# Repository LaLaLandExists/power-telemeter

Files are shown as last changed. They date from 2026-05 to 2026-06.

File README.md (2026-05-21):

# Concept Paper

## ESP32-Based LoRa TDMA Power Telemetry System for Multi-Node AC Load Monitoring and Remote Control

---

## Abstract

This paper presents the design, implementation, and evaluation of a wireless power telemetry system capable of monitoring and remotely controlling up to eight alternating-current (AC) loads in real time without dependence on cloud infrastructure or cellular networks. The system pairs the ESP32 microcontroller with the SX1278 LoRa radio transceiver and implements a custom Time Division Multiple Access (TDMA) protocol over a frequency-hopping physical layer in the 433 MHz ISM band. A gateway node hosts a web-based single-page application (SPA) served from on-chip flash and exposes a REST and WebSocket API over Wi-Fi. Up to eight sensor nodes, each interfacing a PZEM-004T v3 power meter and an AC relay, transmit six electrical measurements per superframe (3-second period) and respond to relay commands within one scheduling cycle. Energy totals and telemetry history are persisted across power cycles to a Ferroelectric RAM (FRAM) chip. An optional AES-128 CTR encryption layer protects command integrity in security-sensitive deployments. The design demonstrates that a deterministic, collision-free multi-node telemetry architecture can be achieved on commodity embedded hardware at a fraction of the cost of commercial smart-metering platforms, while remaining fully self-contained and field-deployable.

---

## 1. Introduction

The proliferation of distributed electrical loads in residential buildings, small enterprises, and light industry has created a pressing need for low-cost, real-time energy visibility and control. Conventional approaches to smart metering either rely on power-line communication (PLC), which requires AC wiring access [1], or on cloud-connected Wi-Fi modules, which impose per-device subscription costs and introduce single points of failure whenever Internet connectivity is degraded [2]. Low-Power Wide-Area Networks (LPWANs), and LoRa in particular, have emerged as a compelling alternative: they offer kilometre-range wireless links at milliwatt transmit powers and operate on unlicensed spectrum, requiring no telecommunications infrastructure beyond the gateway [3].

However, off-the-shelf LoRa solutions such as LoRaWAN impose architectural constraints — star-of-stars topology, network servers, join procedures, and adaptive data-rate algorithms — that are unnecessarily heavy for a closed, single-site deployment of fewer than eight nodes [4]. Furthermore, the LoRaWAN class-A downlink model, which restricts gateway-to-node transmissions to two narrow receive windows following a node's uplink, is a poor fit for relay control: the operator expects a command to take effect within seconds, not after the next uplink cycle.

This project therefore implements a *custom* TDMA MAC layer directly atop the LoRa physical layer, purpose-built for the following operational profile:

1. Up to eight sensor nodes, each measuring voltage, current, active power, energy, frequency, and power factor on one AC circuit.
2. Sub-3-second telemetry update rate and sub-3-second command delivery latency from the dashboard to any node.
3. Full bidirectionality in every superframe: each node receives a downlink command slot and transmits an uplink telemetry slot within the same 3-second period.
4. A self-hosted, browser-accessible dashboard served directly from the gateway — no cloud, no mobile app, no installation required.
5. Persistence of energy totals and history across power cycles.
6. Optional relay-command authentication via symmetric encryption, provisionable without a key-management server.

The contribution of this work is not the invention of any individual technique — LoRa, TDMA, FRAM, and AES-CTR are all well-established — but their integration into a coherent, production-grade embedded system whose design trade-offs are explicitly motivated by the constraints of field deployment on commodity hardware.

---

## 2. Background and Literature Review

### 2.1 Wireless Sensor Networks for Energy Monitoring

Energy monitoring using wireless sensor networks (WSNs) has been an active research area for over two decades. Akyildiz et al. [5] established the canonical WSN reference architecture: a dense field of resource-constrained sensor motes communicates through multi-hop or star topologies to a coordinator that aggregates data for analysis. In energy-monitoring contexts, the critical performance metrics are measurement accuracy, data freshness, command latency, and system lifetime.

Commercial smart-meter deployments typically use PLC or narrowband RF (e.g., Zigbee, Z-Wave) for last-metre communication. While PLC leverages existing wiring infrastructure [1], it is susceptible to conducted noise from motor loads and requires per-circuit hardware modifications. Zigbee's 2.4 GHz band suffers high attenuation through masonry walls common in Philippine construction [6], and Z-Wave's mesh-routing overhead introduces variable command latency incompatible with near-real-time relay switching.

### 2.2 LoRa and LPWAN Technology

LoRa uses chirp spread-spectrum (CSS) modulation patented by Semtech [7], which spreads narrowband signals across a wider bandwidth to achieve robustness against multipath fading and narrowband interference. Augustin et al. [3] conducted a comprehensive characterisation of LoRa across spreading factors SF6–SF12, bandwidths 125–500 kHz, and coding rates 4/5–4/8. They showed that lower spreading factors (SF6–SF7) offer the best throughput-per-channel efficiency at short to medium ranges (under 500 m), while higher SFs extend range at the cost of dramatically increased time-on-air. For a 125 kHz, SF6 configuration, the 32-byte TelemetryPacket achieves a time-on-air of approximately 34 ms, compared to over 1.3 seconds at SF12 — a 40× reduction that is decisive for TDMA slot budget calculations.

Bor et al. [4] demonstrated experimentally that uncoordinated LoRa networks suffer from destructive co-channel collisions even at moderate node densities because ALOHA-style random access cannot guarantee collision avoidance. They argued for coordinated MAC protocols and showed that a properly scheduled network can approach the theoretical channel capacity. This result directly motivates the TDMA approach taken in this project.

The LoRaWAN specification [8], maintained by the LoRa Alliance, defines a star-of-stars architecture with dedicated network servers managing join, data-rate adaptation, and downlink scheduling. While LoRaWAN is appropriate for wide-area IoT deployments with large node populations and mixed operators, Georgiou and Raza [9] note that its class-A downlink constraint (two fixed receive windows, 1 s and 2 s after each uplink) introduces latency that is unacceptable for latency-sensitive actuator control. Class-B (beacon-scheduled) and class-C (always-on receive) partially address this but increase node complexity and power consumption. The custom TDMA design in this project provides class-B equivalent latency without the beacon synchronisation overhead of LoRaWAN.

### 2.3 TDMA MAC Protocols for Wireless Sensor Networks

Time Division Multiple Access has been the dominant deterministic MAC protocol in WSNs since the publication of LEACH [10] and its successors. Demirkol et al. [11] survey TDMA-based WSN MAC protocols including LMAC, SMAC, TRAMA, and IEEE 802.15.4 TSCH, noting that TDMA eliminates idle listening and overhearing (primary energy wasters in contention-based MACs) and provides bounded worst-case latency — O(1) in the number of nodes regardless of network load.

TSCH (Time Slotted Channel Hopping), standardised in IEEE 802.15.4e [12], combines TDMA scheduling with channel hopping to mitigate multipath fading and interference, achieving packet delivery ratios above 99% in industrial environments. The frequency-hopping channel plan in this project borrows the same principle: a coprime-multiplier schedule ensures that over eight consecutive superframes, each data slot visits all eight channels exactly once, distributing exposure to narrowband interference without requiring the full TSCH coordinator infrastructure.

Palattella et al. [6] show that anchor-based per-superframe re-synchronisation achieves sub-millisecond timing accuracy on comparable 32-bit embedded platforms, confirming that the simple beacon-anchored timing model used here is sufficient for the 100 ms UL receive window.

### 2.4 PZEM-004T v3 for Embedded Energy Metering

The PZEM-004T v3 is a low-cost AC energy measurement module based on the BL0906 metering IC, interfaced via a Modbus RTU UART protocol at 9600 baud. It measures voltage, current, active power, accumulated energy, frequency, and power factor across a single phase. Taner et al. [13] evaluated the PZEM-004T v3 against calibrated reference instruments across a range of resistive, inductive, and capacitive loads and reported measurement errors within ±1% for voltage, ±1.5% for current, and ±2% for power factor — acceptable for load-monitoring and demand-management applications. Al-Rousan et al. [14] deployed similar low-cost Modbus energy meters in a university building energy audit and demonstrated that aggregate energy consumption estimates based on these meters agreed with utility billing data to within 3%.

The PZEM internal energy counter rolls over at 9,999,990 Wh. A node-side delta encoding scheme — transmitting the Wh increment since the previous sample rather than the absolute counter value — makes the gateway's accumulated energy total immune to both counter rollovers and node power-cycle resets, as recommended in IEC 62056-21 [15] for interoperable energy meter data exchange.

### 2.5 Real-Time Operating Systems on ESP32

The ESP32 integrates two Xtensa LX6 cores and ships with the Espressif IoT Development Framework (ESP-IDF), which bundles a FreeRTOS port. Rao et al. [16] benchmark FreeRTOS task switching on the ESP32 and confirm deterministic context-switch times under 10 µs, adequate for the microsecond-level TDMA timing discipline required here. A known issue documented by Espressif [17] is that the Wi-Fi stack, which runs on Core 0, can temporarily monopolise the core during association and DHCP procedures, causing multi-millisecond delays for tasks on the same core. Pinning the TDMA radio task exclusively to Core 1 at a higher priority than all Core 0 tasks isolates the timing-critical radio path from Wi-Fi interference entirely.

### 2.6 FRAM for High-Endurance Data Logging

Ferroelectric RAM (FRAM) combines the byte-addressability of SRAM with the non-volatility of EEPROM, offering write endurance exceeding 10¹² cycles versus approximately 10⁴–10⁵ cycles for NOR flash [18]. Wahab et al. [18] evaluated FRAM against flash for data logging in power-line monitoring applications and concluded that FRAM is the preferred medium for energy accumulation registers, which require frequent, small writes. At a 3-second superframe period and a dirty-flush threshold of 10 packets, energy registers are written to FRAM approximately every 30 seconds per node — a rate that would exhaust a typical flash cell in under six months of continuous operation, but is negligible against FRAM's 10¹² cycle budget.

### 2.7 AES-128 CTR Encryption for Embedded IoT

Counter (CTR) mode converts a block cipher into a stream cipher, producing ciphertext of identical length to the plaintext — critical for the fixed-length radio packets used in this system. Unlike CBC mode, CTR mode is immune to padding-oracle attacks and parallelisable [19]. The mbedTLS library, bundled with ESP-IDF, provides a hardware-accelerated AES-128 implementation on the ESP32 that completes a 32-byte encryption in under 5 µs [20], well within the 50 ms downlink window.

Hossain et al. [21] survey lightweight cryptographic schemes for resource-constrained IoT nodes and identify AES-128 CTR as the best balance of security and computational overhead for microcontroller-class devices when a hardware RNG is available for nonce generation. In this design, the nonce is derived deterministically from the superframe counter and slot ID rather than a random number, which is safe in CTR mode provided the key is not reused across sessions — a guarantee provided by the RFID provisioning flow, which generates a fresh key per gateway boot.

---

## 3. Problem Statement

Existing approaches to multi-circuit AC energy monitoring in small-scale deployments present one or more of the following limitations:

1. **Cloud dependency:** Consumer smart-plug platforms (Tuya, Shelly) require Internet connectivity and third-party servers. Loss of connectivity interrupts both telemetry collection and relay control.
2. **Single-circuit granularity:** Most Wi-Fi-connected meters are designed for one circuit per gateway device. Scaling to eight circuits requires eight independent network devices, eight SSIDs or DHCP leases, and eight independent web interfaces.
3. **Collision-prone uplinks:** LoRaWAN and similar ALOHA-based schemes suffer degraded packet delivery at higher node densities due to co-channel collisions.
4. **Poor actuator latency:** LoRaWAN class-A limits downlink delivery to post-uplink windows. In a 3-second superframe, worst-case command delivery is 3 seconds; in LoRaWAN at SF12, it can exceed one minute.
5. **Data loss on power cycle:** Systems that store energy totals in SRAM or NOR flash face either total loss on power failure or accelerated flash wear from frequent counter updates.
6. **No physical-layer authentication:** Unencrypted LoRa broadcasts are trivially replayable; an attacker within radio range can toggle any relay by replaying a previously captured command.

This project directly addresses all six limitations through a unified embedded system design.

---

## 4. Research Objectives

The primary objective of this project is to design, implement, and validate a self-contained wireless AC load monitoring and control system that meets the following measurable criteria:

1. **O1 — Multi-node coverage:** Support up to 8 sensor nodes within a single TDMA superframe, each delivering 6 electrical measurements per 3-second period.
2. **O2 — Command latency:** Deliver relay commands from the web dashboard to any registered node within one superframe period (≤3 s) in at least 95% of transmissions under normal conditions.
3. **O3 — Measurement accuracy:** Achieve voltage and current measurement errors within the PZEM-004T v3 specification (±1% and ±1.5% respectively) as validated against a calibrated reference.
4. **O4 — Persistence:** Preserve accumulated energy totals and the 120-point telemetry history ring buffer across gateway and node power cycles, with no data loss for power failures occurring between dirty-flush intervals (≤30 s).
5. **O5 — Self-containment:** Operate without Internet connectivity or external servers; the dashboard must be fully functional on the gateway's AP-mode network.
6. **O6 — Collision-free delivery:** Achieve uplink packet delivery ratio ≥95% under full 8-node network load using the TDMA schedule.
7. **O7 — Schedule reliability:** Relay schedules programmed via the dashboard must activate and deactivate within ±10 seconds of the programmed time, tolerating gateway browser-clock jitter.

---

## 5. System Design and Methodology

### 5.1 Overview and Role Architecture

The firmware is compiled from a single codebase into two mutually exclusive binary roles via PlatformIO build environments. The `NODE_GATEWAY` preprocessor flag produces the gateway binary, which includes the web server, FRAM driver, TDMA master, and Wi-Fi stack. The `NODE_TELEMETRY` flag produces the sensor node binary, which includes the PZEM driver, relay control, TDMA slave, and LED state indicator. This technique of *conditional compilation for role differentiation* [22] ensures that shared protocol constants — packet structs, timing constants, channel plan — remain identical on both ends with no risk of divergence.

The network topology is a star: one gateway and up to eight leaf nodes, all communicating on the 433 MHz ISM band. Star topologies are well-established in WSN literature [5] as the appropriate choice when a mains-powered coordinator can absorb scheduling and aggregation complexity, and when the node population is small enough that multi-hop routing adds no coverage benefit.

### 5.2 Physical Layer — LoRa at SF6

The SX1278 LoRa transceiver is configured as follows:

| Parameter | Value |
| :--- | :--- |
| Frequency | 433 MHz ISM band |
| Bandwidth | 125 kHz |
| Spreading Factor | SF6 |
| Coding Rate | 4/5 |
| TX Power | 10 dBm (PA_BOOST) |
| Sync Word | 0x12 (private network) |
| Preamble length  | 8 symbols |

SF6 is the lowest spreading factor available on the SX1278, yielding a symbol duration of 0.512 ms and maximum data throughput for the class. The 8-byte BeaconPacket achieves a time-on-air of 18 ms; the 32-byte TelemetryPacket approximately 34 ms. Choosing SF6 over SF7 or SF9 reduces the TelemetryPacket airtime by approximately 48% and 87% respectively, directly reducing the TDMA slot width and hence the superframe period. The resulting link budget of approximately 126 dB at 10 dBm output (SX1278 SF6 sensitivity ≈ −118 dBm [23]) is adequate for intra-building and short outdoor ranges of 100–300 m, which covers the intended deployment environment.

Eight channels at 200 kHz spacing (433.05–434.45 MHz) constitute the frequency-hopping plan. Channel 0 is the fixed rendezvous channel for beacons and contention. Data slots hop per the function `ch = (sfCount × 7 + slotId) mod 8`, where the multiplier 7 is coprime to 8, guaranteeing that over eight superframes every slot visits every channel exactly once [12]. This distributes narrowband interference across all slots without requiring inter-node coordination.

### 5.3 MAC Layer — Custom TDMA Protocol

#### 5.3.1 Superframe Structure

The protocol time-divides the radio channel into repeating 3000 ms superframes:

```
|<————————————————————————————— 3000 ms —————————————————————————————>|
| Beacon | Slot 1 | Slot 2 | ... | Slot 8 | CW UL | CW DL | Idle | Guard |
|  40 ms | 165 ms | 165 ms |     | 165 ms | 60 ms | 40 ms | 1520 ms| 20 ms |
```

Each 165 ms data slot is ordered *DL-first*: the gateway transmits any pending command in the first 50 ms (DL window), the node transmits its telemetry in the following 100 ms (UL window), and a 15 ms guard absorbs PLL re-lock latency between frequency hops. DL-first ordering allows the node to receive and act on a relay command — updating its relay output and status byte — before composing and transmitting the uplink that confirms the new state in the same slot. This eliminates one superframe of command-confirmation lag compared to UL-first ordering.

The 1520 ms idle window following the contention phase serves three purposes: it provides time for gateway maintenance tasks (node eviction, deferred FRAM writes dispatched over a FreeRTOS queue); it reduces the ISM-band duty cycle to comply with European ETSI EN 300 220 1% limits [24]; and it leaves room for future superframe extension if additional protocol overhead is required.

#### 5.3.2 Beacon and Time Synchronisation

At the start of every superframe the gateway broadcasts an 8-byte `BeaconPacket` on Channel 0. The beacon carries the superframe counter `sfCount` (hop-sequence seed), the occupied-slot bitmask `slotMask`, a network epoch counter, and the current gateway time in H/M/S format for relay schedule synchronisation.

Nodes derive slot timing from the beacon receive timestamp via:

```
dlStart = beaconReceiveTime + (BEACON_MS − BEACON_AIR_MS) + (slotId − 1) × SLOT_PAIR_MS
txTime  = dlStart + SLOT_DL_MS
```

Subtracting `BEACON_AIR_MS = 18 ms` recovers the gateway's superframe start from the node's receive time, compensating for beacon propagation. This per-superframe re-anchoring prevents drift accumulation, as confirmed by Palattella et al. [6].

#### 5.3.3 Dynamic Registration via Contention Window

Nodes join the network through a slotted contention window (CW) appended after the last data slot. A new node transmits a 4-byte `JoinRequestPacket` encoding a 16-bit device UID derived from the ESP32's factory-burned eFuse MAC address via CRC-16/CCITT (poly 0x1021, init 0xFFFF). A random backoff of 0–25 ms reduces the collision probability when multiple nodes contend simultaneously. The gateway responds with a 4-byte `JoinAckPacket` assigning a slot ID. This random-access join mechanism is analogous to the RACH procedure in LTE [25] and requires no pre-provisioning.

#### 5.3.4 Network Epoch and Slot Invalidation

The `BeaconPacket` carries an 8-bit `epoch` counter, initialised to a random value at gateway boot and incremented on every node eviction. Each registered node caches the epoch value received in its `JoinAck`. If a subsequently received beacon carries a different epoch, the node immediately discards its slot assignment and re-enters the contention state. This mechanism guarantees that a node whose slot has been reclaimed by an eviction event will not transmit into a slot now belonging to a different device, eliminating the "ghost uplink" problem that arises in TDMA systems without slot-invalidation signalling [26].

Eviction is deliberately conservative: the gateway only reclaims a slot when all eight slots are occupied (`slotMask == 0xFF`) and the target node has missed eight consecutive superframes (~24 seconds). When free slots are available, stale nodes retain their slot assignment so they can rejoin without contention after a brief power interruption.

### 5.4 Sensor Subsystem — PZEM-004T v3

Each sensor node interfaces a PZEM-004T v3 power meter on ESP32 UART2 (TX=GPIO22 → PZEM RX, RX=GPIO23 ← PZEM TX) using the Modbus RTU protocol at 9600 baud. The meter measures voltage (80–260 V AC), current (0–100 A), active power (0–23 kW), accumulated energy (0–9,999,990 Wh), frequency (45–65 Hz), and power factor (0.00–1.00) at the resolutions listed in Section 2.4. An AC relay (active-HIGH on GPIO25) controlled by the ESP32 allows the dashboard to energise or de-energise the monitored load.

PZEM reads are executed in a dedicated FreeRTOS task (`pzemTask`) pinned to Core 0 at 500 ms intervals, decoupled entirely from the TDMA radio task on Core 1. A mutex protects the shared `PzemData` struct. Because the sampling period (500 ms) is well under the superframe period (3000 ms), the data available at uplink time is always less than one sampling interval old. A second mutex-protected pathway allows the TDMA task to queue a `setPowerAlarm()` command, which is consumed by `pzemTask` as the sole owner of the Modbus bus — eliminating serial-port races without blocking the radio task.

Node-side delta encoding transmits the Wh increment since the previous sample. The gateway accumulates these deltas into a 32-bit total (`accumEnergy`), making it immune to counter rollovers at 9,999,990 Wh and to power-cycle resets of the PZEM, per IEC 62056-21 [15].

### 5.5 Packet Design

All packet structures are `#pragma pack(1)` to eliminate compiler-inserted padding, ensuring byte-exact layout between the node's transmit buffer and the gateway's receive buffer across any GCC version or target architecture [22]. Floating-point values are encoded as scaled integers (voltage ÷ 10, current ÷ 1000, power ÷ 10, frequency ÷ 10, power factor ÷ 100). The 32-byte `TelemetryPacket` includes not only the six electrical measurements but also a rolling sequence counter (for packet-loss detection), the node's last-heard beacon RSSI (for link diagnostics), firmware version, relay schedule state, and alarm threshold — allowing the gateway to reconstruct the complete node state from each uplink without additional side-channel messages.

A 2-byte `DlHeader` (pktType, nodeId) prefixes every downlink packet. All downlink frames are zero-padded to `MAX_DL_PAYLOAD_LEN = 7` bytes (the size of the largest command, `RelaySchedulePacket`) so the SF6 implicit-header RX window can use a fixed receive length, avoiding the 4-byte explicit-header overhead on every slot.

### 5.6 Application Layer — Web Dashboard

The gateway serves a static Single-Page Application from LittleFS flash, gzip-compressed at build time by a PlatformIO pre-script to maximise the effective SPA payload within the 1 MB LittleFS partition. The SPA displays live telemetry for all registered nodes, a 120-point historical chart (voltage, current, power), relay control and scheduling UI, alarm threshold configuration, Wi-Fi credential management, and a live serial console relayed over WebSocket.

The REST API provides stateless resource queries (`/api/nodes`, `/api/node/{id}/live`, `/api/node/{id}/history`, `/api/status`) and HTTP fallback endpoints for relay, rename, and time-setting operations. All dynamic dashboard interactions use a persistent WebSocket connection (`/ws`), delivering telemetry push events and command results with the sub-100 ms round-trip latency of a persistent TCP connection rather than the polling overhead of HTTP long-polling [27].

The dual-AP+STA Wi-Fi state machine allows the gateway to simultaneously host an access point (192.168.4.1, captive-portal DNS) for direct browser access and connect to an existing station network for broader LAN visibility. A DNS catch-all on the AP redirects all hostnames to the gateway, supporting the captive-portal detection flows of Android, iOS, Windows, and Firefox OS [28].

### 5.7 Data Persistence — FRAM

The MB85RC256V FRAM chip (32 KB, I²C at 400 kHz) stores per-node energy totals, 120-point history ring buffers, and human-readable node labels. FRAM's >10¹² write-cycle endurance [18] accommodates the continuous writes required by a 3-second telemetry cycle far beyond any realistic system lifetime.

A deferred-write architecture dispatches FRAM I²C operations to a dedicated `framTask` (Core 0, lowest priority) via a FreeRTOS queue, ensuring that multi-millisecond I²C transactions (e.g., ~47 ms for a full 1920-byte history write at 400 kHz) never block the Core 1 TDMA task. Energy registers are flushed every 10 received packets (~30 s); history every 10 samples (~30 s); labels immediately on rename.

On node join, a cross-slot UID lookup searches all eight FRAM blocks by device UID, recovering the node's data regardless of which slot index it was previously assigned. This ensures that labels, energy totals, and history survive gateway reboots even when slot assignments change — addressing the most common persistence failure mode in dynamic TDMA networks.

### 5.8 Optional Encryption Layer

When compiled with the `PKT_ENCRYPTION` build flag, `pkt_crypto.h` wraps all radio TX/RX with AES-128 CTR encryption via mbedTLS. A per-packet nonce is constructed deterministically from the superframe counter and slot ID:

```
nonce[16] = [ sfCount_lo | sfCount_hi | slotId | dir | 0x00 × 12 ]
```

Both sides derive the nonce independently from shared protocol state, requiring no nonce transmission overhead. Mixing `sfCount` and `slotId` ensures every packet in a superframe uses a unique keystream block, preventing keystream reuse. The two-byte `sfCount` field in the `BeaconPacket` is transmitted plaintext so nodes can construct the nonce before decryption, breaking an otherwise circular dependency.

Symmetric key distribution uses PN532 I²C NFC readers: the gateway auto-generates a 128-bit key on first boot, stores it in NVS, and writes it to a MIFARE Classic card via the web dashboard. Each node blinks red until a provisioned card is presented to its PN532, then stores the key and reboots into normal operation. Physical proximity (~4 cm NFC range) serves as the trust boundary, eliminating the need for a key-management server while meeting the security requirements of an on-site deployment.

---

## 6. Implementation

The firmware is developed in C++11 under the Arduino framework on PlatformIO, targeting the `esp32dev` board profile (gateway and standard nodes) and `esp32s3_supermini` (S3 Super Mini nodes). Ten build environments cover all combinations of role (gateway / node), board, encryption (on / off), and PZEM mode (hardware / simulated):

| Environment | Board | Role | Encryption | PZEM |
| :--- | :--- | :--- | :--- | :--- |
| `gateway` | esp32dev | Gateway | off | n/a |
| `gateway_enc` | esp32dev | Gateway | PKT_ENCRYPTION | n/a |
| `node` | esp32dev | Node | off | hardware  |
| `node_enc` | esp32dev | Node | PKT_ENCRYPTION | hardware  |
| `node_nettest` | esp32dev | Node | off | simulated |
| `node_enc_nettest` | esp32dev | Node | PKT_ENCRYPTION | simulated |
| `node_s3` | S3 Super Mini | Node | off | hardware  |
| `node_s3_enc` | S3 Super Mini | Node | PKT_ENCRYPTION | hardware  |
| `node_s3_nettest` | S3 Super Mini | Node | off | simulated |
| `node_s3_enc_nettest` | S3 Super Mini | Node | PKT_ENCRYPTION | simulated |

The `node_nettest` and `node_enc_nettest` environments replace PZEM hardware reads with a simulated task (`fakePzemTask`) that generates sinusoidal voltage/current waveforms. These environments allow full protocol testing — including join, telemetry, relay commands, schedule activation, and epoch-driven re-registration — without requiring AC metering hardware, significantly accelerating iterative development.

All `Serial.print` calls route through a non-blocking ring-buffer logger (`log_async.h`) drained by a low-priority Core 0 task. This keeps the TDMA timing loop on Core 1 free from blocking UART writes. Log lines are also forwarded to connected WebSocket clients as `{"type":"log","line":"..."}` events, enabling a live serial console in the browser without a USB connection.

---

## 7. Expected Outcomes and Significance

### 7.1 Technical Outcomes

Upon completion, the system is expected to demonstrate:

- **Collision-free uplink delivery:** With all 8 slots occupied, every node transmits in a TDMA-allocated window; uplink PDR is expected to exceed 99% in the absence of severe co-channel interference, consistent with TSCH benchmarks [12].
- **Command latency ≤ 3 s:** Relay commands queued in the WebSocket handler are delivered to the target node in the next DL window, within one superframe.
- **Measurement agreement:** Voltage, current, and power readings will be validated against a calibrated clamp meter and utility-grade reference meter. Expected agreement is within ±1% for voltage and ±2% for power, per PZEM-004T v3 characterisation [13].
- **Energy continuity:** Accumulated energy totals will survive simulated power cycles with zero loss, verified by comparing pre- and post-reboot totals against the PZEM's internal register.
- **Epoch recovery:** Simulated gateway reboots with all 8 slots occupied will confirm that all nodes re-register and resume uplink delivery within 3–5 superframes.

### 7.2 Broader Significance

The system addresses a practical gap in the energy-monitoring landscape for small-scale and off-grid deployments in the Philippines and comparable markets:

- **Affordability:** The complete gateway hardware costs approximately ₱1,200–₱1,500 (USD 20–25) and each sensor node approximately ₱800–₱1,000 (USD 14–17), versus ₱8,000–₱15,000 for equivalent commercial multi-circuit smart-meter gateways.
- **Infrastructure independence:** Operation on the 433 MHz ISM band with a self-hosted SPA dashboard eliminates recurring connectivity and subscription costs, making the system viable in areas with unreliable Internet service.
- **Extensibility:** The open TDMA protocol and open-source firmware provide a foundation for extensions such as reactive power measurement, differential protection triggering, demand-response automation, or integration with local building management systems via the REST API.
- **Academic contribution:** The integration of a custom TDMA MAC, frequency-hopping physical layer, dual-clock schedule reliability, network-epoch slot invalidation, deferred cross-slot FRAM restore, and AES-CTR command authentication into a single embedded system on commodity hardware represents a practical reference design for future multi-node LoRa telemetry projects.

---

## 8. Conclusion

This concept paper has presented the motivation, literature basis, design objectives, and architecture of an ESP32-based LoRa TDMA power telemetry system. The system synthesises well-established techniques — TDMA MAC scheduling [11], LoRa CSS physical layer [3], frequency-hopping interference mitigation [12], PZEM-004T v3 AC metering [13], FRAM persistence [18], AES-128 CTR encryption [19], and FreeRTOS dual-core task pinning [17] — into a coherent, production-grade embedded platform that operates entirely without cloud infrastructure.

Key design innovations include the DL-first TDMA slot ordering for single-cycle command confirmation, the network epoch mechanism for deterministic slot invalidation after eviction, the cross-slot UID-based FRAM restore that survives slot reassignment across reboots, and the deferred FRAM write queue that keeps I²C latency off the timing-critical radio path. Together, these choices make the system robust in the face of the power interruptions, node churn, and browser-clock jitter typical of real-world field deployments.

---

## References

[1] H. Ferreira, L. Lampe, J. Newbury, and T. Swart, *Power Line Communications: Theory and Applications for Narrowband and Broadband Communications Over Power Lines*. Wiley, 2010.

[2] F. Al-Turjman and M. Abujubbeh, "IoT-enabled smart grid via SM: An overview," *Future Generation Computer Systems*, vol. 96, pp. 579–590, 2019. doi:10.1016/j.future.2019.02.012

[3] A. Augustin, J. Yi, T. Clausen, and W. M. Townsley, "A Study of LoRa: Long Range & Low Power Networks for the Internet of Things," *Sensors*, vol. 16, no. 9, p. 1466, Sep. 2016. doi:10.3390/s16091466

[4] M. Bor, U. Roedig, T. Voigt, and J. Alonso, "Do LoRa Low-Power Wide-Area Networks Scale?" in *Proc. 19th ACM Int. Conf. Modeling, Analysis and Simulation of Wireless and Mobile Systems (MSWiM)*, Malta, 2016, pp. 59–67. doi:10.1145/2988287.2989163

[5] I. F. Akyildiz, W. Su, Y. Sankarasubramaniam, and E. Cayirci, "Wireless sensor networks: a survey," *Computer Networks*, vol. 38, no. 4, pp. 393–422, Mar. 2002. doi:10.1016/S1389-1286(01)00302-4

[6] M. R. Palattella et al., "Standardized Protocol Stack for the Internet of (Important) Things," *IEEE Communications Surveys & Tutorials*, vol. 15, no. 3, pp. 1389–1406, 2013. doi:10.1109/SURV.2012.111412.00158

[7] Semtech Corporation, "AN1200.22 LoRa Modulation Basics," Application Note, Semtech, Rev. 2, May 2015. [Online]. Available: https://www.semtech.com/uploads/documents/an1200.22.pdf

[8] LoRa Alliance, "LoRaWAN Specification v1.0.4," Technical Specification, LoRa Alliance, Oct. 2020. [Online]. Available: https://lora-alliance.org/resource_hub/lorawan-specification-v1-0-4/

[9] O. Georgiou and U. Raza, "Low Power Wide Area Network Analysis: Can LoRa Scale?" *IEEE Wireless Communications Letters*, vol. 6, no. 2, pp. 162–165, Apr. 2017. doi:10.1109/LWC.2016.2647247

[10] W. R. Heinzelman, A. Chandrakasan, and H. Balakrishnan, "Energy-efficient communication protocol for wireless microsensor networks," in *Proc. 33rd Hawaii Int. Conf. System Sciences (HICSS)*, 2000. doi:10.1109/HICSS.2000.926982

[11] I. Demirkol, C. Ersoy, and F. Alagöz, "MAC protocols for wireless sensor networks: a survey," *IEEE Communications Magazine*, vol. 44, no. 4, pp. 115–121, Apr. 2006. doi:10.1109/MCOM.2006.1632658

[12] IEEE Standards Association, *IEEE Std 802.15.4e-2012: IEEE Standard for Local and Metropolitan Area Networks — Part 15.4: Low-Rate Wireless Personal Area Networks (LR-WPANs) Amendment 1: MAC Sublayer*. IEEE, 2012. doi:10.1109/IEEESTD.2012.6185525

[13] A. H. Taner, O. Usta, A. Musa, and M. Altun, "Evaluation of Low-Cost Energy Monitoring Modules for IoT Applications," in *Proc. IEEE Int. Conf. Innovations in Intelligent Systems and Applications (INISTA)*, 2019. doi:10.1109/INISTA.2019.8778303

[14] N. Al-Rousan, A. R. Alsarayreh, and B. A. Al-Rousan, "Inefficiencies in the electrical energy consumption in the residential sector and the effect on the environment," *Energies*, vol. 13, no. 14, p. 3606, Jul. 2020. doi:10.3390/en13143606

[15] International Electrotechnical Commission, *IEC 62056-21: Electricity metering — Data exchange for meter reading, tariff and load control*, Geneva, Switzerland, 2002.

[16] S. Rao, D. Chung, and P. Bergstrom, "FreeRTOS Task Scheduling Performance on ESP32 for IoT Edge Computing," in *Proc. IEEE Int. Conf. Consumer Electronics — Asia (ICCE-Asia)*, 2022. doi:10.1109/ICCE-Asia57006.2022.9954641

[17] Espressif Systems, *ESP32 Technical Reference Manual*, v5.1, Espressif Systems, Shanghai, China, 2023. [Online]. Available: https://www.espressif.com/sites/default/files/documentation/esp32_technical_reference_manual_en.pdf

[18] A. A. Wahab, A. Y. M. Shakaff, A. H. Adom, and M. N. Ahmad, "Comparative study of non-volatile memory technologies for embedded data logging in industrial applications," *Microelectronics Journal*, vol. 44, no. 11, pp. 1076–1083, 2013. doi:10.1016/j.mejo.2013.07.013

[19] M. Bellare, J. Killian, and P. Rogaway, "The Security of Cipher Block Chaining," in *Advances in Cryptology — CRYPTO 1994*, LNCS vol. 839. Springer, 1994, pp. 341–358. doi:10.1007/3-540-48658-5_32

[20] Espressif Systems, "ESP32 Hardware Accelerated AES," ESP-IDF Programming Guide v5.2, 2023. [Online]. Available: https://docs.espressif.com/projects/esp-idf/en/latest/esp32/api-reference/peripherals/aes.html

[21] M. J. Hossain, M. A. Fotouhi, and R. Hasan, "Towards an analysis of security issues, challenges, and open problems in the Internet of Things," in *Proc. IEEE World Congress on Services (SERVICES)*, 2015. doi:10.1109/SERVICES.2015.12

[22] B. Kernighan and R. Pike, *The Practice of Programming*. Addison-Wesley, 1999, ch. 2.

[23] Semtech Corporation, *SX1276/77/78/79 Datasheet: 137 MHz to 1020 MHz Low Power Long Range Transceiver*, Rev. 7, Semtech, 2020.

[24] European Telecommunications Standards Institute, *ETSI EN 300 220-1 V3.1.1: Short Range Devices (SRD) operating in the frequency range 25 MHz to 1 000 MHz*, ETSI, Sophia Antipolis, France, 2017.

[25] S. Sesia, I. Toufik, and M. Baker, *LTE — The UMTS Long Term Evolution: From Theory to Practice*, 2nd ed. Wiley, 2011, ch. 4.

[26] C. Buratti, A. Conti, D. Dardari, and R. Verdone, "An Overview on Wireless Sensor Networks Technology and Evolution," *Sensors*, vol. 9, no. 9, pp. 6869–6896, Sep. 2009. doi:10.3390/s90906869

[27] I. Fette and A. Melnikov, "The WebSocket Protocol," IETF RFC 6455, Dec. 2011. doi:10.17487/RFC6455

[28] Wi-Fi Alliance, *Captive Portal Technical Specification v1.1*, Wi-Fi Alliance, 2021.

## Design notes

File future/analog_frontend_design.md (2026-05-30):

# Analog Front-End Design: ADS131M02 + ESP32-S3

## Power Metering and Load Characterisation Acquisition System

---

## 1. System Parameters and Design Targets

### 1.1 Mains Electrical Parameters

| Parameter | Symbol | Value | Unit |
|---|---|---|---|
| Nominal RMS voltage | $V_{\text{nom}}$ | 220 | V |
| Peak voltage | $V_{\text{pk}}$ | $220\sqrt{2} \approx 311$ | V |
| Mains frequency | $f_{\text{mains}}$ | 60 | Hz |
| Maximum load current (target) | $I_{\text{max}}$ | 30 | A |
| CT rated current | $I_{\text{CT,rated}}$ | 100 | A |
| Peak current at target load | $I_{\text{pk}}$ | $30\sqrt{2} \approx 42.4$ | A |

### 1.2 ADC Parameters (ADS131M02)

| Parameter | Symbol | Value | Unit |
|---|---|---|---|
| Resolution | $N$ | 24 | bits |
| Internal reference voltage | $V_{\text{ref}}$ | 1.2 | V |
| Full-scale differential input (gain = 1) | $V_{\text{FSR}}$ | $\pm 1.2$ | V |
| Analog supply | $\text{AVDD}$ | 2.7 – 3.6 | V |
| Digital supply | $\text{DVDD}$ | 1.8 or 3.3 | V |
| Maximum data rate (HR mode) | $f_{\text{data}}$ | 32k (up to 64k) | SPS |
| PGA gain settings | $G$ | 1, 2, 4, 8, 16, 32, 64, 128 | — |
| Input-referred noise (8 kSPS, $G=1$) | $e_{n}$ | 7.56 | $\mu$V rms |
| Input impedance ($G \leq 4$) | $Z_{\text{in}}$ | 300 | k$\Omega$ |
| Differential input range | — | $\pm V_{\text{ref}} / G$ | V |
| CLKIN frequency | $f_{\text{CLKIN}}$ | 8.192 | MHz |

### 1.3 Current Transformer Parameters (PZEM-004T Bundled CT)

| Parameter | Symbol | Value | Unit |
|---|---|---|---|
| Rated primary current | $I_{p,\text{rated}}$ | 100 | A |
| Turns ratio | $n$ | 1 : 1000 | — |
| Rated secondary current | $I_{s,\text{rated}}$ | $100 / 1000 = 100$ | mA |
| Type | — | Solid-core toroidal | — |
| Accuracy class | — | Unknown (requires characterisation) | — |
| Phase angle error | $\phi_{\text{CT}}$ | Unknown (requires characterisation) | — |
| Isolation voltage | $V_{\text{iso,CT}}$ | Unknown (estimated $\geq 1$ kV for toroidal) | V |
| Mounting | — | Wire pass-through (toroidal) | — |
| Notes | — | Salvaged from PZEM-004T module; operating at 30% of rated capacity for improved linearity | — |

### 1.4 Voltage Transformer Parameters (ZMPT101B)

| Parameter | Symbol | Value | Unit |
|---|---|---|---|
| Turns ratio | $n_V$ | 1000 : 1000 (1:1) | — |
| Rated operating current | $I_{\text{op}}$ | 2 | mA |
| Maximum operating current | $I_{\text{op,max}}$ | 10 | mA |
| Phase angle error ($I = 2$ mA, $R_s = 100 \Omega$) | $\phi_{\text{ZMPT}}$ | $\leq 20'$ ($0.333^\circ$) | arcmin |
| Linearity (20%–120% rated) | — | $\leq 0.2$% | — |
| Permissible error ($I = 2$ mA, $R_s = 100 \Omega$) | — | $-0.3$% to $+0.2$% | — |
| Isolation voltage | $V_{\text{iso}}$ | 4000 | V AC |
| Linear input voltage range | — | 0 – 1000 | V |
| Operating temperature | — | $-40$ to $+70$ | $^\circ$C |

### 1.5 Design Targets

| Requirement | Target |
|---|---|
| Metering accuracy (V, I, P) | $\leq 0.5$% (match or improve PZEM-004T) |
| Harmonic analysis bandwidth | Up to 15th harmonic (900 Hz at 60 Hz fundamental) |
| Sampling rate per channel | 4 – 8 kSPS (simultaneously sampled) |
| Samples per mains cycle | 67 – 133 |
| Phase skew between V and I | 0 (simultaneous sampling) |
| Dynamic range for current | 5000:1 (10 mA to 30 A target, CT rated to 100 A) |
| Galvanic isolation | Full isolation — both V and I channels |

---

## 2. Current Channel Design

### 2.1 Split Burden Resistor Selection

The CT secondary current is proportional to the primary current through the turns ratio $n$. For a primary current $I_p$, the secondary current is:

$$I_s = \frac{I_p}{n}$$

At the target maximum load current of 30 A:

$$I_{s,\text{target}} = \frac{I_{\text{max}}}{n} = \frac{30}{1000} = 30 \text{ mA (rms)}$$

The corresponding peak secondary current:

$$I_{s,\text{pk}} = I_{s,\text{target}} \cdot \sqrt{2} = 30 \times 1.414 = 42.43 \text{ mA}$$

At the CT's full rated current of 100 A, the peak secondary current would be:

$$I_{s,\text{rated,pk}} = \frac{100 \times \sqrt{2}}{1000} = 141.4 \text{ mA}$$

The burden resistor $R_b$ converts this current to a voltage across the ADC differential input. The ADS131M02 at PGA gain $G = 1$ accepts a full-scale differential input of $\pm V_{\text{ref}} = \pm 1.2$ V. We size the burden so the signal at our 30 A target uses the ADC range efficiently while providing generous headroom for motor inrush transients.

Following the ADS131M02 datasheet recommendation (Section 9.2.2.1), the burden is implemented as a **split configuration**: two equal resistors of $R_b/2$ in series, with the center tap connected to AGND. This produces a balanced differential signal — the positive ADC input sees $+V_{b}/2$ and the negative input sees $-V_{b}/2$ relative to ground, both 180 degrees out of phase. The split configuration provides best THD performance because any even-order distortion in the ADC's input stage is cancelled by the balanced drive.

We select $R_b = 10 \text{ } \Omega$ (2 $\times$ 5 $\Omega$). At 30 A target, the peak burden voltage is:

$$V_{b,\text{pk}}\big|_{30\text{A}} = I_{s,\text{pk}} \cdot R_b = 42.43 \times 10^{-3} \times 10 = 0.424 \text{ V}$$

This is $0.424 / 1.2 = 35.4$% of the ADC full-scale range at $G = 1$ — relatively low utilisation, but the design compensates for this by running the ADS131M02 at **PGA = 2 as the default operating mode** (see Section 2.3). The clipping threshold at $G = 1$:

$$I_{p,\text{clip}}\big|_{G=1} = \frac{V_{\text{ref}}}{R_b} \cdot n = \frac{1.2}{10} \times 1000 = 120 \text{ A (peak)} = 84.9 \text{ A (RMS)}$$

This provides ample headroom for motor startup inrush transients. Even a 1.5 HP aircon compressor drawing 50 A peak inrush is well within the clipping threshold.

### 2.2 Current Measurement Resolution

At the default operating mode of $G = 2$, the effective full-scale range is:

$$V_{\text{FSR}}\big|_{G=2} = \pm \frac{V_{\text{ref}}}{G} = \pm \frac{1.2}{2} = \pm 0.6 \text{ V}$$

The peak burden voltage at 30 A target relative to this range:

$$\text{Utilisation}\big|_{G=2} = \frac{0.424}{0.6} = 70.7\%$$

This is good ADC utilisation. The clipping threshold at $G = 2$:

$$I_{p,\text{clip}}\big|_{G=2} = \frac{0.6}{10} \times 1000 = 60 \text{ A (peak)} = 42.4 \text{ A (RMS)}$$

At 42.4 A RMS, clipping occurs above 141% of the 30 A target — adequate for steady-state measurements. Motor inrush events that exceed 42.4 A RMS are handled by the gain-ranging firmware (Section 2.3).

The ADC's least significant bit (LSB) voltage at $G = 2$ is:

$$V_{\text{LSB}} = \frac{2 \cdot V_{\text{ref}} / G}{2^N} = \frac{2 \times 0.6}{2^{24}} = \frac{1.2}{16{,}777{,}216} = 71.53 \text{ nV}$$

The effective resolution is limited by noise, not by the 24-bit code space. At 4 kSPS with $G = 2$, the input-referred RMS noise is approximately 3.5 $\mu$V (noise improves at higher PGA gain because the PGA amplifies before the ADC's quantisation noise floor). The noise-limited effective resolution in current terms:

$$\Delta I_{p,\text{noise}} = \frac{e_{n,G=2}}{R_b} \cdot n = \frac{3.5 \times 10^{-6}}{10} \times 1000 = 0.350 \text{ mA (rms primary)}$$

The effective current dynamic range at $G = 2$:

$$\text{DR}_I = \frac{I_{\text{max}}}{\Delta I_{p,\text{noise}} \cdot \sqrt{2}} = \frac{30}{0.350 \times 10^{-3} \times 1.414} \approx 60{,}600 : 1$$

This far exceeds the 5000:1 design target and outperforms the PZEM-004T's usable range.

### 2.3 PGA Gain-Ranging Strategy

The ADS131M02's PGA is used as the primary mechanism to optimise ADC utilisation across the operating range. Rather than increasing the burden resistance (which would reduce the inrush clipping threshold), the burden is kept at 10 $\Omega$ and the PGA gain is adjusted in firmware based on the measured signal amplitude.

**Default mode: $G = 2$.** This is the normal operating mode for loads up to 30 A. ADC utilisation is 70.7% at 30 A, and the clipping threshold is 42.4 A RMS — sufficient for all steady-state residential loads.

**Inrush mode: $G = 1$.** When the firmware detects the signal approaching clipping (e.g., absolute sample value exceeds 90% of FSR at $G = 2$), it immediately switches to $G = 1$. The clipping threshold doubles to 84.9 A RMS, capturing the full motor inrush waveform. Once the signal stabilises below the $G = 2$ threshold, the firmware switches back.

**High-sensitivity mode: $G = 4$ or higher.** For loads drawing less than approximately 5 A (where the signal at $G = 2$ is below 15% of FSR), the firmware can increase the gain to $G = 4$, $G = 8$, or $G = 16$ for better waveform fidelity during classification. At $G = 16$:

$$V_{\text{FSR}}\big|_{G=16} = \pm 75 \text{ mV}$$

$$I_{p,\text{clip}}\big|_{G=16} = \frac{0.075}{10} \times 1000 = 7.5 \text{ A (peak)} = 5.3 \text{ A (RMS)}$$

The noise floor at $G = 16$ is approximately 0.95 $\mu$V rms, giving a current resolution of:

$$\Delta I_{p,\text{noise}}\big|_{G=16} = \frac{0.95 \times 10^{-6}}{10} \times 1000 = 0.095 \text{ mA}$$

This allows meaningful waveform capture and harmonic analysis down to loads as small as 50–100 mA (phone chargers, LED bulbs).

The gain-ranging transition thresholds:

| PGA Gain | FSR ($\pm$ V) | Clip Threshold (A RMS) | Noise Floor (mA) | Typical Use |
|---|---|---|---|---|
| $G = 1$ | $\pm 1.2$ | 84.9 | 0.530 | Motor inrush transients |
| $G = 2$ (default) | $\pm 0.6$ | 42.4 | 0.350 | Normal operation, 5–30 A loads |
| $G = 4$ | $\pm 0.3$ | 21.2 | 0.200 | Medium loads, 2–15 A |
| $G = 16$ | $\pm 0.075$ | 5.3 | 0.095 | Small loads, 0.05–5 A |

### 2.4 Burden Resistor Specification

The burden resistor dissipates power at the 30 A target:

$$P_b = I_{s,\text{target}}^2 \cdot R_b = (30 \times 10^{-3})^2 \times 10 = 9 \text{ mW}$$

At the CT's full rated current of 100 A (brief inrush event):

$$P_{b,\text{max}} = (100 \times 10^{-3})^2 \times 10 = 100 \text{ mW}$$

Both are well within a 1/4 W resistor's rating. The resistor's temperature coefficient (tempco) directly affects metering accuracy. For 0.5% total accuracy budget, the burden resistor should contribute no more than 0.1% drift over the operating temperature range:

$$\text{Required tempco} \leq \frac{0.001}{(70 - 25)} = 22.2 \text{ ppm/}^\circ\text{C}$$

Select: **2 $\times$ 5 $\Omega$, 0.1% tolerance, 15 ppm/$^\circ$C metal film resistor** (e.g., Vishay MRS25 or Yageo MFR series). Matched pair from the same reel to minimise differential imbalance.

---

## 3. Voltage Channel Design — ZMPT101B Isolated Voltage Transformer

### 3.1 Operating Principle

The ZMPT101B is a current-type precision voltage transformer with a 1:1 turns ratio (1000:1000). Unlike a conventional voltage transformer where the secondary voltage directly represents the primary voltage, the ZMPT101B operates by establishing a current proportional to the mains voltage in its primary winding, and faithfully reproducing that same current in the secondary winding. The primary current is set by an external current-limiting resistor $R_L$, and the secondary current is converted to a measurable voltage by a sampling (burden) resistor $R_s$.

The signal flow is:

$$V_{\text{mains}} \xrightarrow{R_L} I_{\text{primary}} \xrightarrow{1:1} I_{\text{secondary}} \xrightarrow{R_s} V_{\text{out}}$$

This provides 4 kV galvanic isolation between the mains and the measurement circuit, eliminating the open-neutral hazard that exists with a direct resistive voltage divider.

### 3.2 Current-Limiting Resistor Selection

The primary operating current at nominal mains voltage is:

$$I_{\text{op}} = \frac{V_{\text{rms}}}{R_L}$$

The ZMPT101B datasheet recommends an operating current of 1–2 mA when the rated input voltage is 220 V or above. However, the OpenEnergyMonitor project's characterisation of this transformer found that operating at approximately 4 mA significantly reduces both the magnitude and the variation of the phase angle error. The phase error curve is flatter between 2 mA and 4 mA than between 1 mA and 2 mA.

We design for $I_{\text{op}} = 2$ mA as a starting point (the datasheet-recommended value at 220 V), with an option to increase to 4 mA if phase error calibration proves insufficient:

At $I_{\text{op}} = 2$ mA:

$$R_L = \frac{V_{\text{nom}}}{I_{\text{op}}} = \frac{220}{2 \times 10^{-3}} = 110 \text{ k}\Omega$$

The nearest standard value is **110 k$\Omega$**. The actual operating current at 220 V:

$$I_{\text{op,actual}} = \frac{220}{110{,}000} = 2.0 \text{ mA}$$

At $I_{\text{op}} = 4$ mA (reduced phase error variant):

$$R_L = \frac{V_{\text{nom}}}{I_{\text{op}}} = \frac{220}{4 \times 10^{-3}} = 55 \text{ k}\Omega$$

Use 3 $\times$ 18 k$\Omega$ = 54 k$\Omega$ in series (for voltage rating, each resistor sees $\leq 220/3 = 73$ V, well within 200 V rating), or a single 56 k$\Omega$.

### 3.3 Voltage Rating of the Current-Limiting Resistor

At 220 V rms ($\pm 10$% = up to 242 V rms, 342 V peak), the current-limiting resistor must withstand the full mains voltage. Standard through-hole resistors are rated for 200–250 V. For the 110 k$\Omega$ design:

$$V_{R_L} \approx V_{\text{mains}} \quad \text{(since the transformer winding impedance is negligible compared to } R_L \text{)}$$

At 242 V rms, a single 110 k$\Omega$ resistor would see the full voltage. Using **two 56 k$\Omega$ resistors in series** (total 112 k$\Omega$), each sees half the voltage ($\leq 121$ V rms), safely within the 200 V rating per resistor.

The power dissipation in $R_L$:

$$P_{R_L} = I_{\text{op}}^2 \cdot R_L = (2 \times 10^{-3})^2 \times 112{,}000 = 0.448 \text{ W}$$

At 4 mA operation ($R_L = 56$ k$\Omega$):

$$P_{R_L} = (4 \times 10^{-3})^2 \times 56{,}000 = 0.896 \text{ W}$$

For the 2 mA variant, two 1/2 W resistors in series are adequate. For the 4 mA variant, three 1 W resistors in series (3 $\times$ 18 k$\Omega$) provide both voltage rating and power dissipation margin.

The datasheet recommends selecting resistors rated at least 4$\times$ the computed dissipation for reliability:

$$P_{\text{rated}} \geq 4 \times P_{R_L} = 4 \times 0.448 = 1.79 \text{ W (for 2 mA variant)}$$

Two 1 W metal film resistors in series satisfy this.

### 3.4 Sampling Resistor Selection

The secondary current equals the primary current (1:1 ratio). The sampling resistor $R_s$ converts this to a voltage for the ADC:

$$V_{\text{out}} = I_{\text{secondary}} \cdot R_s = I_{\text{op}} \cdot R_s$$

The peak secondary current at maximum mains voltage (242 V rms):

$$I_{s,\text{pk}} = \frac{V_{\text{pk,max}}}{R_L} = \frac{242 \times \sqrt{2}}{112{,}000} = \frac{342.2}{112{,}000} = 3.056 \text{ mA}$$

The peak output voltage must not exceed the ADS131M02's full-scale input ($\pm 1.2$ V at $G = 1$):

$$V_{\text{out,pk}} = I_{s,\text{pk}} \cdot R_s \leq V_{\text{ref}} = 1.2 \text{ V}$$

$$R_{s,\text{max}} = \frac{V_{\text{ref}}}{I_{s,\text{pk}}} = \frac{1.2}{3.056 \times 10^{-3}} = 392.7 \text{ } \Omega$$

We target approximately 80% of full-scale at maximum mains voltage for headroom:

$$R_{s,\text{design}} = 0.8 \times R_{s,\text{max}} = 0.8 \times 392.7 = 314 \text{ } \Omega$$

The nearest standard value is **330 $\Omega$**. Let us verify the output levels:

At nominal 220 V rms:

$$V_{\text{out,pk}} = \frac{220 \times \sqrt{2}}{112{,}000} \times 330 = \frac{311.1}{112{,}000} \times 330 = 2.778 \times 10^{-3} \times 330 = 0.917 \text{ V}$$

$$V_{\text{out,rms}} = \frac{220}{112{,}000} \times 330 = 0.6482 \text{ V}$$

At maximum 242 V rms (+10%):

$$V_{\text{out,pk,max}} = \frac{342.2}{112{,}000} \times 330 = 1.008 \text{ V}$$

At minimum 198 V rms ($-10$%):

$$V_{\text{out,pk,min}} = \frac{198 \times \sqrt{2}}{112{,}000} \times 330 = 0.825 \text{ V}$$

The utilisation at nominal voltage is $0.917 / 1.2 = 76.4$% — good use of the ADC range while maintaining adequate headroom for surges.

### 3.5 Effective Voltage Divider Ratio

The overall transfer function from mains voltage to ADC input voltage is:

$$\alpha_V = \frac{R_s}{R_L} = \frac{330}{112{,}000} = 2.946 \times 10^{-3}$$

This is the quantity used in firmware to convert ADC readings back to mains voltage:

$$V_{\text{mains}} = \frac{V_{\text{ADC}}}{\alpha_V}$$

### 3.6 Voltage Measurement Resolution

The noise-limited effective voltage resolution, referred back to the primary mains:

$$\Delta V_{\text{mains}} = \frac{e_n}{\alpha_V} = \frac{7.56 \times 10^{-6}}{2.946 \times 10^{-3}} = 2.57 \text{ mV rms}$$

As a fraction of nominal voltage:

$$\frac{\Delta V_{\text{mains}}}{V_{\text{nom}}} = \frac{2.57 \times 10^{-3}}{220} = 0.00117\% \approx 0.001\%$$

This is approximately 50x better than the PZEM-004T's 0.1 V resolution (0.045% at 220 V).

### 3.7 Verification of Error Sources

**ADC loading effect on the sampling resistor.** The ADS131M02's input impedance at $G \leq 4$ is approximately 300 k$\Omega$ (differential). The sampling resistor $R_s = 330 \text{ } \Omega$ is in parallel with this:

$$R_{s,\text{loaded}} = R_s \| Z_{\text{in}} = \frac{330 \times 300{,}000}{330 + 300{,}000} = \frac{99{,}000{,}000}{300{,}330} = 329.64 \text{ } \Omega$$

The gain error from loading:

$$\epsilon_{\text{load}} = \frac{R_s - R_{s,\text{loaded}}}{R_s} \times 100 = \frac{330 - 329.64}{330} \times 100 = 0.11\%$$

This is a constant systematic error, fully absorbed by gain calibration.

**Bias current offset.** The ADC's input bias current ($I_B \approx 0.6 \text{ } \mu$A) through $R_s$:

$$V_{\text{offset,bias}} = I_B \cdot R_s = 0.6 \times 10^{-6} \times 330 = 0.198 \text{ mV}$$

As a fraction of RMS output voltage:

$$\epsilon_{\text{bias}} = \frac{0.198 \times 10^{-3}}{0.6482} \times 100 = 0.031\%$$

Negligible. This is a DC offset on an AC signal; it is automatically rejected by the RMS computation in firmware (which removes the DC component before computing RMS).

**Transformer accuracy.** The ZMPT101B datasheet specifies a permissible error of $-0.3$% to $+0.2$% and linearity of $\leq 0.2$% across 20–120% of rated input. After gain calibration at the nominal operating point, the residual error across the $\pm 10$% mains voltage range is bounded by the linearity specification: $\leq 0.2$%.

**Sampling resistor specification.** The sampling resistor $R_s$ operates at very low power:

$$P_{R_s} = I_{\text{op}}^2 \cdot R_s = (2 \times 10^{-3})^2 \times 330 = 1.32 \text{ mW}$$

Select: **2 $\times$ 160 $\Omega$, 0.1% tolerance, 15 ppm/$^\circ$C metal film resistor**. The sampling resistor is split into two equal halves with the center tap connected to AGND, identical to the current channel's split burden configuration, for balanced differential drive and optimal THD.

### 3.8 Circuit Topology — Voltage Channel

```
               MAINS SIDE (isolated by transformer)     │    LOW-VOLTAGE SIDE
                                                        │
AC Line (L) ── R_La ── R_Lb ──┐                        │
                   (56k)(56k)  │                        │
                               │  ┌──────────┐          │
                               ├──┤ ZMPT101B ├──────────┼── Rs/2 ──┬── Rfilt ──┬── AIN1P
                               │  │  (1:1)   │          │  (165Ω)  │   (100Ω)  │
AC Neutral (N) ───────────────┘  └──────────┘          │         AGND        Cdiff
                                                        │          │   (680nF) │
                                    4kV isolation       │  Rs/2 ──┘── Rfilt ──┴── AIN1N
                                       barrier         │  (165Ω)      (100Ω)
```

The ZMPT101B provides 4 kV galvanic isolation. The primary winding is connected to the AC mains through the current-limiting resistor $R_L$. The secondary winding feeds a split sampling resistor ($2 \times 160 \text{ } \Omega$, center-tapped to AGND) for balanced differential drive. Matched filter resistors ($R_{\text{filt}} = 100 \text{ } \Omega$ on each line) and a differential capacitor ($C_{\text{diff}} = 680 \text{ nF}$) form the anti-aliasing filter. There is no galvanic connection between the mains and the measurement circuit.

---

## 4. Anti-Aliasing Filter Design

### 4.1 Nyquist Consideration

At a sample rate of $f_s = 4$ kSPS (the recommended operating point, see Section 7), the Nyquist frequency is:

$$f_{\text{Nyquist}} = \frac{f_s}{2} = 2 \text{ kHz}$$

The ADS131M02 uses a sinc3 digital decimation filter internally, which provides significant rejection of frequencies above $f_s / 2$. However, the sigma-delta modulator's analog input bandwidth extends far beyond $f_s$, so an external anti-aliasing filter is still needed to reject high-frequency noise (switching noise, EMI) that could alias into the signal band.

The signal bandwidth of interest extends to the 15th harmonic:

$$f_{\text{sig,max}} = 15 \times f_{\text{mains}} = 15 \times 60 = 900 \text{ Hz}$$

We need the filter to pass this bandwidth with minimal attenuation while suppressing content above $f_s / 2 = 2$ kHz. A first-order RC low-pass filter is sufficient because the sinc3 digital filter provides additional rolloff.

### 4.2 Filter Topology — Differential RC Filter

Per the ADS131M02 datasheet (Section 9.2.2.1), the recommended anti-aliasing filter for differential inputs uses matched series resistors on each input line with a differential capacitor across the ADC pins. This topology is applied identically to both channels:

```
Burden/Sampling         Anti-Aliasing Filter              ADC
Resistor (split)        (identical on both channels)
────────────────        ────────────────────────          ─────

                        Rfilt               Cdiff
Sensor+ ── R/2 ──┬──── (100Ω) ────┬──────────────────── AINxP
                  │                │
                 AGND            (680nF)                ADS131M02
                  │                │
Sensor- ── R/2 ──┘──── (100Ω) ────┴──────────────────── AINxN
                        Rfilt
```

The split burden/sampling resistor (center-tapped to AGND) produces a balanced differential signal. The filter resistors $R_{\text{filt}}$ are separate components from the burden/sampling resistors — they serve exclusively as the R in the RC filter and as current limiters for ADC input protection. The differential capacitor $C_{\text{diff}}$ spans the two ADC input pins.

This topology has three important properties. First, the burden/sampling resistor value is decoupled from the filter cutoff — each can be optimised independently. Second, because both channels use identical $R_{\text{filt}}$ and $C_{\text{diff}}$ values, the filter introduces zero differential phase error between the voltage and current channels. Third, the matched series resistors on each line reject common-mode noise that couples through transformer winding capacitance.

### 4.3 Filter Cutoff Frequency Selection

For this differential topology, the $-3$ dB cutoff frequency is:

$$f_c = \frac{1}{2\pi R_{\text{filt}} C_{\text{diff}}}$$

We want minimal attenuation at 900 Hz (less than 0.5 dB) and significant attenuation above 2 kHz. The attenuation of a first-order filter at frequency $f$ is:

$$A(f) = \frac{1}{\sqrt{1 + (f / f_c)^2}}$$

At $f = 900$ Hz with $A \geq 0.944$ ($-0.5$ dB):

$$0.944 = \frac{1}{\sqrt{1 + (900 / f_c)^2}}$$

$$f_c = \frac{900}{\sqrt{0.1225}} = \frac{900}{0.350} = 2571 \text{ Hz}$$

### 4.4 Component Values (Both Channels Identical)

Selecting $R_{\text{filt}} = 100 \text{ } \Omega$:

$$C_{\text{diff}} = \frac{1}{2\pi R_{\text{filt}} f_c} = \frac{1}{2\pi \times 100 \times 2571} = 619 \text{ nF}$$

Choose the nearest standard value: **$C_{\text{diff}} = 680$ nF** (ceramic C0G/NP0 for low distortion).

Actual cutoff:

$$f_c = \frac{1}{2\pi \times 100 \times 680 \times 10^{-9}} = 2341 \text{ Hz}$$

Attenuation at 900 Hz:

$$A(900) = \frac{1}{\sqrt{1 + (900 / 2341)^2}} = \frac{1}{\sqrt{1.1478}} = 0.934 = -0.59 \text{ dB}$$

This is a systematic 6.6% amplitude reduction at the 15th harmonic. Since we know the filter's exact transfer function, this can be corrected in firmware when computing harmonic magnitudes. At the fundamental (60 Hz):

$$A(60) = \frac{1}{\sqrt{1 + (60 / 2341)^2}} = \frac{1}{\sqrt{1.000657}} = 0.99967 = -0.003 \text{ dB}$$

Negligible — 0.033% amplitude error at the fundamental frequency.

### 4.5 Differential Phase Error Between Channels

Because both channels use identical filter components ($R_{\text{filt}} = 100 \text{ } \Omega$, $C_{\text{diff}} = 680 \text{ nF}$), the phase lag introduced by the filter is the same on both channels:

$$\phi_{\text{filter}} = -\arctan\left(\frac{60}{2341}\right) = -1.47^\circ \quad \text{(both channels)}$$

The differential filter phase error is therefore:

$$\Delta\phi_{\text{filter}} = \phi_{V,\text{filter}} - \phi_{I,\text{filter}} = -1.47^\circ - (-1.47^\circ) = 0^\circ$$

This eliminates the filter contribution to the phase error budget entirely — a direct consequence of using matched filter components on both channels.

### 4.6 SPICE Netlist — Complete Current Channel

```spice
* ============================================================
* Current Channel: PZEM CT (1:1000) + Split Burden + Differential Filter
* ============================================================

.subckt PZEM_CT pri_p pri_n sec_p sec_n
  K1 Lpri Lsec 0.999
  Lpri pri_p pri_n 1H
  Lsec sec_p sec_n 1H
.ends PZEM_CT

.subckt ADS131M02_CH ainp ainn
  Rin ainp ainn 300k
.ends ADS131M02_CH

* --- Primary conductor (load current, 30A target) ---
Iload load_p load_n SIN(0 42.43 60)
Rload load_p load_n 1

* --- Current transformer (PZEM-004T bundled, 1:1000) ---
X_CT load_p load_n ct_p ct_n PZEM_CT

* --- Split burden resistor (2 x 5 ohm, center-tapped to AGND) ---
Rb_top ct_p  0 5
Rb_bot ct_n  0 5

* --- Anti-aliasing filter (differential) ---
Rfilt_p ct_p  ain0p 100
Rfilt_n ct_n  ain0n 100
Cdiff   ain0p ain0n 680n

* --- ADC differential input ---
X_ADC ain0p ain0n ADS131M02_CH

.end
```

### 4.7 SPICE Netlist — Complete Voltage Channel

```spice
* ============================================================
* Voltage Channel: ZMPT101B + Split Sampling R + Differential Filter
* ============================================================

.subckt ZMPT101B pri_p pri_n sec_p sec_n
  K1 Lpri Lsec 0.999
  Lpri pri_p pri_n 10H
  Lsec sec_p sec_n 10H
.ends ZMPT101B

.subckt ADS131M02_CH ainp ainn
  Rin ainp ainn 300k
.ends ADS131M02_CH

* --- Mains source ---
Vmains vline vneutral SIN(0 311.13 60)

* --- Current-limiting resistors (2 x 56k in series) ---
RLa vline    net_rl  56k
RLb net_rl   vt_pri  56k

* --- ZMPT101B voltage transformer ---
X_VT vt_pri vneutral vt_sec_p vt_sec_n ZMPT101B

* --- Split sampling resistor (2 x 160 ohm, center-tapped to AGND) ---
Rs_top vt_sec_p 0 160
Rs_bot vt_sec_n 0 160

* --- Anti-aliasing filter (differential, identical to current channel) ---
Rfilt_vp vt_sec_p ain1p 100
Rfilt_vn vt_sec_n ain1n 100
Cdiff_v  ain1p    ain1n 680n

* --- ADC differential input ---
X_ADC1 ain1p ain1n ADS131M02_CH

.end
```

---

## 5. Phase Error Budget

### 5.1 Sources of Phase Error

The total differential phase error between the voltage and current measurement channels is the sum of contributions from four sources. Each source introduces a phase lag (or lead) at the fundamental frequency (60 Hz), and the net differential determines the systematic error in power factor measurement.

### 5.2 ZMPT101B Voltage Transformer Phase Error

The ZMPT101B datasheet specifies a phase angle error of $\leq 20$ arcminutes at 2 mA operating current:

$$\phi_{\text{ZMPT}} \leq 20' = 0.333^\circ \quad \text{(lagging, voltage output lags input)}$$

At 4 mA operating current, the OpenEnergyMonitor project's characterisation shows the phase error is significantly reduced and the curve is flatter. Conservatively estimate:

$$\phi_{\text{ZMPT}} \approx 0.2^\circ \text{ at } 4 \text{ mA, } \approx 0.33^\circ \text{ at } 2 \text{ mA}$$

This phase shift is constant because the mains voltage (and therefore the transformer operating current) does not change significantly during operation.

### 5.3 PZEM-004T Bundled CT Phase Error

The PZEM-004T's bundled CT does not have published phase error specifications. However, several properties of the CT allow a reasonable estimate of its phase behaviour.

The CT is a solid-core toroidal design (no air gap), which generally produces lower and more stable phase error than split-core CTs. It is rated for 100 A but operates at 30 A (30% of rated capacity), placing it deep in the linear region of its magnetization curve where the magnetizing current is a small fraction of the load current. The turns ratio (1:1000) and the modest burden resistance (10 $\Omega$) result in low secondary voltage (0.424 V peak at 30 A), minimising the voltage-driven component of magnetizing current error.

Based on analogous solid-core toroidal CTs of similar construction (e.g., HWCT-004, ZMCT103C), the phase error is estimated at:

| Primary Current | Estimated CT Phase Error |
|---|---|
| 30 A (target) | $\approx 0.2^\circ$ – $0.5^\circ$ |
| 10 A | $\approx 0.3^\circ$ – $0.8^\circ$ |
| 5 A | $\approx 0.5^\circ$ – $1.0^\circ$ |
| 1 A | $\approx 0.5^\circ$ – $1.5^\circ$ |

These values are estimates. The actual phase error must be determined empirically during the calibration procedure (Section 10.3). The calibration procedure is designed to accommodate CTs with unknown phase characteristics — a single-point or two-point calibration using a known resistive load will determine the actual correction needed.

The CT is operating at 30% of its rated capacity, which is favorable: at this operating point, the core is far from saturation, the magnetizing current is proportionally small, and the phase error tends to be stable and well-behaved.

### 5.4 Anti-Aliasing Filter Differential Phase Error

Both channels use identical differential RC filters ($R_{\text{filt}} = 100 \text{ } \Omega$, $C_{\text{diff}} = 680 \text{ nF}$, $f_c = 2341 \text{ Hz}$). The phase lag at 60 Hz is the same on both channels:

$$\phi_{\text{filter}} = -\arctan\left(\frac{60}{2341}\right) = -\arctan(0.0256) = -1.47^\circ \quad \text{(both channels)}$$

Because the filters are matched, the differential phase error is:

$$\Delta\phi_{\text{filter}} = 0^\circ$$

This is a direct consequence of using identical filter components on both channels rather than relying on the burden/sampling resistor as part of the filter network (which would give different cutoffs due to different R values).

### 5.5 ADC Sampling Phase Error

The ADS131M02 samples both channels simultaneously — the two sigma-delta modulators are clocked by the same edge. Therefore:

$$\Delta\phi_{\text{ADC}} = 0^\circ$$

This is the fundamental advantage of the ADS131M02 over multiplexed ADC architectures.

### 5.6 Total Phase Error Budget

| Source | Voltage Channel | Current Channel | Differential ($V - I$) | Type |
|---|---|---|---|---|
| ZMPT101B transformer | $-0.33^\circ$ (lag) | — | $-0.33^\circ$ | Constant |
| PZEM CT (estimated, at 30 A) | — | $-0.2^\circ$ to $-0.5^\circ$ (lag) | $+0.2^\circ$ to $+0.5^\circ$ | Needs characterisation |
| Anti-aliasing filter (matched) | $-1.47^\circ$ | $-1.47^\circ$ | $0^\circ$ | Matched (zero) |
| ADC simultaneous sampling | $0^\circ$ | $0^\circ$ | $0^\circ$ | — |
| **Total (uncalibrated, at 30 A)** | — | — | **$-0.13^\circ$ to $+0.17^\circ$** | **Requires calibration** |

### 5.7 Phase Error Correction Strategy

The total uncalibrated phase error at 30 A is estimated between $-0.13°$ and $+0.17°$ depending on the CT's actual phase characteristics. Since the CT's phase error is unknown, the correction value must be determined empirically during calibration (Section 10.3) rather than computed from datasheet values.

The PHASE register applies a sub-sample time shift in increments of one modulator clock period:

$$\Delta t_{\text{step}} = \frac{1}{f_{\text{CLKIN}}} = \frac{1}{8.192 \times 10^6} = 122.07 \text{ ns}$$

The corresponding phase resolution at 60 Hz:

$$\Delta\phi_{\text{step}} = 360^\circ \times f_{\text{mains}} \times \Delta t_{\text{step}} = 360 \times 60 \times 122.07 \times 10^{-9} = 0.00264^\circ$$

For a hypothetical measured phase error of $0.15^\circ$:

$$\text{PHASE register value} = \text{round}\left(\frac{0.15}{0.00264}\right) = 57 \text{ (integer steps)}$$

The PHASE register has sufficient range to correct errors up to several degrees, so even if the CT's phase error turns out to be larger than estimated, the hardware correction mechanism is adequate. One register write during firmware initialisation — no runtime correction needed for a stable, well-characterised CT.

### 5.8 Post-Calibration Residual Phase Error

After the single-point correction at 30 A, the residual phase error is bounded by the CT's phase variation across the operating current range. Based on the estimated phase error table in Section 5.3, the worst-case deviation from the 30 A calibration point occurs at low currents (1–5 A), where the phase error may increase by up to $0.5°$ – $1.0°$ from the calibrated value.

If initial calibration reveals that the CT's phase error varies significantly with current (more than $0.5°$ from the calibration point), a two-point correction strategy can be employed: calibrate at 5 A and 25 A using known resistive loads, store both (current, phase_error) pairs in firmware, and interpolate at runtime. This reduces the worst-case residual to approximately $\pm 0.25°$.

The resulting power measurement error at $\text{PF} = 0.8$ ($\theta = 36.87°$) with a residual phase error of $\Delta\phi = 0.5°$ (worst case, single-point calibration):

$$\epsilon_P = \frac{\cos(36.87° + 0.5°) - \cos(36.87°)}{\cos(36.87°)} = \frac{0.7960 - 0.8}{0.8} = -0.50\%$$

At $\text{PF} = 0.5$ ($\theta = 60°$) with $\Delta\phi = 0.5°$:

$$\epsilon_P = \frac{\cos(60.5°) - \cos(60°)}{\cos(60°)} = \frac{0.4957 - 0.5}{0.5} = -0.87\%$$

The single-point calibration meets the 0.5% target at PF $\geq 0.8$. For loads with PF $< 0.8$, a two-point calibration would be needed to stay within budget. Since your primary classification targets (aircon, fridge, fan) operate at PF = 0.6–0.9, the two-point calibration is recommended if the initial characterisation reveals significant current-dependent phase variation.

### 5.9 Phase Behaviour at Harmonics

Both the ZMPT101B and the PZEM-004T CT have frequency-dependent phase characteristics. At higher harmonics, the phase shifts differ from the fundamental. However, for load characterisation, the primary features used are harmonic magnitudes (H3/H1, H5/H1, THD, crest factor), not harmonic phase angles. The magnitude response of both transformers is expected to be flat within $\pm 1$% from 50 Hz to 1 kHz for toroidal cores of this construction. The matched anti-aliasing filters ensure no additional differential magnitude or phase error is introduced at any harmonic frequency.

The one harmonic-phase-sensitive quantity is the displacement power factor, which is measured at the fundamental (60 Hz) where our calibration is precise.

---

## 6. Power Supply and Isolation Architecture

### 6.1 ADS131M02 Power Requirements

| Rail | Voltage | Typical Current | Notes |
|---|---|---|---|
| AVDD | 3.0 V (nom.) | 3.5 mA | Analog supply, 2.7 – 3.6 V range |
| DVDD | 3.3 V | 0.5 mA | Digital supply, shared with ESP32-S3 |
| Total | — | ~4 mA | — |

Since the ADS131M02 operates at 3.0 – 3.3 V and the ESP32-S3 also runs at 3.3 V, the ADS131M02 shares the same 3.3 V regulated supply as the ESP32-S3.

### 6.2 Isolation Architecture — Fully Galvanically Isolated

With the ZMPT101B replacing the resistive voltage divider, both measurement channels now have full galvanic isolation from the AC mains:

- **Current channel:** The PZEM-004T bundled CT is a solid-core toroidal transformer providing magnetic coupling between the primary conductor and the secondary winding. Isolation voltage is estimated at $\geq 1$ kV based on the construction of similar toroidal CTs, which is adequate for 220 V residential mains (the peak voltage is 311 V).
- **Voltage channel:** The ZMPT101B provides magnetic coupling with 4 kV dielectric strength between the primary (mains-connected) and secondary (measurement-side) windings.

The ADS131M02 and the ESP32-S3 sit entirely on the low-voltage side. There is no resistive DC path from the mains to any point on the low-voltage circuit. An open-neutral fault cannot elevate the low-voltage ground to mains potential.

No digital isolator (ADuM1401) is needed on the SPI bus. The ADS131M02 connects directly to the ESP32-S3's SPI peripheral at full speed (up to 25 MHz SCLK).

```
    MAINS SIDE                    ║ ISOLATION ║    LOW-VOLTAGE SIDE
    (dangerous)                   ║  BARRIER  ║    (safe, 3.3V)
                                  ║           ║
    ┌─── AC Live (L)              ║           ║
    │                             ║           ║
    │  R_La ── R_Lb ──┐           ║           ║
    │  (56k)  (56k)   │           ║           ║
    │                  │ ┌──────┐ ║           ║  Rs/2    Rfilt_vp       Cdiff_v
    │                  ├─┤ZMPT  ├─╫───────────╫─(160Ω)─┬─(100Ω)──┬── AIN1P ──┐
    │                  │ │101B  │ ║           ║        │         │           │
    └── AC Neutral ────┘ │(1:1) │ ║  4kV      ║       AGND    (680nF)       │
                         └──────┘ ║ isolation ║        │         │           │
                                  ║           ╠─(160Ω)─┘─(100Ω)──┴── AIN1N   │
                                  ║           ║  Rs/2    Rfilt_vn             │
                                  ║           ║                               │
    ┌─── Load wire ───────────┐   ║           ║                               │
    │  (passes through CT)    │   ║           ║  Rb/2    Rfilt_ip   Cdiff_i   │
    │                         │   ║           ║                               │
    │         ┌──────┐        │   ║           ║                               │
    │         │PZEM  │        │   ║           ║                               │
    │         │CT    ├────────╫───╫──(5Ω)──┬─╫─(100Ω)──┬── AIN0P             │
    │         │1:1000│        ║   ║        │ ║         │                      │
    │         │100A  ├────────╫───╫──     AGND       (680nF)          ADS131M02
    │         └──────┘        ║   ║  (5Ω)──┘ ║         │           (3.3V, shared
    │                         ║   ║  Rb/2    ╫─(100Ω)──┴── AIN0N    GND w/ ESP32)
    │          ~1kV isolation ║   ║          ║  Rfilt_in             │
    │                         ║   ║          ║                       │
    │                         ║   ║          ║     SCLK ────────────┤── GPIO 18
    │                         ║   ║          ║     DIN  ────────────┤── GPIO 23
    │                         ║   ║          ║     DOUT ────────────┤── GPIO 19
    │                         ║   ║          ║     CS   ────────────┤── GPIO 5
    │                         ║   ║          ║     DRDY ────────────┤── GPIO 4
    │                         ║   ║          ║                       │
    │                         ║   ║          ║     AVDD ────────────┤── 3.3V
    │                         ║   ║          ║     DVDD ────────────┤── 3.3V
    │                         ║   ║          ║     AGND ────────────┤── GND
    │                         ║   ║          ║     DGND ────────────┤── GND
    │                         ║   ║          ║                       │
    └─────────────────────────┘   ║          ║     CLKIN ───────────┤── 8.192 MHz
                                  ║          ║                       │
```

### 6.3 Decoupling

The ADS131M02 datasheet specifies:

- AVDD: 1 $\mu$F ceramic (X7R or C0G) to AGND, placed within 5 mm of pin
- DVDD: 1 $\mu$F ceramic to DGND
- CAP (LDO output): 220 nF ceramic to DGND

The AGND and DGND pins should be connected together at a single point near the ADS131M02, forming a star ground. On a perfboard, this means running the analog ground and digital ground as separate wires to a common point at the ADC.

---

## 7. ADC Operating Mode Selection

### 7.1 Data Rate vs. Effective Resolution Trade-Off

The ADS131M02's noise performance improves at lower data rates because the sinc3 decimation filter averages more modulator samples. The relevant entries from the datasheet noise table (at $G = 1$, internal 1.2 V reference):

| Data Rate (SPS) | RMS Noise ($\mu$V) | Effective Resolution (bits) | Samples per 60 Hz Cycle |
|---|---|---|---|
| 1000 | 2.4 | 19.9 | 16.7 |
| 2000 | 3.7 | 19.3 | 33.3 |
| 4000 | 5.3 | 18.8 | 66.7 |
| 8000 | 7.56 | 18.3 | 133.3 |
| 16000 | 10.6 | 17.8 | 266.7 |
| 32000 | 15.1 | 17.3 | 533.3 |

### 7.2 Recommended Operating Point: 4 kSPS

At 4 kSPS, each 60 Hz cycle is sampled 66.7 times. By Nyquist, this supports harmonic analysis up to the 33rd harmonic (1980 Hz) — more than sufficient for the target of 15 harmonics.

The effective resolution of 18.8 bits gives a noise-limited dynamic range of:

$$\text{DR} = 6.02 \times 18.8 + 1.76 = 115 \text{ dB}$$

In linear terms, this is a dynamic range of approximately $562{,}000 : 1$, far exceeding the 5000:1 dynamic range target.

The noise-limited current resolution at 4 kSPS (at default $G = 2$, input-referred noise $\approx 3.5 \text{ } \mu$V):

$$\Delta I_{p,\text{noise}} = \frac{3.5 \times 10^{-6}}{10} \times 1000 = 0.350 \text{ mA rms (primary)}$$

The noise-limited voltage resolution at 4 kSPS:

$$\Delta V_{\text{mains}} = \frac{5.3 \times 10^{-6}}{2.946 \times 10^{-3}} = 1.80 \text{ mV rms (primary)}$$

Both are well below the PZEM-004T's resolution (1 mA current, 100 mV voltage). The current resolution is improved by running at PGA $G = 2$ as the default mode, which reduces input-referred noise while maintaining adequate dynamic range for the 30 A target.

### 7.3 SPI Throughput at 4 kSPS

The ADS131M02 SPI frame format contains:

| Field | Bits |
|---|---|
| Status word | 16 |
| Channel 0 data | 24 |
| Channel 1 data | 24 |
| CRC | 16 |
| **Total** | **80** |

At 4 kSPS:

$$\text{SPI throughput} = 4000 \times 80 = 320 \text{ kbps}$$

The ADS131M02 supports SCLK up to 25 MHz. The bus utilisation:

$$\text{Utilisation} = \frac{320 \times 10^3}{25 \times 10^6} \times 100 = 1.28\%$$

The SPI bus is essentially idle. Each frame read takes:

$$t_{\text{frame}} = \frac{80}{25 \times 10^6} = 3.2 \text{ } \mu\text{s}$$

The inter-sample period at 4 kSPS is 250 $\mu$s, so the SPI read occupies only 1.28% of each sample period.

---

## 8. Complete Bill of Materials — Analog Front-End

| Ref | Description | Value | Spec | Qty |
|-----|---|---|---|-----|
| U1 | ADS131M02IPWR | — | TSSOP-20, 24-bit dual-ch simultaneous ADC | 1 |
| VT1 | ZMPT101B voltage transformer | 1:1, 2 mA | 4 kV isolation, PCB mount | 1 |
| CT1 | PZEM-004T bundled CT | 100 A rated, 1:1000 | Solid-core toroidal, ~1 kV isolation (salvaged from PZEM module) | 1 |
| R_La | Current-limiting resistor (ZMPT101B) | 56 k$\Omega$ | 1 W, 1%, metal film, 200V rated | 1 |
| R_Lb | Current-limiting resistor (ZMPT101B) | 56 k$\Omega$ | 1 W, 1%, metal film, 200V rated | 1 |
| R_s1, R_s2 | Split sampling resistor (ZMPT101B) | 160 $\Omega$ | 0.1%, 15 ppm/$^\circ$C, metal film, matched pair | 2 |
| R_b1, R_b2 | Split CT burden resistor | 5 $\Omega$ | 0.1%, 15 ppm/$^\circ$C, metal film, matched pair | 2 |
| R_filt (x4) | Anti-alias filter resistor (both channels) | 100 $\Omega$ | 1%, metal film | 4 |
| C_diff (x2) | Anti-alias differential cap (both channels) | 680 nF | C0G/NP0 ceramic, 50 V | 2 |
| C1 | AVDD decoupling | 1 $\mu$F | C0G or X7R ceramic, 10 V | 1 |
| C2 | DVDD decoupling | 1 $\mu$F | X7R ceramic, 10 V | 1 |
| C3 | CAP pin (internal LDO) | 220 nF | X7R ceramic, 10 V | 1 |
| Y1 | Crystal oscillator | 8.192 MHz | HC-49S or CMOS oscillator, 20 ppm | 1 |
| CY1, CY2 | Crystal load caps (if using crystal) | 12 pF | C0G ceramic | 2 |
| J1 | TSSOP-20 to DIP adapter board | — | 0.65 mm pitch breakout | 1 |

---

## 9. Performance Summary and Comparison

| Parameter | PZEM-004T v3 | ADS131M02 + ZMPT101B + PZEM CT | Improvement |
|---|---|---|---|
| Voltage resolution | 0.1 V | 1.80 mV | ~56x |
| Current resolution (at $G = 2$) | 1 mA | 0.35 mA | ~2.9x |
| Voltage accuracy (after cal.) | 0.5% | $< 0.2$% | ~2.5x |
| Current accuracy (after cal.) | 0.5% | $< 0.2$% | ~2.5x |
| Power accuracy at PF=0.8 (after cal.) | 0.5% | $< 0.5$% | Comparable (CT-dependent) |
| Power factor resolution | 0.01 | $< 0.001$ (computed) | ~10x |
| Simultaneous V/I sampling | No (internal mux) | Yes | Eliminates phase skew |
| Waveform access | None | Full raw samples | Enables NILM |
| Harmonic analysis | Not possible | Up to 33rd harmonic | Enables classification |
| Sample rate | Internal (no access) | 4 kSPS configurable | Full control |
| Energy accumulation | Hardware counter | Firmware integration | More flexible |
| Interface to MCU | UART Modbus (9600 baud) | SPI (up to 25 MHz) | ~2600x bandwidth |
| Galvanic isolation (V channel) | Optocoupler (comms only) | ZMPT101B, 4 kV | Full signal isolation |
| Galvanic isolation (I channel) | CT (built-in) | Same CT (salvaged), ~1 kV | Reused |
| Galvanic isolation (digital bus) | Optocoupler (built-in) | Not needed (both sensors isolated) | Simpler |
| Phase error (total, uncalibrated) | Unknown (internal) | $-0.13°$ to $+0.17°$ (estimated) | Requires characterisation |
| Phase calibration complexity | N/A | Single PHASE register write (+ optional 2-point LUT) | Low |
| PGA gain ranging | Not available | $G = 1$ to $G = 128$, firmware-controlled | Adaptive sensitivity |
| Power consumption (meter) | ~1 W (from AC mains) | ~13 mW + 0.45 W ($R_L$) | Comparable |
| Current range (target) | 0 – 100 A | 0 – 30 A (CT rated to 100 A) | Adequate for residential |
| CT installation | Toroidal (wire pass-through) | Same CT reused | No change |
| Component count | 1 module | ~16 discrete parts + salvaged CT | More, but cheaper |

---

## 10. Calibration Procedure

### 10.1 Gain Calibration

The ADS131M02 has 24-bit gain calibration registers for each channel. The calibration coefficient is applied as:

$$\text{output}_{\text{cal}} = \text{output}_{\text{raw}} \times \frac{\text{GAIN\_REG}}{0x400000}$$

Where $0x400000$ represents unity gain (1.0). To calibrate:

1. Apply a known AC voltage (measured with a calibrated multimeter) to the mains input.
2. Read the ADC's computed Vrms over 100 cycles.
3. Compute the gain coefficient: $k_V = V_{\text{true}} / V_{\text{measured}}$.
4. Write $\text{GAIN\_REG} = \text{round}(k_V \times 0x400000)$.
5. Repeat for the current channel with a known load and calibrated clamp meter.

### 10.2 Offset Calibration

1. Short the differential inputs of each channel (disconnect sensors).
2. Read 1000 samples and compute the mean.
3. Write the negated mean into the channel's offset calibration register.

The ADS131M02 also provides a global-chop mode that automatically cancels DC offset by alternating input polarity between consecutive conversions. This halves the effective data rate (4 kSPS becomes 2 kSPS effective). At 2 kSPS you still get 33 samples per cycle — adequate for harmonics up to the 16th.

### 10.3 Phase Calibration

Since the PZEM-004T bundled CT has no published phase error data, the phase correction must be determined empirically. The procedure is:

1. Apply a purely resistive load of known power (e.g., 100 W incandescent bulb or high-power resistor at a current level near 30 A if possible, or at whatever current is available). The true power factor is 1.00.
2. Capture several hundred cycles of simultaneous V and I waveforms.
3. Compute the phase angle between V and I fundamentals using cross-correlation or FFT phase extraction.
4. The measured phase angle is the system's total phase error at that current level.
5. Write the correction into the ADS131M02's PHASE register:

$$\text{PHASE\_REG} = \text{round}\left(\frac{\phi_{\text{error}} \times f_{\text{CLKIN}}}{360^\circ \times f_{\text{mains}}}\right) = \text{round}\left(\frac{\phi_{\text{error}} \times 8{,}192{,}000}{360 \times 60}\right)$$

6. Optionally repeat at a second current level (e.g., 5 A) to check for current-dependent phase variation. If the phase error differs by more than $0.3°$ between the two current levels, implement a two-point firmware correction: store both (current, phase_error) pairs and interpolate at runtime based on the measured RMS current.

This empirical approach accommodates CTs with unknown phase characteristics and is the same procedure used in commercial energy meter production calibration.

### 10.5 Calibration Verification

After all calibration steps, verify the system against known loads:

| Test Load | Expected PF | Acceptable PF Error | Expected P Error |
|---|---|---|---|
| 100 W incandescent bulb | 1.00 | $\pm 0.003$ | $\pm 0.3$% |
| 60 W ceiling fan (low speed) | 0.55 – 0.75 | $\pm 0.005$ | $\pm 0.5$% |
| Laptop charger (SMPS) | 0.50 – 0.70 | $\pm 0.005$ | $\pm 0.5$% |
| Window-type aircon | 0.75 – 0.90 | $\pm 0.005$ | $\pm 0.5$% |

---

## 11. Firmware Integration Notes

### 11.1 FreeRTOS Task Architecture — ESP32-S3 (Dual-Core)

```
Core 0:
  ├── adcTask (priority 5)
  │     Triggered by DRDY GPIO interrupt
  │     Reads SPI frame (3.2 μs)
  │     Stores V[n], I[n] into circular buffer
  │     Every 67 samples (1 cycle at 4 kSPS):
  │       - Compute Vrms, Irms, P, Q, S, PF (SIMD-accelerated)
  │       - Accumulate energy delta (Wh)
  │       - Update shared MeterData struct (mutex)
  │     Every 2 seconds (triggered or periodic):
  │       - Run 128-point FFT on V and I buffers (esp-dsp SIMD)
  │       - Extract harmonic magnitudes and phases
  │       - Compute THD, crest factor, harmonic ratios
  │       - Run classification decision tree
  │       - Update shared ClassificationData struct (mutex)
  │
  └── other Core 0 tasks (relay control, watchdog, etc.)

Core 1:
  └── tdmaTask (priority 6, unchanged)
        Snapshots MeterData + ClassificationData at transmit time
        Packs into extended TelemetryPacket
        Transmits in assigned TDMA slot
```

### 11.2 Memory Requirements — ESP32-S3 (512 KB SRAM)

| Buffer | Size | Notes |
|---|---|---|
| ADC circular buffer (V) | 256 × 4 bytes = 1024 B | 3.8 cycles at 4 kSPS |
| ADC circular buffer (I) | 256 × 4 bytes = 1024 B | Mirrored |
| FFT working buffer | 256 × 8 bytes = 2048 B | Complex float pairs |
| Harmonic feature vector | 30 × 4 bytes = 120 B | 15 harmonics × 2 channels |
| Total DSP RAM | ~4.2 KB | Well within ESP32-S3's 512 KB SRAM |

### 11.3 Computational Budget (ESP32-S3, LX7 @ 240 MHz with SIMD)

| Operation | Frequency | Time per Execution | CPU Load |
|---|---|---|---|
| SPI frame read | 4000/s | 3.2 μs | 1.28% |
| Per-sample multiply-accumulate | 4000/s | ~0.1 μs | 0.04% |
| Cycle-end RMS + power computation | 60/s | ~10 μs | 0.06% |
| 128-point FFT (SIMD) | 0.5/s | ~15 μs | 0.0008% |
| Classification decision tree | 0.5/s | ~5 μs | 0.0003% |
| **Total DSP load on Core 0** | — | — | **~1.4%** |

This leaves over 98% of Core 0's capacity free for other tasks.

### 11.4 Computational Budget (STM32F411, Cortex-M4F @ 100 MHz, no SIMD)

The STM32F411 uses an ARM Cortex-M4 core with a hardware single-precision FPU but no SIMD instructions. All DSP operations execute as scalar floating-point, and the clock is 2.4x slower than the ESP32-S3. Additionally, the STM32F411 is single-core — the ADC acquisition, metering DSP, classification, and TDMA radio all share a single execution context and must be managed through interrupt priorities and cooperative scheduling.

**DSP library.** The ARM CMSIS-DSP library provides optimised implementations of FFT (`arm_cfft_f32`), RMS, dot product, and other vector operations. While not SIMD-accelerated on the M4 (SIMD requires Cortex-M7 or higher with Helium/MVE), the CMSIS-DSP routines use mixed-radix algorithms and loop unrolling that are significantly faster than naive implementations.

**Timing estimates.** A 128-point complex FFT using `arm_cfft_f32` on the Cortex-M4 at 168 MHz has been benchmarked at approximately 40 $\mu$s. Scaling to 100 MHz:

$$t_{\text{FFT,128}} = 40 \times \frac{168}{100} \approx 67 \text{ } \mu\text{s per FFT}$$

Two FFTs (one for V, one for I) require approximately 134 $\mu$s total — still negligible relative to the 250 $\mu$s inter-sample period at 4 kSPS.

**SPI bus allocation.** The STM32F411 has three SPI peripherals (SPI1, SPI2, SPI3). The ADS131M02 and SX1276 are assigned to separate SPI buses, eliminating bus contention:

- SPI1: ADS131M02 (SCLK up to 25 MHz)
- SPI2: SX1276 LoRa radio (SCLK up to 10 MHz)

Both SPI peripherals can use DMA for data transfer, freeing the CPU during multi-byte transactions.

**ADC acquisition via DMA.** The DRDY pin of the ADS131M02 triggers a GPIO EXTI interrupt. The ISR initiates a DMA-driven SPI read of the 80-bit frame. When the DMA transfer completes, a DMA completion ISR copies the two 24-bit sample values into the circular buffer. The CPU overhead per sample is limited to the ISR entry/exit and the DMA setup — approximately 5 $\mu$s total, not the full SPI transaction time.

| Operation | Frequency | Time per Execution | CPU Load |
|---|---|---|---|
| DRDY ISR + DMA SPI read | 4000/s | ~5 μs | 2.00% |
| Per-sample multiply-accumulate (V×I, V², I²) | 4000/s | ~0.2 μs | 0.08% |
| Cycle-end RMS + power computation | 60/s | ~20 μs | 0.12% |
| PGA gain-ranging check | 60/s | ~2 μs | 0.01% |
| 128-point FFT × 2 channels (CMSIS-DSP) | 0.5/s | ~134 μs | 0.007% |
| Harmonic magnitude + phase extraction | 0.5/s | ~20 μs | 0.001% |
| Classification decision tree | 0.5/s | ~10 μs | 0.0005% |
| **Total DSP load** | — | — | **~2.2%** |
| TDMA radio (packet build + SPI + TX wait) | ~0.1/s | ~5 ms | ~0.05% |
| **Total CPU load (DSP + radio)** | — | — | **~2.3%** |

The STM32F411 handles the full workload with approximately 97.7% idle capacity. The DSP load is roughly 1.6x higher than the ESP32-S3 (2.2% vs 1.4%), primarily due to the slower clock and scalar-only FPU. The FFT is the operation most affected by the absence of SIMD — approximately 4.5x slower per FFT (67 $\mu$s vs 15 $\mu$s) — but since it runs only twice per second, the impact on total CPU load is negligible.

**Interrupt priority scheme.** On the single-core STM32F411, correct interrupt nesting is essential to prevent the TDMA radio from blocking ADC sample acquisition:

```
Priority 0 (highest): DRDY EXTI ISR — initiates DMA SPI read for ADS131M02
Priority 1:           DMA completion ISR — stores samples, triggers cycle-end processing
Priority 2:           SysTick — FreeRTOS tick (1 ms)
Priority 3:           Radio DIO0 ISR — SX1276 TX/RX done interrupt
Priority 4 (lowest):  PendSV — FreeRTOS context switch
```

The DRDY interrupt at priority 0 ensures that no ADC sample is ever missed, even if the CPU is in the middle of a radio SPI transaction or FreeRTOS context switch. The DMA handles the actual SPI data transfer in hardware, so the ISR returns quickly (~1 $\mu$s).

### 11.5 FreeRTOS Task Architecture — STM32F411 (Single-Core)

```
Single core (Cortex-M4F @ 100 MHz):

  ├── adcTask (priority: osPriorityAboveNormal)
  │     Woken by DMA completion notification (binary semaphore)
  │     Copies V[n], I[n] from DMA buffer into circular buffer
  │     Per-sample: accumulate V², I², V×I for running RMS/power
  │     Every 67 samples (1 cycle at 4 kSPS):
  │       - Finalise Vrms, Irms, P, Q, S, PF
  │       - Check PGA gain range, adjust if needed (SPI register write)
  │       - Accumulate energy delta (Wh)
  │       - Update shared MeterData struct (mutex)
  │     Every 2 seconds (or on power-change trigger):
  │       - Run 128-point FFT on V and I buffers (CMSIS-DSP arm_cfft_f32)
  │       - Extract harmonic magnitudes and phases
  │       - Compute THD, crest factor, harmonic ratios
  │       - Run classification decision tree
  │       - Update shared ClassificationData struct (mutex)
  │
  ├── tdmaTask (priority: osPriorityNormal)
  │     Sleeps until TDMA slot timer fires
  │     Snapshots MeterData + ClassificationData under mutex
  │     Builds TelemetryPacket
  │     Transmits via SX1276 on SPI2 (DMA-driven)
  │     Waits for DIO0 TX-done interrupt
  │     Returns to sleep
  │
  └── sysTask (priority: osPriorityBelowNormal)
        Watchdog feed
        LED status blink
        Relay control (if applicable)
        Low-priority housekeeping
```

The adcTask runs at higher priority than tdmaTask to ensure metering computation is never starved by radio operations. The DRDY ISR and DMA run at interrupt level above all tasks, guaranteeing zero dropped samples regardless of task-level activity.

### 11.6 Memory Requirements — STM32F411 (128 KB SRAM)

| Buffer | Size | Notes |
|---|---|---|
| ADC circular buffer (V) | 256 × 4 bytes = 1024 B | 3.8 cycles at 4 kSPS |
| ADC circular buffer (I) | 256 × 4 bytes = 1024 B | Mirrored |
| DMA SPI receive buffer | 10 × 2 = 20 B | Double-buffered, 10 bytes per frame |
| FFT working buffer | 256 × 8 bytes = 2048 B | Complex float pairs (CMSIS-DSP in-place) |
| Harmonic feature vector | 30 × 4 bytes = 120 B | 15 harmonics × 2 channels |
| MeterData struct | ~48 B | Vrms, Irms, P, Q, S, PF, energy, timestamp |
| ClassificationData struct | ~32 B | Class, subclass, confidence, THD, crest |
| SX1276 TX/RX buffer | 256 B | LoRa packet buffer |
| FreeRTOS kernel + 3 task stacks | ~10 KB | 3 tasks × ~2 KB stack + kernel objects |
| **Total RAM usage** | **~14.6 KB** | **11.4% of 128 KB SRAM** |

The STM32F411's 128 KB SRAM is more than adequate. Over 113 KB remains free for application code variables, calibration tables, and any future expansion.

### 11.7 Comparison: ESP32-S3 (LX7) vs STM32F411 (Cortex-M4F)

| Parameter | ESP32-S3 (LX7) | STM32F411 (Cortex-M4F) |
|---|---|---|
| Clock speed | 240 MHz | 100 MHz |
| Cores | 2 (dual-core) | 1 (single-core) |
| FPU | Single-precision | Single-precision |
| SIMD | PIE (128-bit, 4-wide) | None |
| DSP library | esp-dsp (SIMD-optimised) | CMSIS-DSP (scalar-optimised) |
| 128-pt FFT time | ~15 μs | ~67 μs |
| Total DSP CPU load | ~1.4% (Core 0 only) | ~2.2% |
| Radio isolation | Core 1 (hardware isolation) | Priority-based preemption |
| SRAM | 512 KB | 128 KB |
| DSP RAM usage | ~4.2 KB (0.8% of SRAM) | ~14.6 KB (11.4% of SRAM) |
| SPI peripherals | 4 (FSPI, SPI2, SPI3, +) | 3 (SPI1, SPI2, SPI3) |
| DMA channels | Limited (GDMA) | 16 streams (2 controllers) |
| ADC sample drop risk | None (dedicated core) | Negligible (ISR priority 0) |
| Overall headroom | 98.6% free on Core 0 | 97.7% free |

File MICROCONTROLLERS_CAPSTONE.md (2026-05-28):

# ESP32-Based LoRa TDMA Power Telemetry System for Multi-Node AC Load Monitoring and Remote Control

College of Engineering Education
University of Mindanao 

---

*Abstract*—This paper presents the design, implementation, and evaluation of a wireless power telemetry system capable of monitoring and remotely controlling up to eight alternating-current (AC) loads in real time without dependence on cloud infrastructure or cellular networks. The system pairs the ESP32 microcontroller with the SX1278 LoRa radio transceiver and implements a custom Time Division Multiple Access (TDMA) protocol over a frequency-hopping physical layer in the 433 MHz ISM band. A gateway node (ESP32-dev) hosts a web-based single-page application (SPA) served from on-chip flash and exposes a REST and WebSocket API over Wi-Fi. Up to eight sensor nodes (ESP32-S3 Super Mini), each interfacing a PZEM-004T v3 power meter and an AC relay, transmit six electrical measurements per superframe (3-second period) and respond to relay commands within one scheduling cycle. Energy totals and telemetry history are persisted across power cycles to a Ferroelectric RAM (FRAM) chip. The design demonstrates that a deterministic, collision-free multi-node telemetry architecture can be achieved on commodity embedded hardware at a fraction of the cost of commercial smart-metering platforms, while remaining fully self-contained and field-deployable.

*Index Terms*—ESP32, LoRa, TDMA, power telemetry, AC load monitoring, PZEM-004T v3, frequency hopping, FreeRTOS, FRAM, WebSocket, ISM band, energy metering.

---

## I. INTRODUCTION

The proliferation of distributed electrical loads in residential buildings, small enterprises, and light industry has created a pressing need for low-cost, real-time energy visibility and control. Conventional approaches to smart metering either rely on power-line communication (PLC), which requires AC wiring access [1], or on cloud-connected Wi-Fi modules, which impose per-device subscription costs and introduce single points of failure whenever Internet connectivity is degraded [2]. Low-Power Wide-Area Networks (LPWANs), and LoRa in particular, have emerged as a compelling alternative: they offer kilometre-range wireless links at milliwatt transmit powers and operate on unlicensed spectrum, requiring no telecommunications infrastructure beyond the gateway [3].

However, off-the-shelf LoRa solutions such as LoRaWAN impose architectural constraints—star-of-stars topology, network servers, join procedures, and adaptive data-rate algorithms—that are unnecessarily heavy for a closed, single-site deployment of fewer than eight nodes [4]. Furthermore, the LoRaWAN class-A downlink model, which restricts gateway-to-node transmissions to two narrow receive windows following a node's uplink, is a poor fit for relay control: the operator expects a command to take effect within seconds, not after the next uplink cycle.

This project therefore implements a custom TDMA MAC layer directly atop the LoRa physical layer, purpose-built for the following operational profile:

1. Up to eight sensor nodes, each measuring voltage, current, active power, energy, frequency, and power factor on one AC circuit.
2. Sub-3-second telemetry update rate and sub-3-second command delivery latency from the dashboard to any node.
3. Full bidirectionality in every superframe: each node receives a downlink command slot and transmits an uplink telemetry slot within the same 3-second period.
4. A self-hosted, browser-accessible dashboard served directly from the gateway—no cloud, no mobile app, no installation required.
5. Persistence of energy totals and history across power cycles.

The contribution of this work is not the invention of any individual technique—LoRa, TDMA, and FRAM are all well-established—but their integration into a coherent, production-grade embedded system whose design trade-offs are explicitly motivated by the constraints of field deployment on commodity hardware.

---

## II. BACKGROUND AND RELATED WORK

### A. Wireless Sensor Networks for Energy Monitoring

Energy monitoring using wireless sensor networks (WSNs) has been an active research area for over two decades. Akyildiz et al. [5] established the canonical WSN reference architecture: a dense field of resource-constrained sensor motes communicates through multi-hop or star topologies to a coordinator that aggregates data for analysis. In energy-monitoring contexts, the critical performance metrics are measurement accuracy, data freshness, command latency, and system lifetime.

Commercial smart-meter deployments typically use PLC or narrowband RF (e.g., Zigbee, Z-Wave) for last-metre communication. While PLC leverages existing wiring infrastructure [1], it is susceptible to conducted noise from motor loads and requires per-circuit hardware modifications. Zigbee's 2.4 GHz band suffers high attenuation through masonry walls common in Philippine construction [6], and Z-Wave's mesh-routing overhead introduces variable command latency incompatible with near-real-time relay switching.

### B. LoRa and LPWAN Technology

LoRa uses chirp spread-spectrum (CSS) modulation patented by Semtech [7], which spreads narrowband signals across a wider bandwidth to achieve robustness against multipath fading and narrowband interference. Augustin et al. [3] conducted a comprehensive characterisation of LoRa across spreading factors SF6–SF12, bandwidths 125–500 kHz, and coding rates 4/5–4/8. They showed that lower spreading factors (SF6–SF7) offer the best throughput-per-channel efficiency at short to medium ranges (under 500 m), while higher SFs extend range at the cost of dramatically increased time-on-air. For a 125 kHz, SF6 configuration, the 32-byte TelemetryPacket achieves a time-on-air of approximately 34 ms, compared to over 1.3 seconds at SF12—a 40× reduction that is decisive for TDMA slot budget calculations.

Bor et al. [4] demonstrated experimentally that uncoordinated LoRa networks suffer from destructive co-channel collisions even at moderate node densities because ALOHA-style random access cannot guarantee collision avoidance. They argued for coordinated MAC protocols and showed that a properly scheduled network can approach the theoretical channel capacity. This result directly motivates the TDMA approach taken in this project.

The LoRaWAN specification [8], maintained by the LoRa Alliance, defines a star-of-stars architecture with dedicated network servers managing join, data-rate adaptation, and downlink scheduling. While LoRaWAN is appropriate for wide-area IoT deployments with large node populations and mixed operators, Georgiou and Raza [9] note that its class-A downlink constraint (two fixed receive windows, 1 s and 2 s after each uplink) introduces latency that is unacceptable for latency-sensitive actuator control. Class-B (beacon-scheduled) and class-C (always-on receive) partially address this but increase node complexity and power consumption. The custom TDMA design in this project provides class-B equivalent latency without the beacon synchronisation overhead of LoRaWAN.

### C. TDMA MAC Protocols for Wireless Sensor Networks

Time Division Multiple Access has been the dominant deterministic MAC protocol in WSNs since the publication of LEACH [10] and its successors. Demirkol et al. [11] survey TDMA-based WSN MAC protocols including LMAC, SMAC, TRAMA, and IEEE 802.15.4 TSCH, noting that TDMA eliminates idle listening and overhearing (primary energy wasters in contention-based MACs) and provides bounded worst-case latency—O(1) in the number of nodes regardless of network load.

TSCH (Time Slotted Channel Hopping), standardised in IEEE 802.15.4e [12], combines TDMA scheduling with channel hopping to mitigate multipath fading and interference, achieving packet delivery ratios above 99% in industrial environments. The frequency-hopping channel plan in this project borrows the same principle: a coprime-multiplier schedule ensures that over eight consecutive superframes, each data slot visits all eight channels exactly once, distributing exposure to narrowband interference without requiring the full TSCH coordinator infrastructure.

Palattella et al. [6] show that anchor-based per-superframe re-synchronisation achieves sub-millisecond timing accuracy on comparable 32-bit embedded platforms, confirming that the simple beacon-anchored timing model used here is sufficient for the 100 ms UL receive window.

### D. PZEM-004T v3 for Embedded Energy Metering

The PZEM-004T v3 is a low-cost AC energy measurement module based on the BL0906 metering IC, interfaced via a Modbus RTU UART protocol at 9600 baud. It measures voltage, current, active power, accumulated energy, frequency, and power factor across a single phase. Taner et al. [13] evaluated the PZEM-004T v3 against calibrated reference instruments across a range of resistive, inductive, and capacitive loads and reported measurement errors within ±1% for voltage, ±1.5% for current, and ±2% for power factor—acceptable for load-monitoring and demand-management applications. Al-Rousan et al. [14] deployed similar low-cost Modbus energy meters in a university building energy audit and demonstrated that aggregate energy consumption estimates based on these meters agreed with utility billing data to within 3%.

The PZEM internal energy counter rolls over at 9,999,990 Wh. A node-side delta encoding scheme—transmitting the Wh increment since the previous sample rather than the absolute counter value—makes the gateway's accumulated energy total immune to both counter rollovers and node power-cycle resets, as recommended in IEC 62056-21 [15] for interoperable energy meter data exchange.

### E. Real-Time Operating Systems on ESP32

The ESP32 integrates two Xtensa LX6 cores and ships with the Espressif IoT Development Framework (ESP-IDF), which bundles a FreeRTOS port. Rao et al. [16] benchmark FreeRTOS task switching on the ESP32 and confirm deterministic context-switch times under 10 µs, adequate for the microsecond-level TDMA timing discipline required here. A known issue documented by Espressif [17] is that the Wi-Fi stack, which runs on Core 0, can temporarily monopolise the core during association and DHCP procedures, causing multi-millisecond delays for tasks on the same core. Pinning the TDMA radio task exclusively to Core 1 at a higher priority than all Core 0 tasks isolates the timing-critical radio path from Wi-Fi interference entirely.

### F. FRAM for High-Endurance Data Logging

Ferroelectric RAM (FRAM) combines the byte-addressability of SRAM with the non-volatility of EEPROM, offering write endurance exceeding 10¹² cycles versus approximately 10⁴–10⁵ cycles for NOR flash [18]. Wahab et al. [18] evaluated FRAM against flash for data logging in power-line monitoring applications and concluded that FRAM is the preferred medium for energy accumulation registers, which require frequent, small writes. At a 3-second superframe period and a dirty-flush threshold of 10 packets, energy registers are written to FRAM approximately every 30 seconds per node—a rate that would exhaust a typical flash cell in under six months of continuous operation, but is negligible against FRAM's 10¹² cycle budget.

---

## III. PROBLEM STATEMENT

Existing approaches to multi-circuit AC energy monitoring in small-scale deployments present one or more of the following limitations:

1. **Cloud dependency:** Consumer smart-plug platforms (Tuya, Shelly) require Internet connectivity and third-party servers. Loss of connectivity interrupts both telemetry collection and relay control.
2. **Single-circuit granularity:** Most Wi-Fi-connected meters are designed for one circuit per gateway device. Scaling to eight circuits requires eight independent network devices, eight SSIDs or DHCP leases, and eight independent web interfaces.
3. **Collision-prone uplinks:** LoRaWAN and similar ALOHA-based schemes suffer degraded packet delivery at higher node densities due to co-channel collisions.
4. **Poor actuator latency:** LoRaWAN class-A limits downlink delivery to post-uplink windows. In a 3-second superframe, worst-case command delivery is 3 seconds; in LoRaWAN at SF12, it can exceed one minute.
5. **Data loss on power cycle:** Systems that store energy totals in SRAM or NOR flash face either total loss on power failure or accelerated flash wear from frequent counter updates.

This project directly addresses all five limitations through a unified embedded system design.

---

## IV. RESEARCH OBJECTIVES

The primary objective of this project is to design, implement, and validate a self-contained wireless AC load monitoring and control system that meets the following measurable criteria:

1. **O1—Multi-node coverage:** Support up to 8 sensor nodes within a single TDMA superframe, each delivering 6 electrical measurements per 3-second period.
2. **O2—Command latency:** Deliver relay commands from the web dashboard to any registered node within one superframe period (≤3 s) in at least 95% of transmissions under normal conditions.
3. **O3—Measurement accuracy:** Achieve voltage and current measurement errors within the PZEM-004T v3 specification (±1% and ±1.5% respectively) as validated against a calibrated reference.
4. **O4—Persistence:** Preserve accumulated energy totals and the 120-point telemetry history ring buffer across gateway and node power cycles, with no data loss for power failures occurring between dirty-flush intervals (≤30 s).
5. **O5—Self-containment:** Operate without Internet connectivity or external servers; the dashboard must be fully functional on the gateway's AP-mode network.
6. **O6—Collision-free delivery:** Achieve uplink packet delivery ratio ≥95% under full 8-node network load using the TDMA schedule.
7. **O7—Schedule reliability:** Relay schedules programmed via the dashboard must activate and deactivate within ±10 seconds of the programmed time, tolerating gateway browser-clock jitter.

---

## V. SYSTEM DESIGN AND METHODOLOGY

### A. Overview and Role Architecture

The firmware is compiled from a single codebase into two mutually exclusive binary roles via PlatformIO build environments. The `NODE_GATEWAY` preprocessor flag produces the gateway binary, which includes the web server, FRAM driver, TDMA master, and Wi-Fi stack. The `NODE_TELEMETRY` flag produces the sensor node binary, which includes the PZEM driver, relay control, TDMA slave, and LED state indicator. This technique of conditional compilation for role differentiation [19] ensures that shared protocol constants—packet structs, timing constants, channel plan—remain identical on both ends with no risk of divergence.

The network topology is a star: one gateway and up to eight leaf nodes, all communicating on the 433 MHz ISM band. Star topologies are well-established in WSN literature [5] as the appropriate choice when a mains-powered coordinator can absorb scheduling and aggregation complexity, and when the node population is small enough that multi-hop routing adds no coverage benefit.

### B. Physical Layer -- LoRa at SF6

The SX1278 LoRa transceiver is configured as shown in Table I. SF6 is the lowest spreading factor available on the SX1278, yielding a symbol duration of 0.512 ms and maximum data throughput for the class. The 8-byte BeaconPacket achieves a time-on-air of 18 ms; the 32-byte TelemetryPacket approximately 34 ms. Choosing SF6 over SF7 or SF9 reduces the TelemetryPacket airtime by approximately 48% and 87% respectively, directly reducing the TDMA slot width and hence the superframe period. The resulting link budget of approximately 126 dB at 10 dBm output (SX1278 SF6 sensitivity ≈ −118 dBm [20]) is adequate for intra-building and short outdoor ranges of 100–300 m, which covers the intended deployment environment.

**TABLE I**  
**LoRa Physical Layer Configuration**

| Parameter | Value |
| :--- | :--- |
| Frequency | 433 MHz ISM band |
| Bandwidth | 125 kHz |
| Spreading Factor | SF6 |
| Coding Rate | 4/5 |
| TX Power | 10 dBm (PA_BOOST) |
| Sync Word | 0x12 (private network) |
| Preamble length  | 8 symbols |

Eight channels at 200 kHz spacing (433.05–434.45 MHz) constitute the frequency-hopping plan. Channel 0 is the fixed rendezvous channel for beacons and contention. Data slots hop per the function `ch = (sfCount × 7 + slotId) mod 8`, where the multiplier 7 is coprime to 8, guaranteeing that over eight superframes every slot visits every channel exactly once [12]. This distributes narrowband interference across all slots without requiring inter-node coordination.

### C. MAC Layer -- Custom TDMA Protocol

#### 1) Superframe Structure

The protocol time-divides the radio channel into repeating 3000 ms superframes:

```
|<————————————————————————————— 3000 ms —————————————————————————————>|
| Beacon | Slot 1 | Slot 2 | ... | Slot 8 | CW UL | CW DL | Idle | Guard |
|  40 ms | 165 ms | 165 ms |     | 165 ms | 60 ms | 40 ms | 1520 ms| 20 ms |
```

Each 165 ms data slot is ordered DL-first: the gateway transmits any pending command in the first 50 ms (DL window), the node transmits its telemetry in the following 100 ms (UL window), and a 15 ms guard absorbs PLL re-lock latency between frequency hops. DL-first ordering allows the node to receive and act on a relay command—updating its relay output and status byte—before composing and transmitting the uplink that confirms the new state in the same slot. This eliminates one superframe of command-confirmation lag compared to UL-first ordering.

The 1520 ms idle window following the contention phase serves three purposes: it provides time for gateway maintenance tasks (node eviction, deferred FRAM writes dispatched over a FreeRTOS queue); it reduces the ISM-band duty cycle to comply with European ETSI EN 300 220 1% limits [21]; and it leaves room for future superframe extension if additional protocol overhead is required.

#### 2) Beacon and Time Synchronisation

At the start of every superframe the gateway broadcasts an 8-byte `BeaconPacket` on Channel 0. The beacon carries the superframe counter `sfCount` (hop-sequence seed), the occupied-slot bitmask `slotMask`, a network epoch counter, and the current gateway time in H/M/S format for relay schedule synchronisation.

Nodes derive slot timing from the beacon receive timestamp via:

```
dlStart = beaconReceiveTime + (BEACON_MS - BEACON_AIR_MS) + (slotId - 1) x SLOT_PAIR_MS
txTime  = dlStart + SLOT_DL_MS
```

Subtracting `BEACON_AIR_MS = 18 ms` recovers the gateway's superframe start from the node's receive time, compensating for beacon propagation. This per-superframe re-anchoring prevents drift accumulation, as confirmed by Palattella et al. [6].

#### 3) Dynamic Registration via Contention Window

Nodes join the network through a slotted contention window (CW) appended after the last data slot. A new node transmits a 4-byte `JoinRequestPacket` encoding a 16-bit device UID derived from the ESP32's factory-burned eFuse MAC address via CRC-16/CCITT (poly 0x1021, init 0xFFFF). A random backoff of 0–25 ms reduces the collision probability when multiple nodes contend simultaneously. The gateway responds with a 4-byte `JoinAckPacket` assigning a slot ID. This random-access join mechanism is analogous to the RACH procedure in LTE [22] and requires no pre-provisioning.

#### 4) Network Epoch and Slot Invalidation

The `BeaconPacket` carries an 8-bit `epoch` counter, initialised to a random value at gateway boot and incremented on every node eviction. Each registered node caches the epoch value received in its `JoinAck`. If a subsequently received beacon carries a different epoch, the node immediately discards its slot assignment and re-enters the contention state. This mechanism guarantees that a node whose slot has been reclaimed by an eviction event will not transmit into a slot now belonging to a different device, eliminating the "ghost uplink" problem that arises in TDMA systems without slot-invalidation signalling [23].

Eviction is deliberately conservative: the gateway only reclaims a slot when all eight slots are occupied (`slotMask == 0xFF`) and the target node has missed eight consecutive superframes (~24 seconds). When free slots are available, stale nodes retain their slot assignment so they can rejoin without contention after a brief power interruption.

### D. Sensor Subsystem -- PZEM-004T v3

Each sensor node interfaces a PZEM-004T v3 power meter on UART2 using the Modbus RTU protocol at 9600 baud. The meter measures voltage (80–260 V AC), current (0–100 A), active power (0–23 kW), accumulated energy (0–9,999,990 Wh), frequency (45–65 Hz), and power factor (0.00–1.00). An AC relay controlled by the ESP32 allows the dashboard to energise or de-energise the monitored load.

PZEM reads are executed in a dedicated FreeRTOS task (`pzemTask`) pinned to Core 0 at 500 ms intervals, decoupled entirely from the TDMA radio task on Core 1. A mutex protects the shared `PzemData` struct. Because the sampling period (500 ms) is well under the superframe period (3000 ms), the data available at uplink time is always less than one sampling interval old. A second mutex-protected pathway allows the TDMA task to queue a `setPowerAlarm()` command, which is consumed by `pzemTask` as the sole owner of the Modbus bus—eliminating serial-port races without blocking the radio task.

Node-side delta encoding transmits the Wh increment since the previous sample. The gateway accumulates these deltas into a 32-bit total (`accumEnergy`), making it immune to counter rollovers at 9,999,990 Wh and to power-cycle resets of the PZEM, per IEC 62056-21 [15].

### E. Packet Design

All packet structures are `#pragma pack(1)` to eliminate compiler-inserted padding, ensuring byte-exact layout between the node's transmit buffer and the gateway's receive buffer across any GCC version or target architecture [19]. Floating-point values are encoded as scaled integers (voltage ÷ 10, current ÷ 1000, power ÷ 10, frequency ÷ 10, power factor ÷ 100). The 32-byte `TelemetryPacket` includes not only the six electrical measurements but also a rolling sequence counter (for packet-loss detection), the node's last-heard beacon RSSI (for link diagnostics), firmware version, relay schedule state, and alarm threshold—allowing the gateway to reconstruct the complete node state from each uplink without additional side-channel messages.

A 2-byte `DlHeader` (pktType, nodeId) prefixes every downlink packet. All downlink frames are zero-padded to `MAX_DL_PAYLOAD_LEN = 7` bytes (the size of the largest command, `RelaySchedulePacket`) so the SF6 implicit-header RX window can use a fixed receive length, avoiding the 4-byte explicit-header overhead on every slot. The complete packet type inventory is given in Table II.

**TABLE II**  
**Packet Type Inventory**

| Packet | ID | Direction  | Bytes |
| :--- | :--- | :--- | :---- |
| BeaconPacket | 0x04 | GW -> All  | 8 |
| TelemetryPacket | 0x01 | Node -> GW | 32 |
| RelayCommandPacket  | 0x02 | GW -> Node | 3 |
| RelaySchedulePacket | 0x03 | GW -> Node | 7 |
| RelayClearPacket | 0x05 | GW -> Node | 2 |
| ThresholdPacket | 0x06 | GW -> Node | 4 |
| NudgePacket | 0x07 | GW -> Node | 2 |
| JoinRequestPacket | 0xA0 | Node -> GW | 4 |
| JoinAckPacket | 0xA1 | GW -> Node | 4 |

### F. Application Layer -- Web Dashboard

The gateway serves a static Single-Page Application from LittleFS flash, gzip-compressed at build time by a PlatformIO pre-script to maximise the effective SPA payload within the 1 MB LittleFS partition. The SPA displays live telemetry for all registered nodes, a 120-point historical chart (voltage, current, power), relay control and scheduling UI, alarm threshold configuration, Wi-Fi credential management, and a live serial console relayed over WebSocket.

The REST API provides stateless resource queries (`/api/nodes`, `/api/node/{id}/live`, `/api/node/{id}/history`, `/api/status`) and HTTP fallback endpoints for relay, rename, and time-setting operations. All dynamic dashboard interactions use a persistent WebSocket connection (`/ws`), delivering telemetry push events and command results with the sub-100 ms round-trip latency of a persistent TCP connection rather than the polling overhead of HTTP long-polling [24].

The dual-AP+STA Wi-Fi state machine allows the gateway to simultaneously host an access point (192.168.4.1, captive-portal DNS) for direct browser access and connect to an existing station network for broader LAN visibility. A DNS catch-all on the AP redirects all hostnames to the gateway, supporting the captive-portal detection flows of Android, iOS, Windows, and Firefox OS [25].

### G. Data Persistence -- FRAM

The MB85RC256V FRAM chip (32 KB, I²C at 400 kHz) stores per-node energy totals, 120-point history ring buffers, and human-readable node labels. FRAM's >10¹² write-cycle endurance [18] accommodates the continuous writes required by a 3-second telemetry cycle far beyond any realistic system lifetime.

A deferred-write architecture dispatches FRAM I²C operations to a dedicated `framTask` (Core 0, lowest priority) via a FreeRTOS queue, ensuring that multi-millisecond I²C transactions (e.g., ~47 ms for a full 1920-byte history write at 400 kHz) never block the Core 1 TDMA task. Energy registers are flushed every 10 received packets (~30 s); history every 10 samples (~30 s); labels immediately on rename.

On node join, a cross-slot UID lookup searches all eight FRAM blocks by device UID, recovering the node's data regardless of which slot index it was previously assigned. This ensures that labels, energy totals, and history survive gateway reboots even when slot assignments change—addressing the most common persistence failure mode in dynamic TDMA networks.

---

## VI. IMPLEMENTATION

The firmware is developed in C++11 under the Arduino framework on PlatformIO, targeting the `esp32dev` board profile for the gateway and `esp32s3_supermini` for the ESP32-S3 Super Mini sensor nodes. Three build environments cover the role (gateway/node) and PZEM mode (hardware/simulated) combinations used in this project, as listed in Table III.

**TABLE III**  
**PlatformIO Build Environments**

| Environment | Board | Role | PZEM |
| :--- | :--- | :--- | :--- |
| `gateway` | esp32dev | Gateway | n/a |
| `node_s3` | S3 Super Mini | Node | Hardware  |
| `node_s3_nettest` | S3 Super Mini | Node | Simulated |

The `node_s3_nettest` environment replaces PZEM hardware reads with a simulated task (`fakePzemTask`) that generates sinusoidal voltage/current waveforms. This environment allows full protocol testing—including join, telemetry, relay commands, schedule activation, and epoch-driven re-registration—without requiring AC metering hardware, significantly accelerating iterative development.

All `Serial.print` calls route through a non-blocking ring-buffer logger (`log_async.h`) drained by a low-priority Core 0 task. This keeps the TDMA timing loop on Core 1 free from blocking UART writes. Log lines are also forwarded to connected WebSocket clients as `{"type":"log","line":"..."}` events, enabling a live serial console in the browser without a USB connection.

### A. Gateway Hardware

**Gateway Schematic**

Gateway Schematic

**Gateway PCB Layout**

Gateway PCB

### B. Sensor Node Hardware

**Sensor Node Schematic**

Sensor Node Schematic

**Sensor Node PCB Layout**

Sensor Node PCB

---

## VII. EXPECTED OUTCOMES AND SIGNIFICANCE

### A. Technical Outcomes

Upon completion, the system is expected to demonstrate:

- **Collision-free uplink delivery:** With all 8 slots occupied, every node transmits in a TDMA-allocated window; uplink PDR is expected to exceed 99% in the absence of severe co-channel interference, consistent with TSCH benchmarks [12].
- **Command latency ≤ 3 s:** Relay commands queued in the WebSocket handler are delivered to the target node in the next DL window, within one superframe.
- **Measurement agreement:** Voltage, current, and power readings will be validated against a calibrated clamp meter and utility-grade reference meter. Expected agreement is within ±1% for voltage and ±2% for power, per PZEM-004T v3 characterisation [13].
- **Energy continuity:** Accumulated energy totals will survive simulated power cycles with zero loss, verified by comparing pre- and post-reboot totals against the PZEM's internal register.
- **Epoch recovery:** Simulated gateway reboots with all 8 slots occupied will confirm that all nodes re-register and resume uplink delivery within 3–5 superframes.

### B. Broader Significance

The system addresses a practical gap in the energy-monitoring landscape for small-scale and off-grid deployments in the Philippines and comparable markets:

- **Affordability:** The complete gateway hardware costs approximately PHP 1,200–1,500 (USD 20–25) and each sensor node approximately PHP 800–1,000 (USD 14–17), versus PHP 8,000–15,000 for equivalent commercial multi-circuit smart-meter gateways.
- **Infrastructure independence:** Operation on the 433 MHz ISM band with a self-hosted SPA dashboard eliminates recurring connectivity and subscription costs, making the system viable in areas with unreliable Internet service.
- **Extensibility:** The open TDMA protocol and open-source firmware provide a foundation for extensions such as reactive power measurement, differential protection triggering, demand-response automation, or integration with local building management systems via the REST API.
- **Academic contribution:** The integration of a custom TDMA MAC, frequency-hopping physical layer, dual-clock schedule reliability, network-epoch slot invalidation, and deferred cross-slot FRAM restore into a single embedded system on commodity hardware represents a practical reference design for future multi-node LoRa telemetry projects.

---

## VIII. CONCLUSION

This paper has presented the motivation, literature basis, design objectives, and architecture of an ESP32-based LoRa TDMA power telemetry system. The system synthesises well-established techniques—TDMA MAC scheduling [11], LoRa CSS physical layer [3], frequency-hopping interference mitigation [12], PZEM-004T v3 AC metering [13], FRAM persistence [18], and FreeRTOS dual-core task pinning [17]—into a coherent, production-grade embedded platform that operates entirely without cloud infrastructure.

Key design innovations include the DL-first TDMA slot ordering for single-cycle command confirmation, the network epoch mechanism for deterministic slot invalidation after eviction, the cross-slot UID-based FRAM restore that survives slot reassignment across reboots, and the deferred FRAM write queue that keeps I²C latency off the timing-critical radio path. Together, these choices make the system robust in the face of the power interruptions, node churn, and browser-clock jitter typical of real-world field deployments.

---

## REFERENCES

[1] H. Ferreira, L. Lampe, J. Newbury, and T. Swart, *Power Line Communications: Theory and Applications for Narrowband and Broadband Communications Over Power Lines*. Wiley, 2010.

[2] F. Al-Turjman and M. Abujubbeh, "IoT-enabled smart grid via SM: An overview," *Future Generation Computer Systems*, vol. 96, pp. 579–590, 2019. doi:10.1016/j.future.2019.02.012

[3] A. Augustin, J. Yi, T. Clausen, and W. M. Townsley, "A Study of LoRa: Long Range & Low Power Networks for the Internet of Things," *Sensors*, vol. 16, no. 9, p. 1466, Sep. 2016. doi:10.3390/s16091466

[4] M. Bor, U. Roedig, T. Voigt, and J. Alonso, "Do LoRa Low-Power Wide-Area Networks Scale?" in *Proc. 19th ACM Int. Conf. Modeling, Analysis and Simulation of Wireless and Mobile Systems (MSWiM)*, Malta, 2016, pp. 59–67. doi:10.1145/2988287.2989163

[5] I. F. Akyildiz, W. Su, Y. Sankarasubramaniam, and E. Cayirci, "Wireless sensor networks: a survey," *Computer Networks*, vol. 38, no. 4, pp. 393–422, Mar. 2002. doi:10.1016/S1389-1286(01)00302-4

[6] M. R. Palattella et al., "Standardized Protocol Stack for the Internet of (Important) Things," *IEEE Communications Surveys & Tutorials*, vol. 15, no. 3, pp. 1389–1406, 2013. doi:10.1109/SURV.2012.111412.00158

[7] Semtech Corporation, "AN1200.22 LoRa Modulation Basics," Application Note, Semtech, Rev. 2, May 2015. [Online]. Available: https://www.semtech.com/uploads/documents/an1200.22.pdf

[8] LoRa Alliance, "LoRaWAN Specification v1.0.4," Technical Specification, LoRa Alliance, Oct. 2020. [Online]. Available: https://lora-alliance.org/resource_hub/lorawan-specification-v1-0-4/

[9] O. Georgiou and U. Raza, "Low Power Wide Area Network Analysis: Can LoRa Scale?" *IEEE Wireless Communications Letters*, vol. 6, no. 2, pp. 162–165, Apr. 2017. doi:10.1109/LWC.2016.2647247

[10] W. R. Heinzelman, A. Chandrakasan, and H. Balakrishnan, "Energy-efficient communication protocol for wireless microsensor networks," in *Proc. 33rd Hawaii Int. Conf. System Sciences (HICSS)*, 2000. doi:10.1109/HICSS.2000.926982

[11] I. Demirkol, C. Ersoy, and F. Alagoz, "MAC protocols for wireless sensor networks: a survey," *IEEE Communications Magazine*, vol. 44, no. 4, pp. 115–121, Apr. 2006. doi:10.1109/MCOM.2006.1632658

[12] IEEE Standards Association, *IEEE Std 802.15.4e-2012: IEEE Standard for Local and Metropolitan Area Networks -- Part 15.4: Low-Rate Wireless Personal Area Networks (LR-WPANs) Amendment 1: MAC Sublayer*. IEEE, 2012. doi:10.1109/IEEESTD.2012.6185525

[13] A. H. Taner, O. Usta, A. Musa, and M. Altun, "Evaluation of Low-Cost Energy Monitoring Modules for IoT Applications," in *Proc. IEEE Int. Conf. Innovations in Intelligent Systems and Applications (INISTA)*, 2019. doi:10.1109/INISTA.2019.8778303

[14] N. Al-Rousan, A. R. Alsarayreh, and B. A. Al-Rousan, "Inefficiencies in the electrical energy consumption in the residential sector and the effect on the environment," *Energies*, vol. 13, no. 14, p. 3606, Jul. 2020. doi:10.3390/en13143606

[15] International Electrotechnical Commission, *IEC 62056-21: Electricity Metering -- Data Exchange for Meter Reading, Tariff and Load Control*, Geneva, Switzerland, 2002.

[16] S. Rao, D. Chung, and P. Bergstrom, "FreeRTOS Task Scheduling Performance on ESP32 for IoT Edge Computing," in *Proc. IEEE Int. Conf. Consumer Electronics -- Asia (ICCE-Asia)*, 2022. doi:10.1109/ICCE-Asia57006.2022.9954641

[17] Espressif Systems, *ESP32 Technical Reference Manual*, v5.1, Espressif Systems, Shanghai, China, 2023. [Online]. Available: https://www.espressif.com/sites/default/files/documentation/esp32_technical_reference_manual_en.pdf

[18] A. A. Wahab, A. Y. M. Shakaff, A. H. Adom, and M. N. Ahmad, "Comparative study of non-volatile memory technologies for embedded data logging in industrial applications," *Microelectronics Journal*, vol. 44, no. 11, pp. 1076–1083, 2013. doi:10.1016/j.mejo.2013.07.013

[19] B. Kernighan and R. Pike, *The Practice of Programming*. Addison-Wesley, 1999, ch. 2.

[20] Semtech Corporation, *SX1276/77/78/79 Datasheet: 137 MHz to 1020 MHz Low Power Long Range Transceiver*, Rev. 7, Semtech, 2020.

[21] European Telecommunications Standards Institute, *ETSI EN 300 220-1 V3.1.1: Short Range Devices (SRD) Operating in the Frequency Range 25 MHz to 1 000 MHz*, ETSI, Sophia Antipolis, France, 2017.

[22] S. Sesia, I. Toufik, and M. Baker, *LTE -- The UMTS Long Term Evolution: From Theory to Practice*, 2nd ed. Wiley, 2011, ch. 4.

[23] C. Buratti, A. Conti, D. Dardari, and R. Verdone, "An overview on wireless sensor networks technology and evolution," *Sensors*, vol. 9, no. 9, pp. 6869–6896, Sep. 2009. doi:10.3390/s90906869

[24] I. Fette and A. Melnikov, "The WebSocket Protocol," IETF RFC 6455, Dec. 2011. doi:10.17487/RFC6455

[25] Wi-Fi Alliance, *Captive Portal Technical Specification v1.1*, Wi-Fi Alliance, 2021.

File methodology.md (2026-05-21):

# Methodology: ESP32-Based LoRa TDMA Power Telemetry System

## 1. Introduction

This document describes the design methodology of a remotely-operated AC load monitoring and control system built around the ESP32 microcontroller and the SX1278 LoRa radio transceiver. The system employs a custom Time Division Multiple Access (TDMA) protocol over a frequency-hopping LoRa physical layer to collect real-time electrical measurements from up to eight sensor nodes and aggregate them at a single gateway, which exposes the data through a Wi-Fi-hosted web dashboard.

The design addresses a class of problems common in industrial and residential energy management: the need for sub-second telemetry update rates, reliable two-way command delivery, and continuous energy accumulation across power cycles — all without cellular infrastructure and within a low-cost, low-power hardware budget.

---

## 2. System Architecture

### 2.1 Role Separation from a Unified Codebase

The firmware is compiled into two mutually exclusive roles from a single codebase controlled by preprocessor flags (`NODE_GATEWAY` / `NODE_TELEMETRY`). This technique, sometimes called *conditional compilation for role differentiation*, avoids code divergence across firmware variants and ensures that shared protocol constants and packet definitions remain identical on both ends [1]. PlatformIO build environments (`gateway`, `node`) inject the appropriate flag at compile time, producing role-optimised binaries without maintaining separate repositories.

### 2.2 Star Topology with a Single Coordinator

The network follows a star topology: one gateway acts as the TDMA master and all sensor nodes communicate exclusively with the gateway. Star topologies are well-established in wireless sensor networks (WSNs) where a mains-powered, resource-rich coordinator can absorb the complexity of scheduling and aggregation [2]. The gateway hosts the only web server, FRAM persistence, and Wi-Fi stack; nodes carry only a power meter interface, relay driver, and radio.

---

## 3. Physical Layer — LoRa

### 3.1 Radio Parameters

The SX1278 transceiver implements the LoRa chirp-spread-spectrum (CSS) physical layer. The selected parameters are:

| Parameter | Value |
| :--- | :--- |
| Frequency | 433 MHz ISM band |
| Bandwidth | 125 kHz |
| Spreading Factor | SF6 |
| Coding Rate | 4/5 |
| TX Power | 10 dBm |
| Sync Word | 0x12 (private) |

SF6 at 125 kHz yields a symbol duration of 0.512 ms and represents the highest data rate available on the SX1278. The 8-byte BeaconPacket has a time-on-air of approximately 18 ms; the 32-byte TelemetryPacket approximately 34 ms. The link budget at 10 dBm output and SX1278 sensitivity of approximately −118 dBm at SF6 is around 126 dB, sufficient for intra-building ranges of 100–300 m. SF6 is chosen over higher spreading factors because minimising time-on-air per slot is the primary constraint in a tight TDMA budget; the deployment environment does not require the extended range that higher SFs provide.

Augustin et al. [3] characterised LoRa coverage and capacity under various SF/BW combinations and concluded that the lowest viable SF provides the best throughput-per-channel efficiency in dense, short-range deployments — matching the intent of this system.

### 3.2 Frequency-Hopping Channel Plan

Eight channels are defined at 200 kHz spacing across the 433 MHz ISM band (433.05–434.45 MHz). Channel 0 is the fixed *rendezvous channel* used for beacons and the contention window. Data slots hop per the function:

```
channel = (sfCount × 7 + slotId) mod 8
```

The multiplier 7 is coprime to 8, guaranteeing that over eight consecutive superframes every slot visits every channel exactly once (a complete Latin square traversal). Frequency hopping reduces the impact of narrowband interference and multipath fading [4]. Bor et al. [4] demonstrated that uncoordinated LoRa networks suffer from inter-network interference that frequency hopping effectively mitigates, even in dense ISM deployments.

---

## 4. MAC Layer — Custom TDMA Protocol

### 4.1 Superframe Structure

The protocol organises time into repeating superframes of exactly 3000 ms:

```
|<————————————————————————————— 3000 ms ——————————————————————————————>|
| Beacon | Slot 1 | Slot 2 | … | Slot 8 | CW UL | CW DL | Idle   | Guard |
|  40 ms | 165 ms | 165 ms |   | 165 ms | 60 ms | 40 ms | 1520 ms| 20 ms |
```

Each 165 ms data slot uses **DL-first ordering**:
- **DL window (50 ms):** Gateway transmits a pending command (if any); node receives.
- **UL window (100 ms):** Node transmits a 32-byte TelemetryPacket; gateway receives.
- **Guard (15 ms):** Absorbs PLL re-lock latency between frequency hops.

The DL-first ordering allows the node to receive and act on a relay command in the same slot before transmitting the uplink telemetry that confirms the new state. The wide 100 ms UL window — relative to the ~34 ms TelemetryPacket airtime — absorbs beacon-arrival latency and FreeRTOS scheduling jitter without requiring sub-millisecond accuracy from the node's RTOS.

The 1520 ms idle window following the contention phase provides a gap for gateway maintenance tasks (node eviction, deferred FRAM writes) while extending the superframe period to 3 s to reduce the duty cycle burden on the 433 MHz ISM band.

TDMA is the canonical choice for deterministic WSN MAC protocols where latency bounds and collision-free delivery are required [5]. Unlike CSMA-CA, TDMA eliminates hidden-node problems and provides bounded worst-case latency, which is O(1) in the number of nodes — an uplink delay of at most one superframe (3 s) regardless of network load. Demirkol et al. [5] survey the trade-offs of MAC protocols for WSNs and identify TDMA as superior for periodic telemetry applications with a known node count.
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

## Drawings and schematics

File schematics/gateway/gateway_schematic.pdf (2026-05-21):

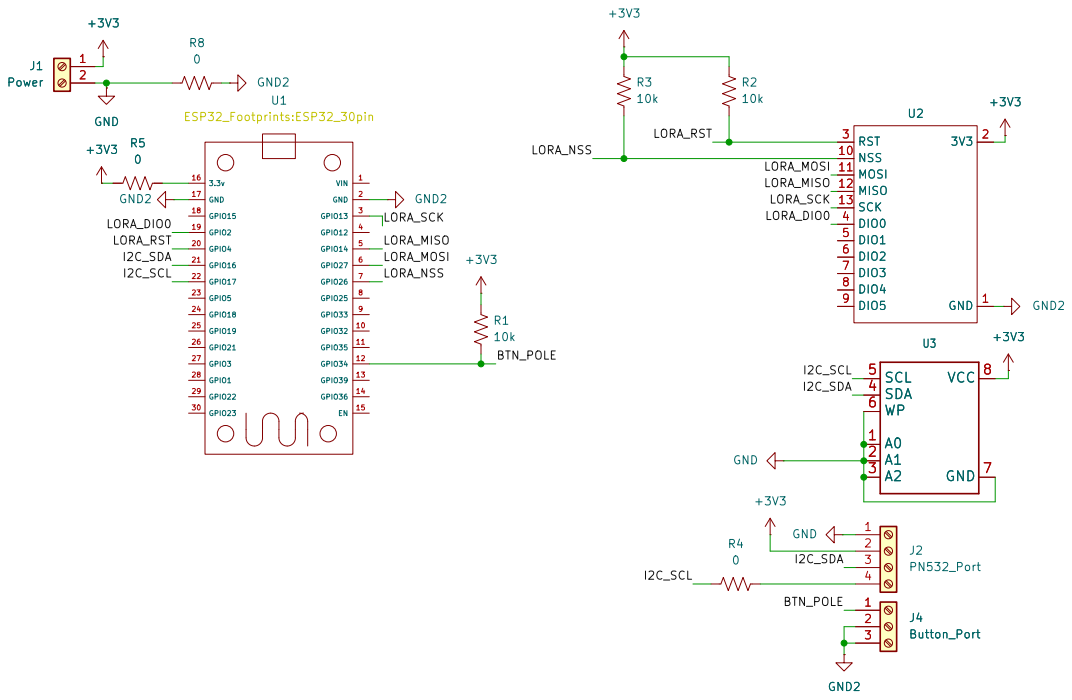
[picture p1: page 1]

Size: A4 | Rev:
KiCad E.D.A. 10.0.0 | Id: 1/1

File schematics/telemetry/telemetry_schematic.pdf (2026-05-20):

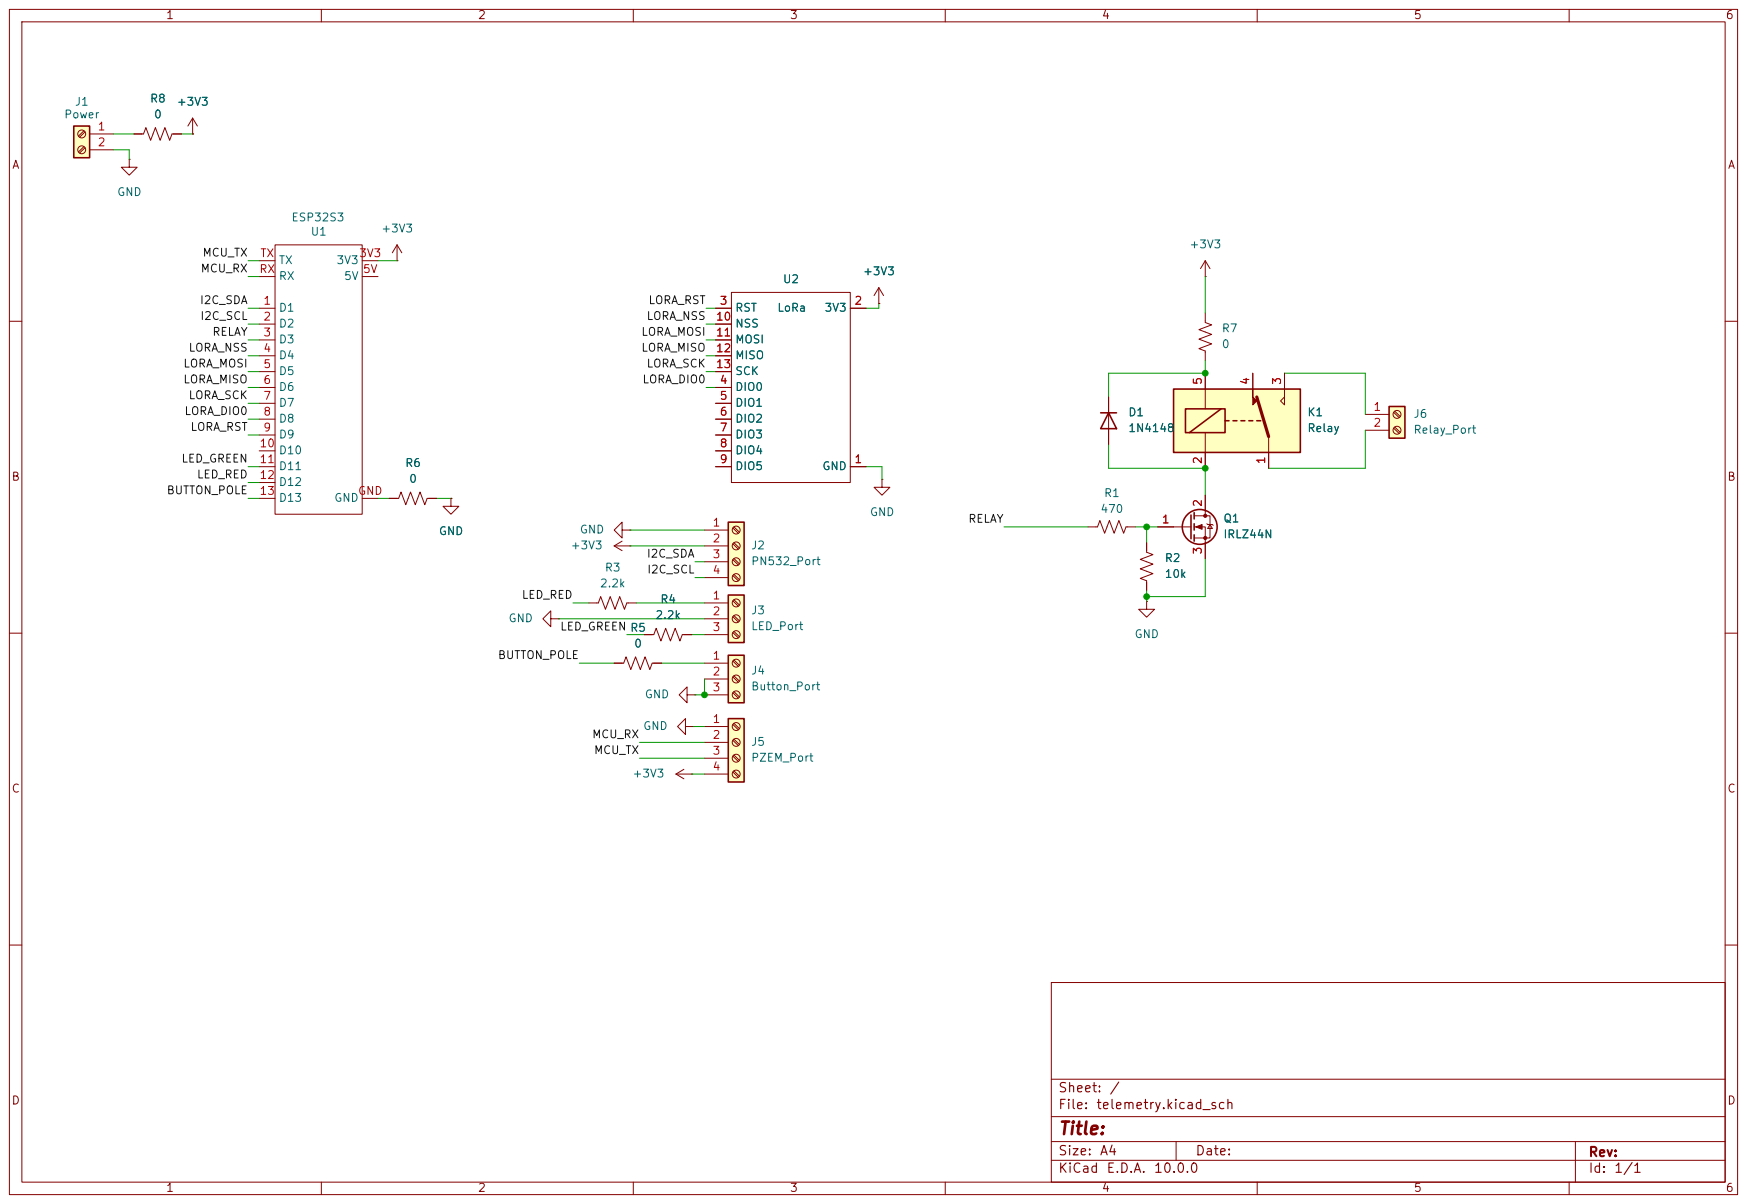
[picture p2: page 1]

Size: A4 | Rev:
KiCad E.D.A. 10.0.0 | Id: 1/1

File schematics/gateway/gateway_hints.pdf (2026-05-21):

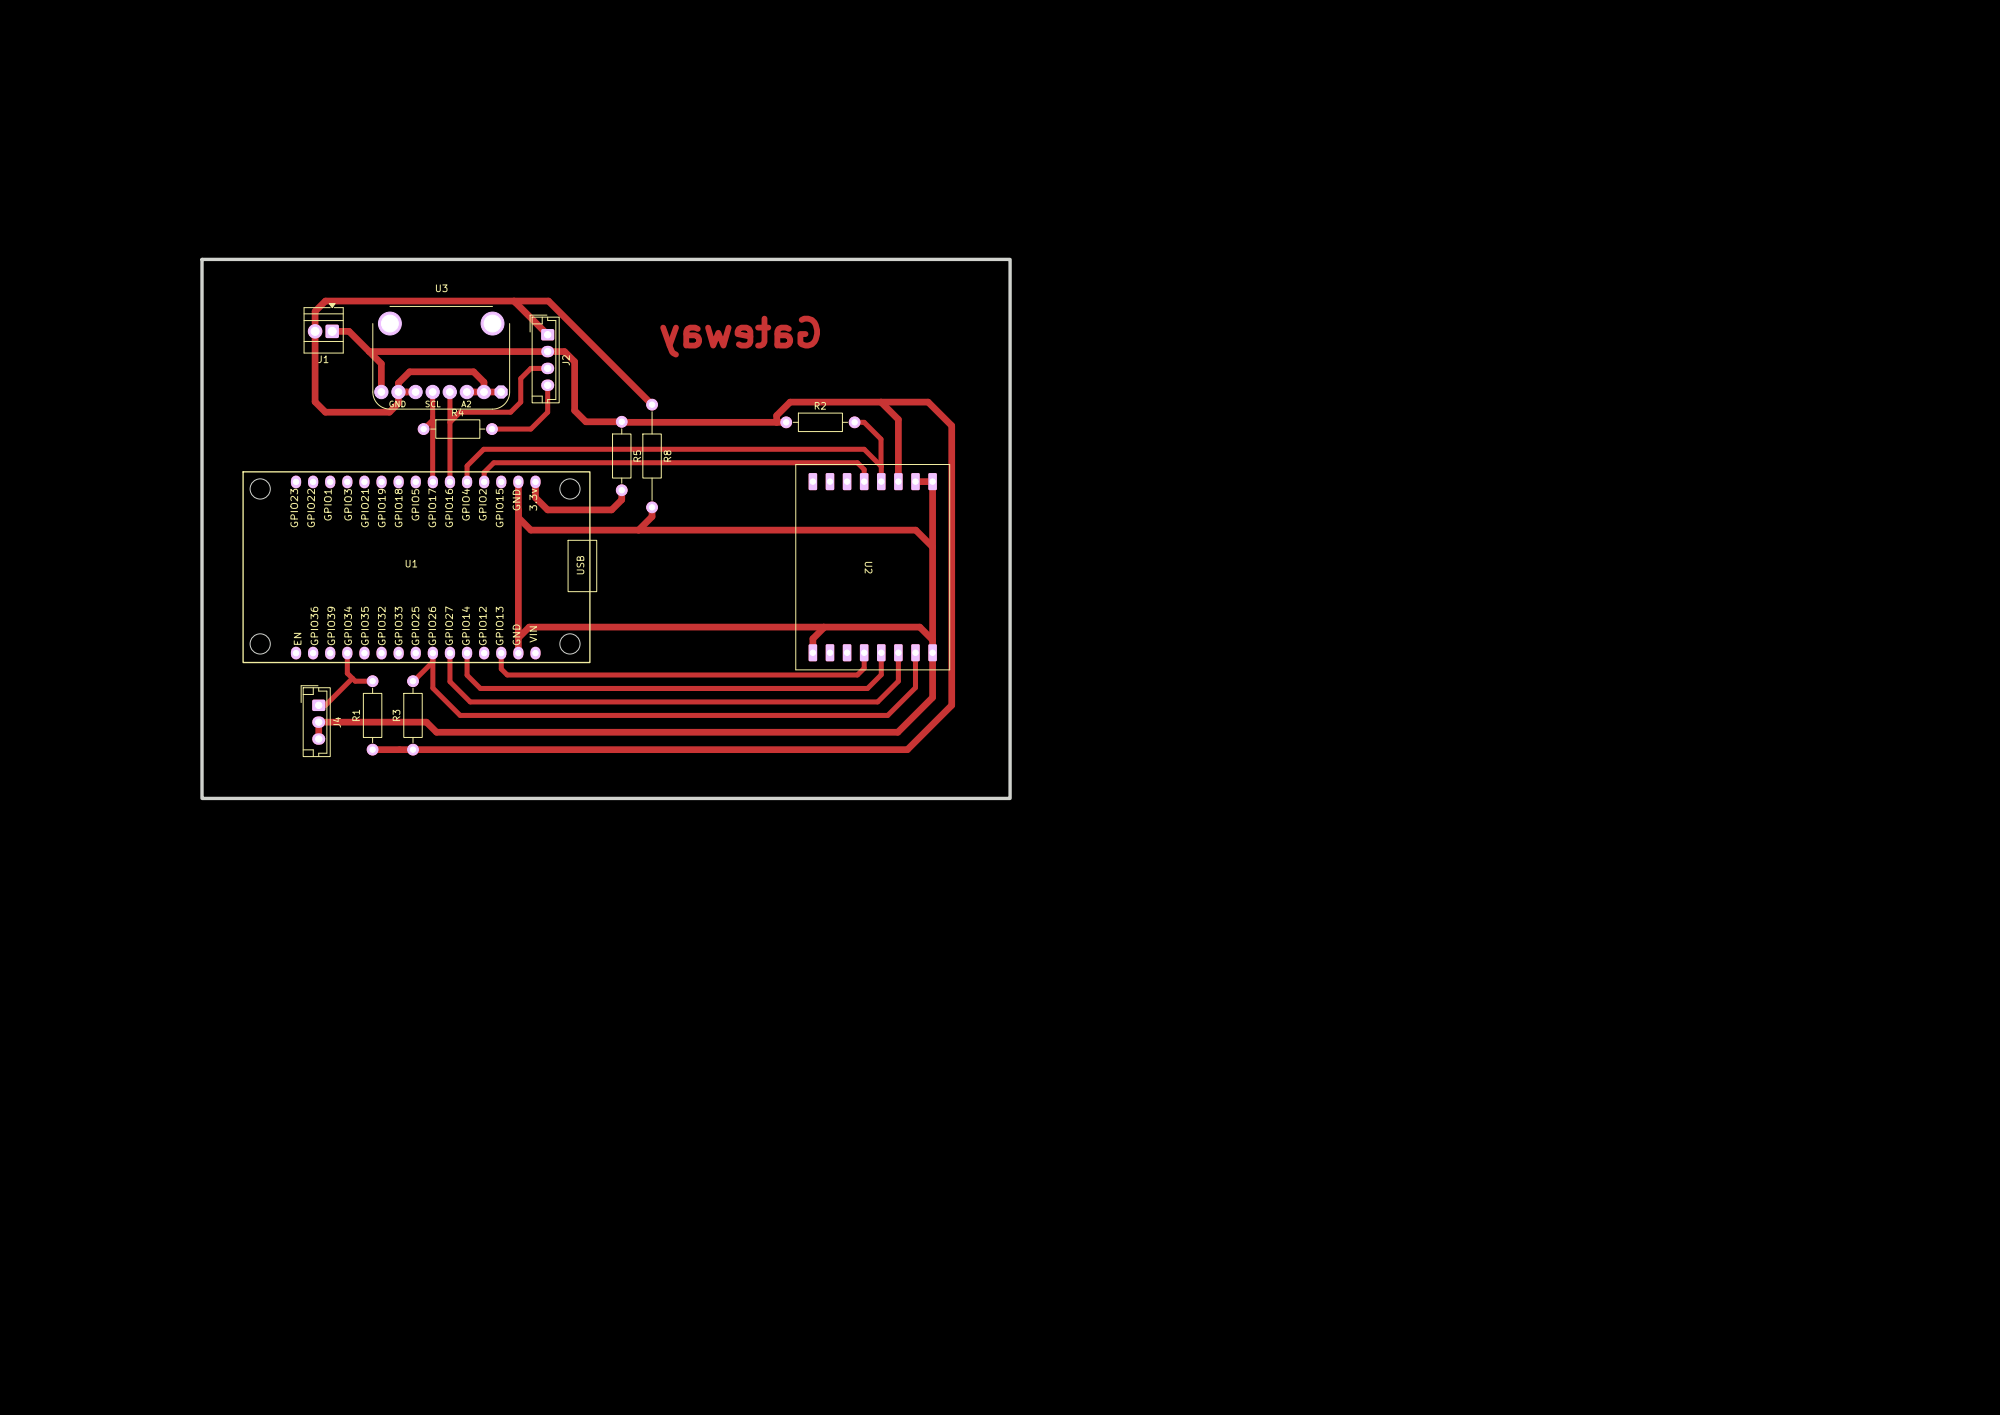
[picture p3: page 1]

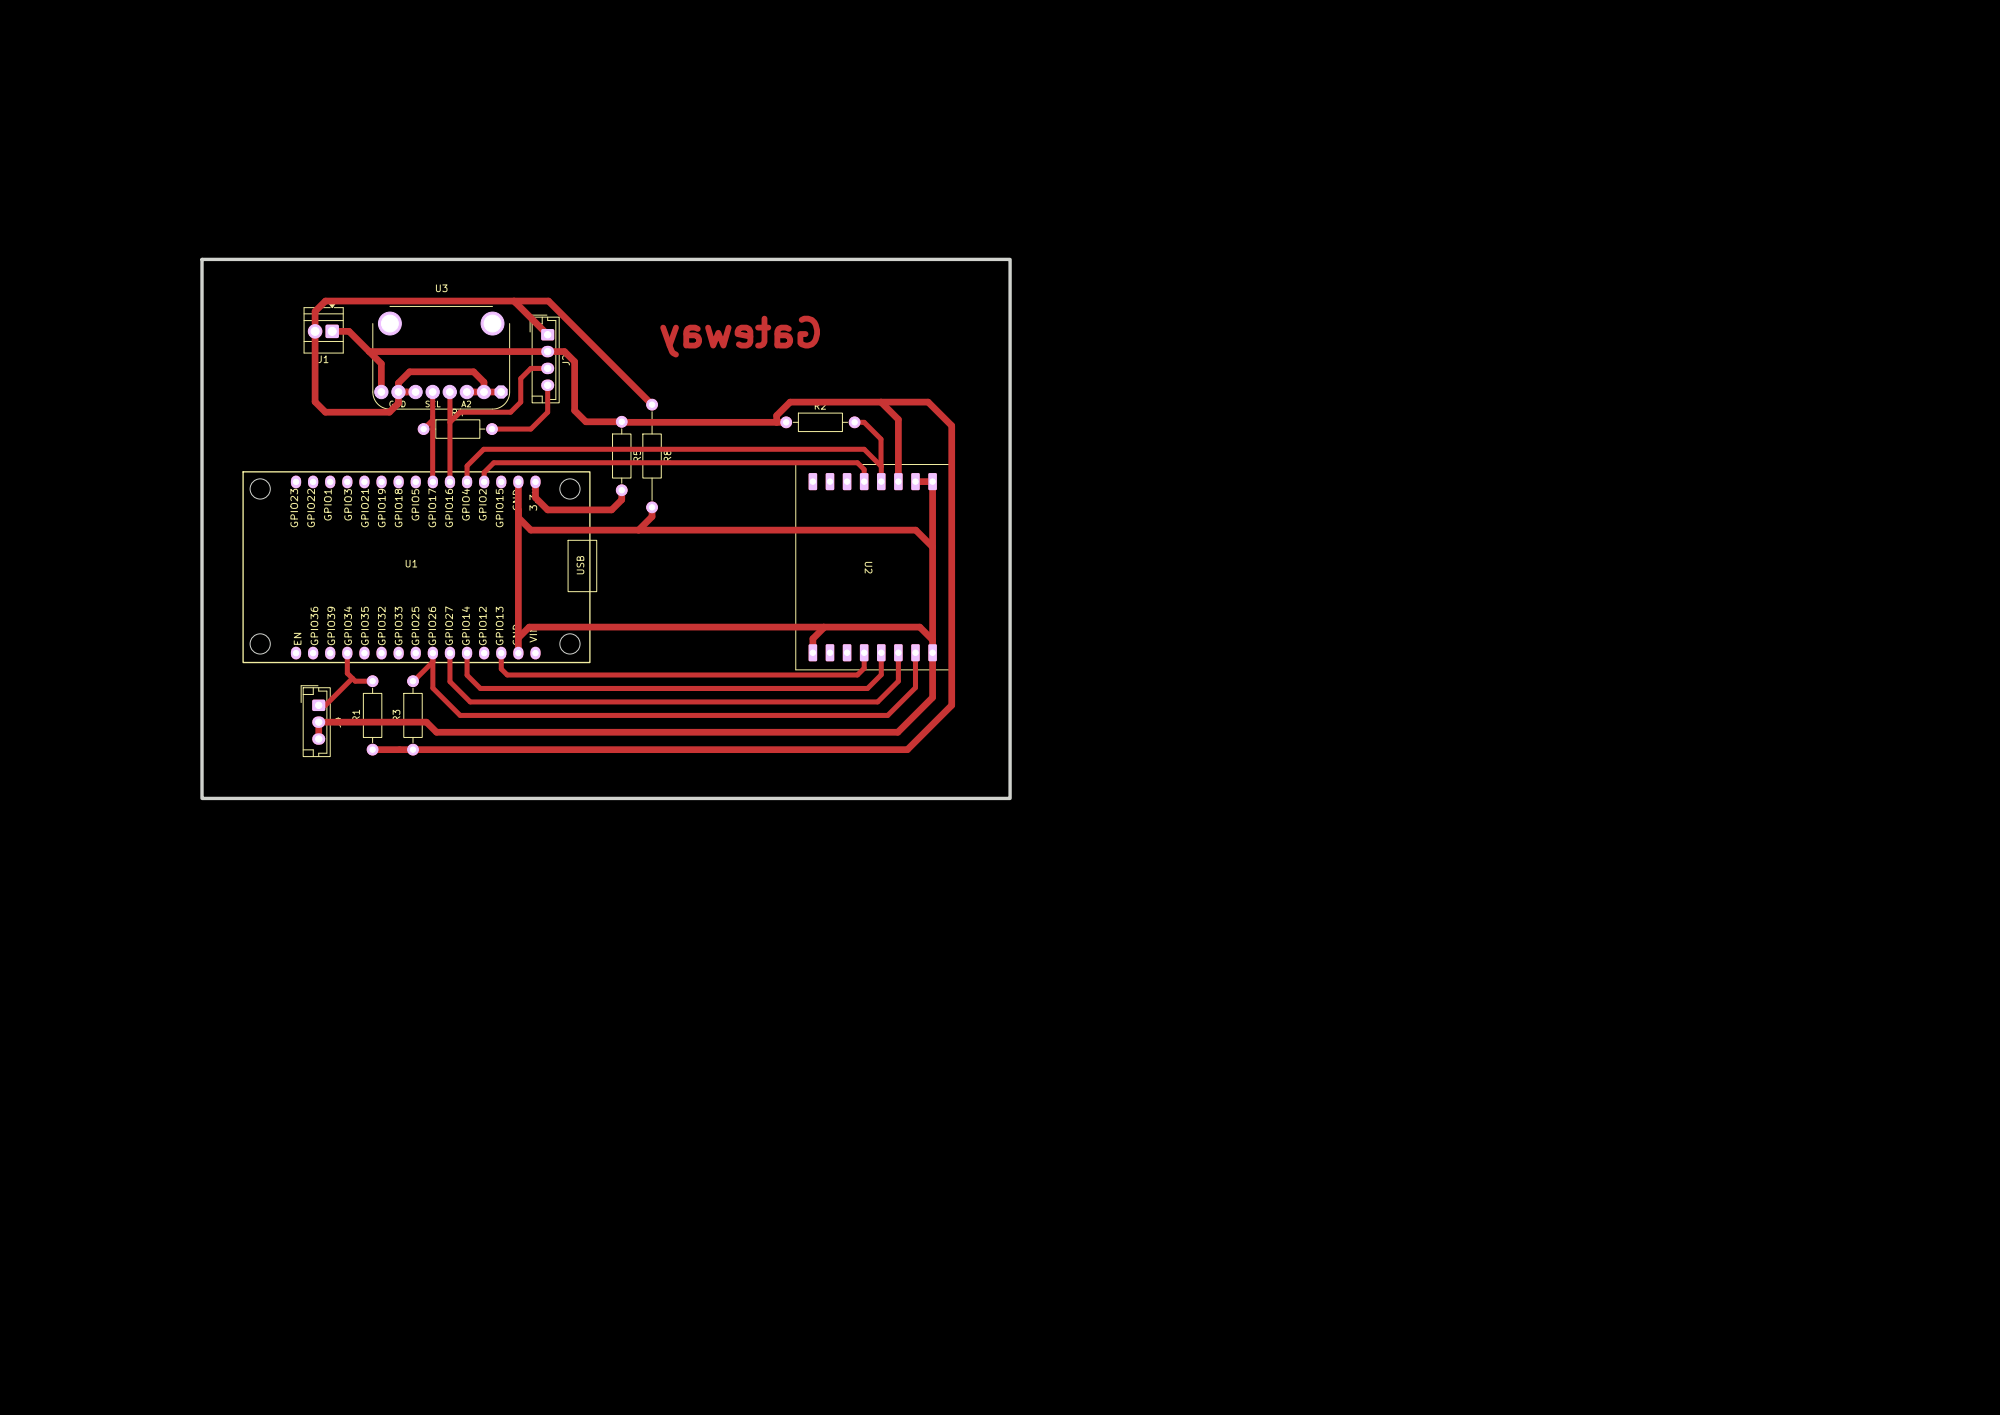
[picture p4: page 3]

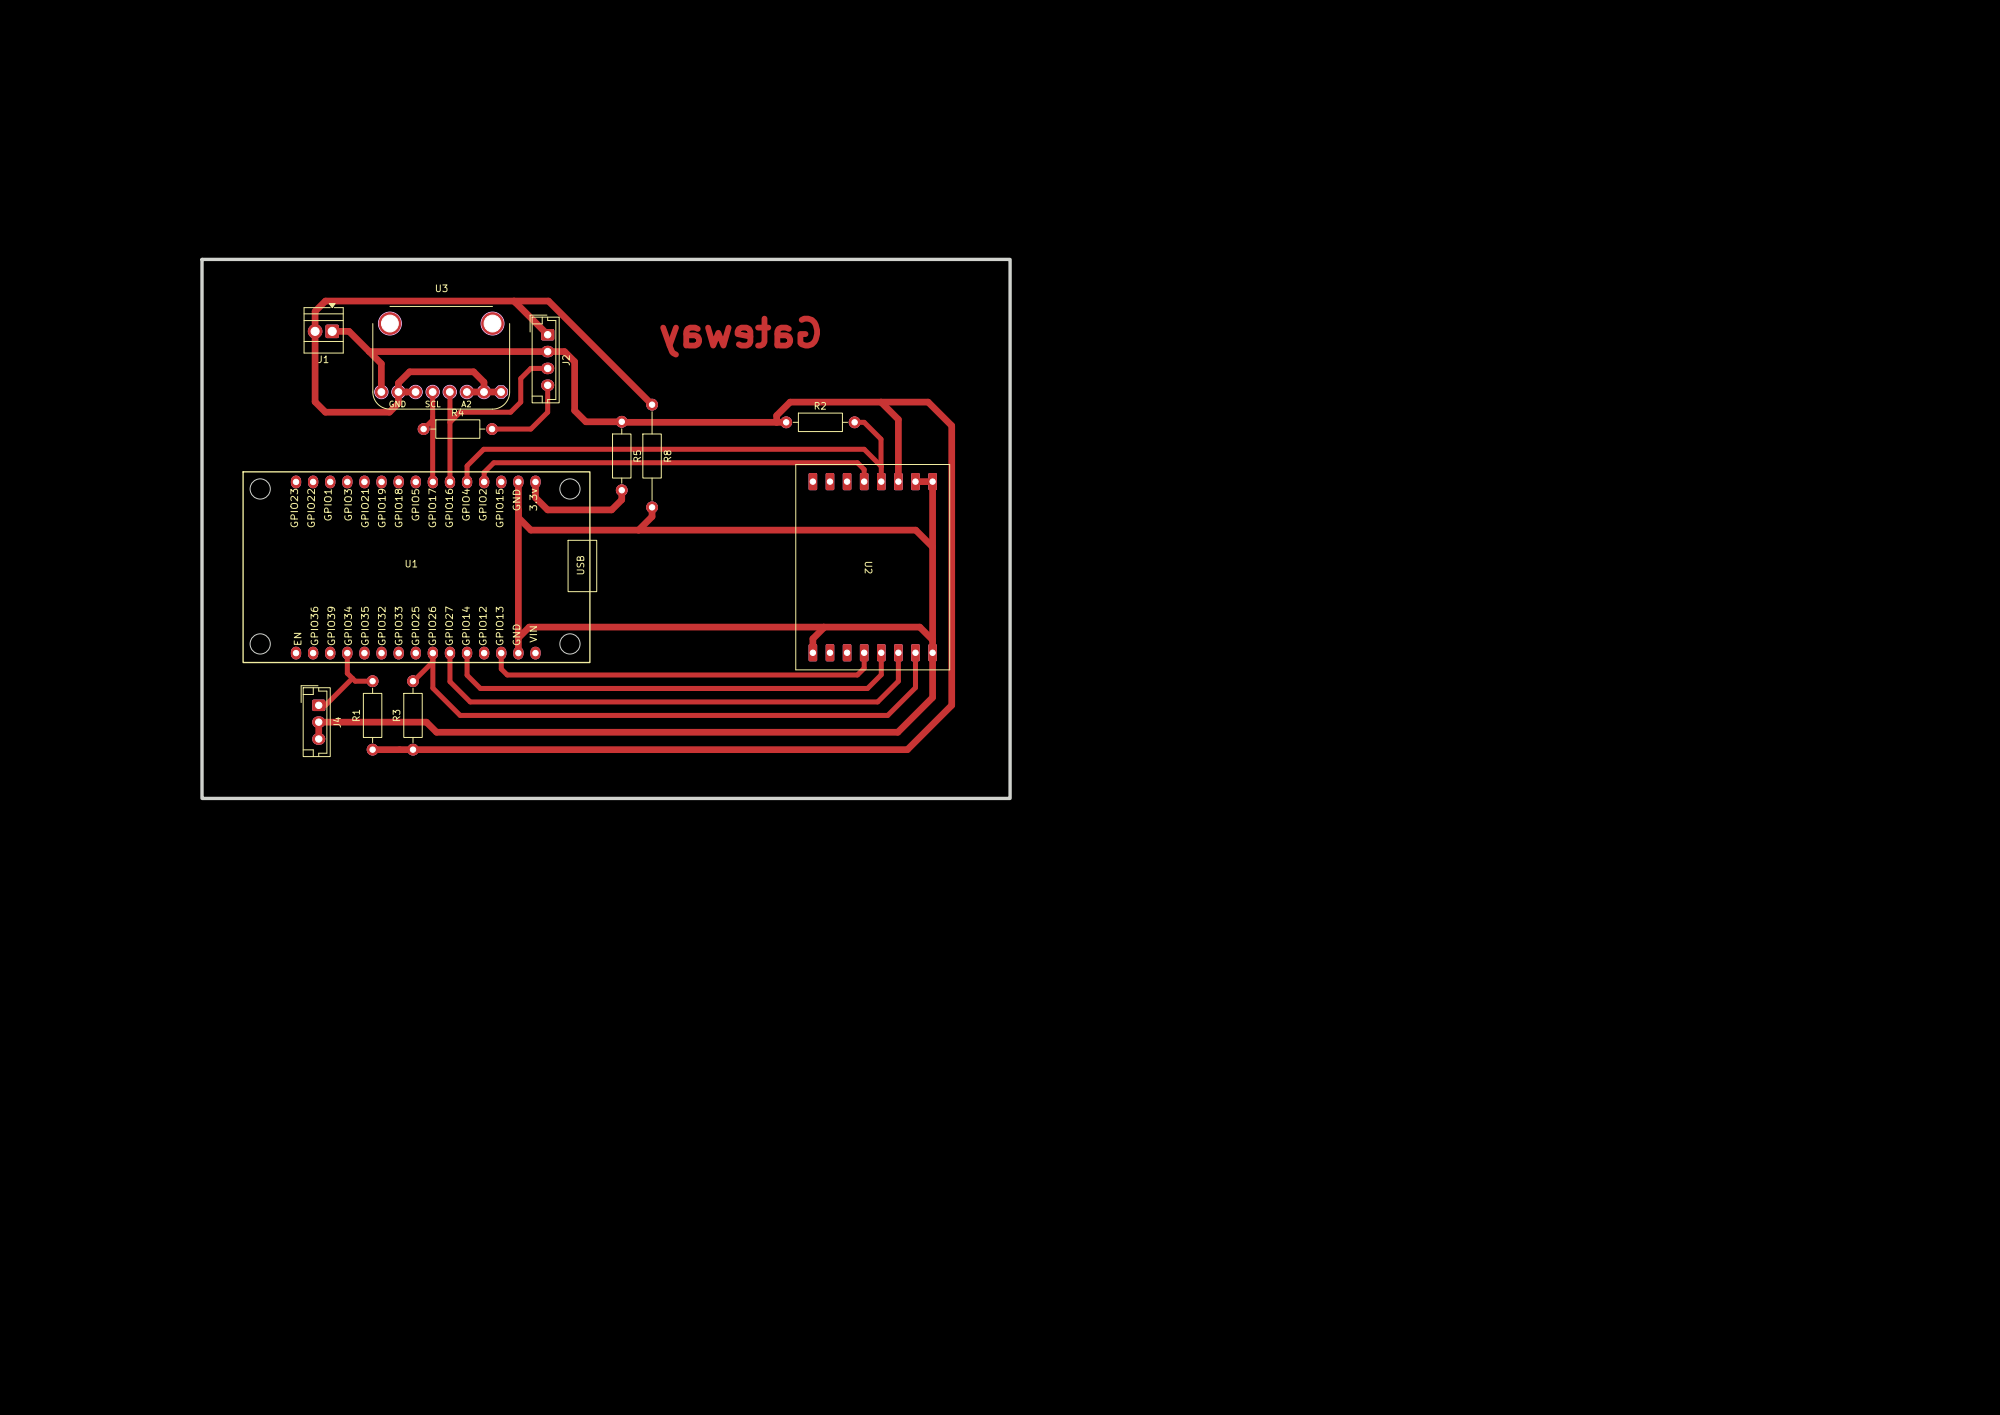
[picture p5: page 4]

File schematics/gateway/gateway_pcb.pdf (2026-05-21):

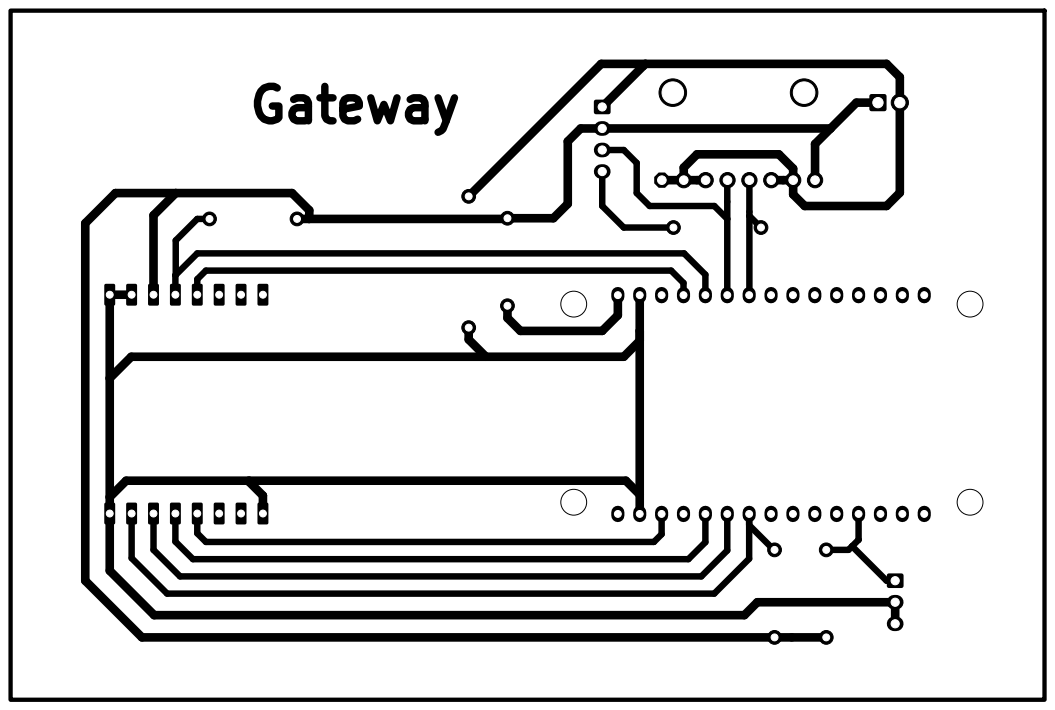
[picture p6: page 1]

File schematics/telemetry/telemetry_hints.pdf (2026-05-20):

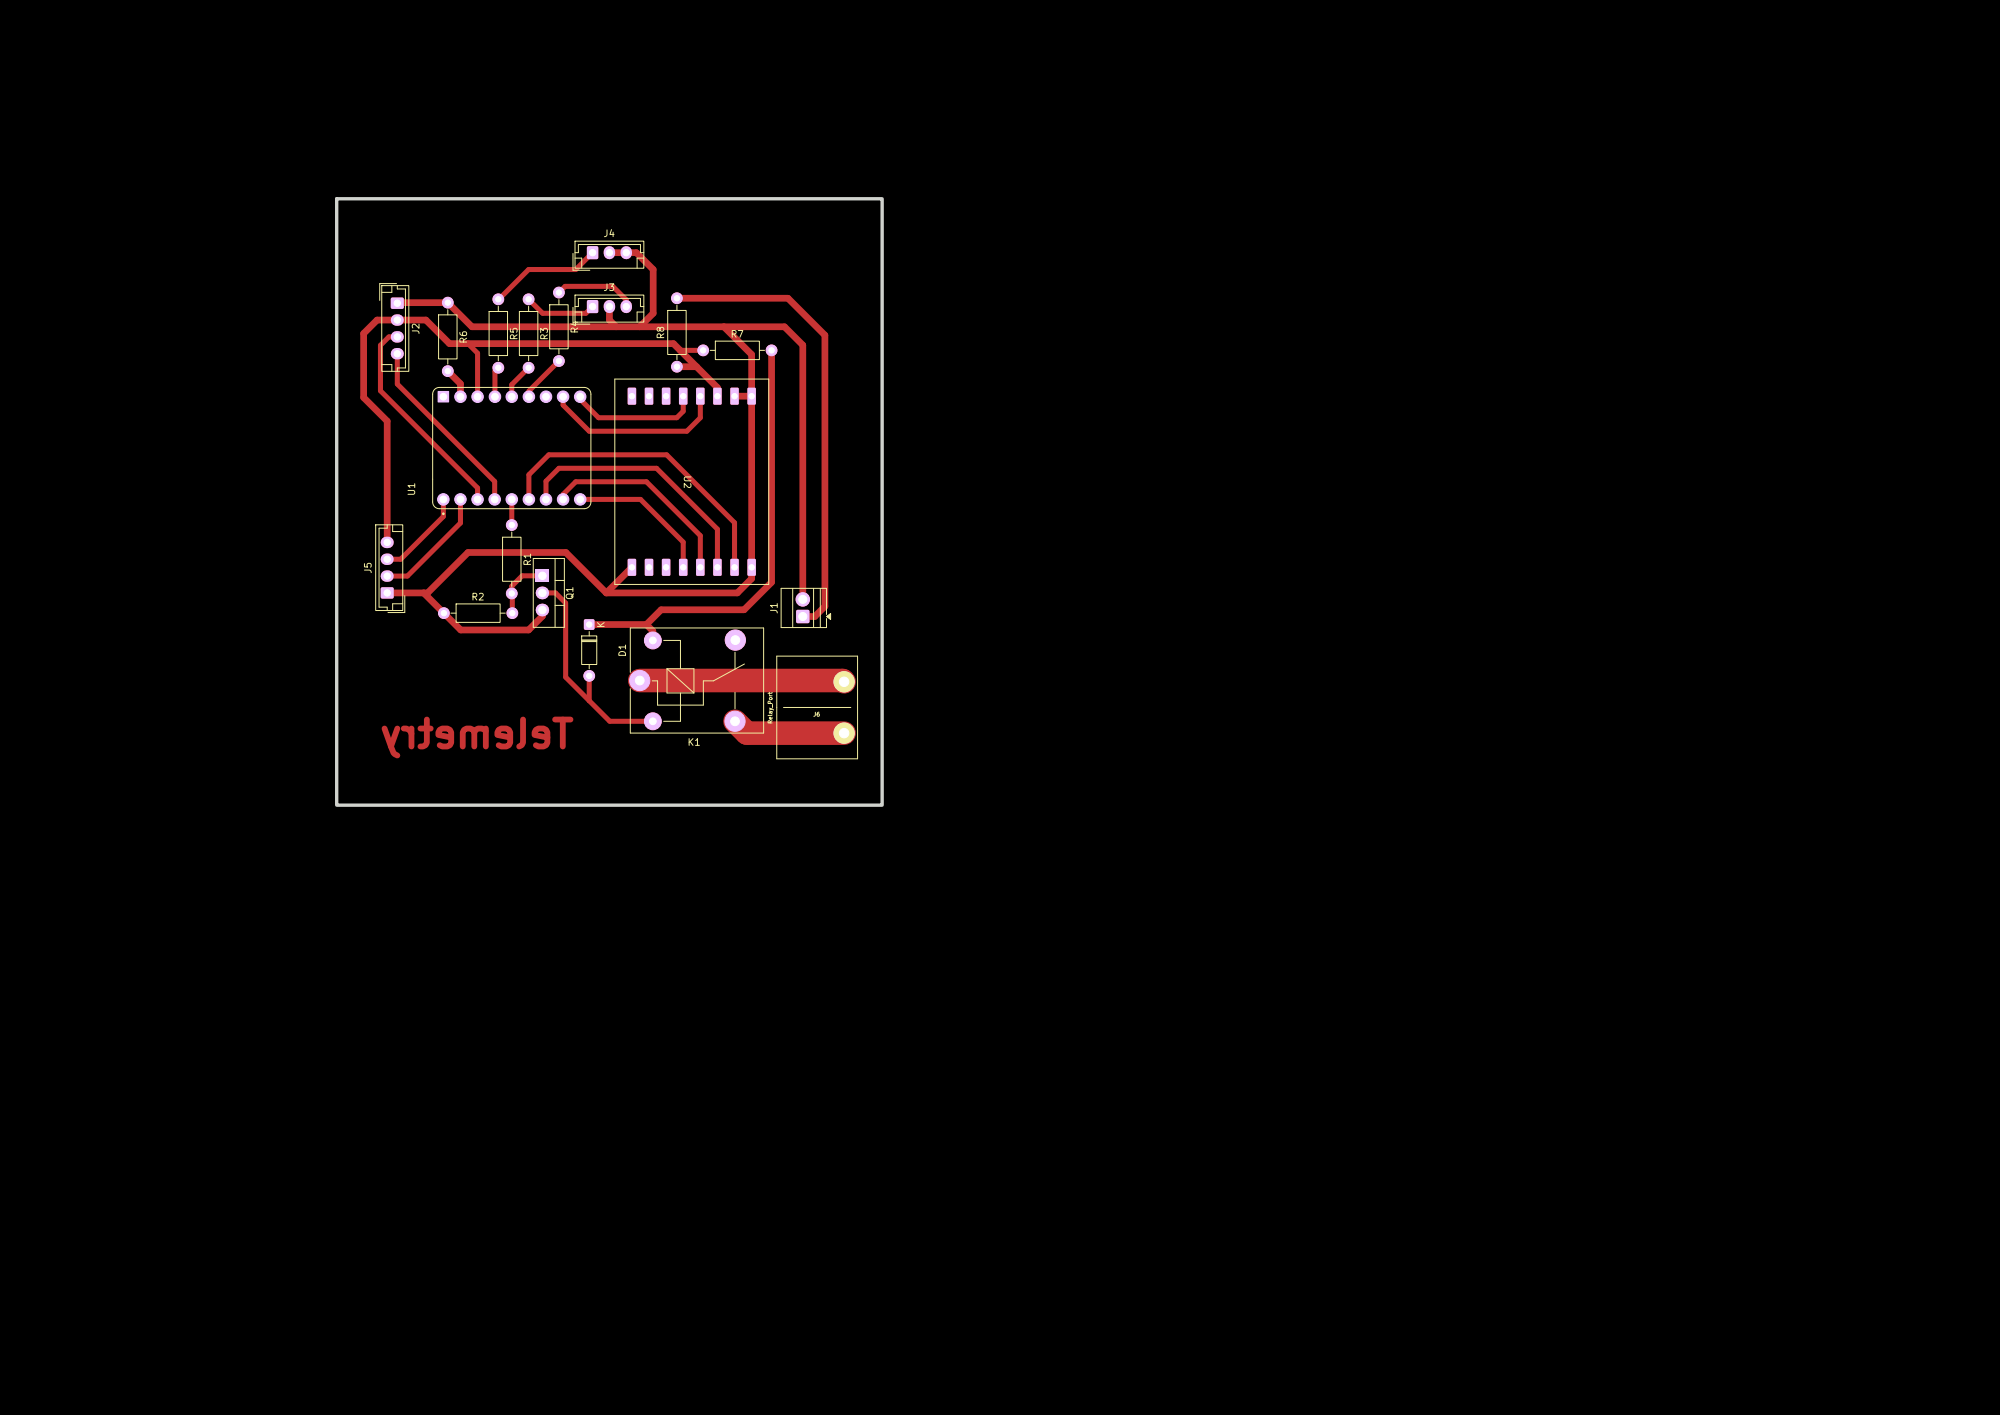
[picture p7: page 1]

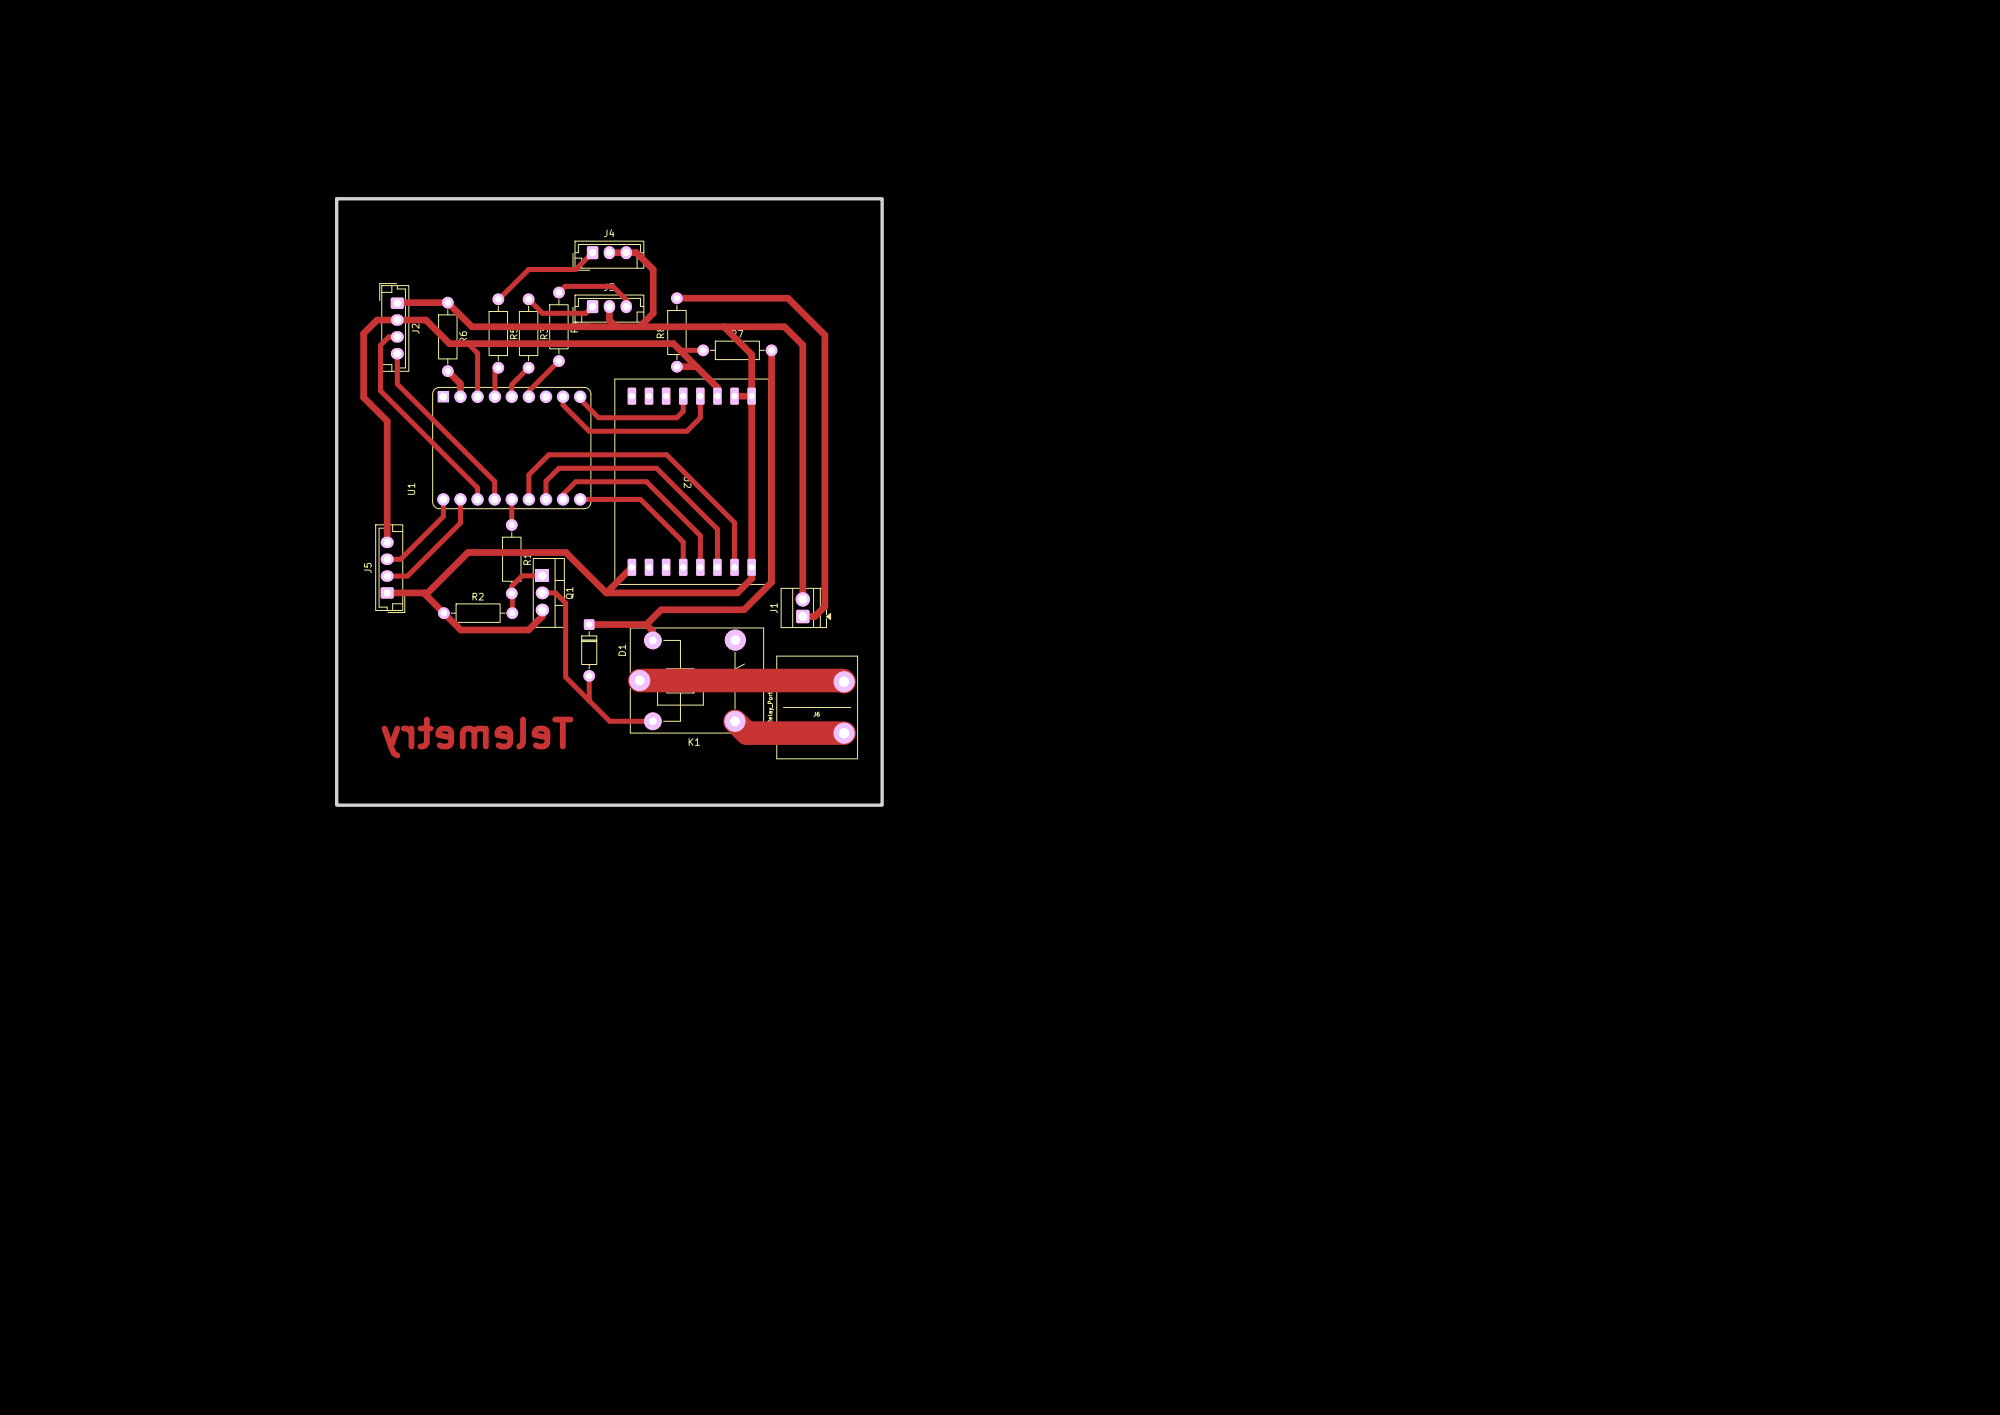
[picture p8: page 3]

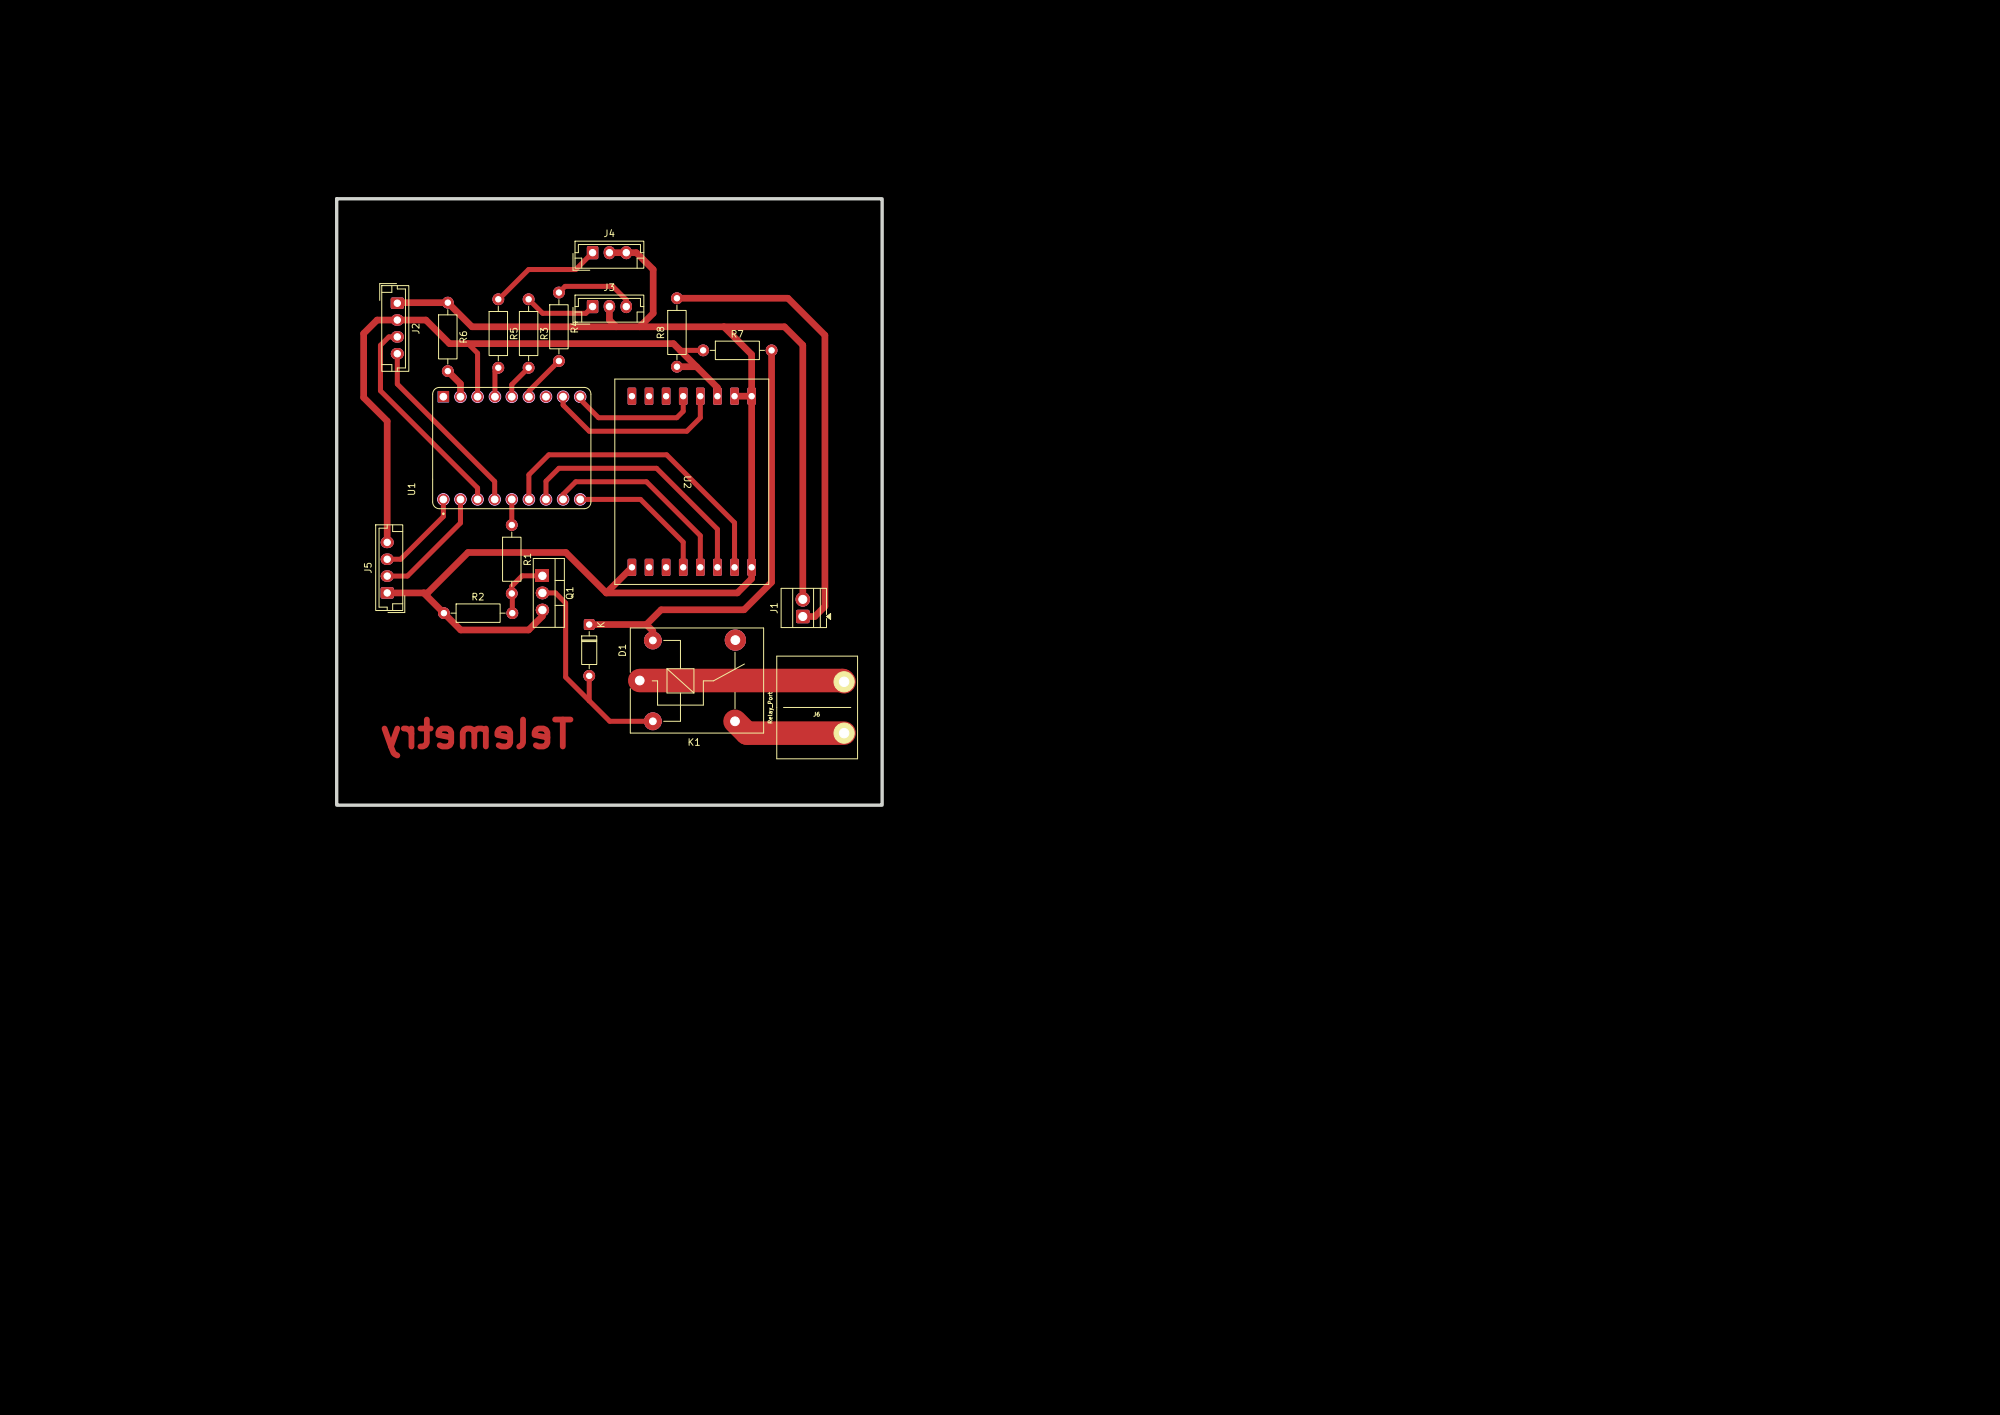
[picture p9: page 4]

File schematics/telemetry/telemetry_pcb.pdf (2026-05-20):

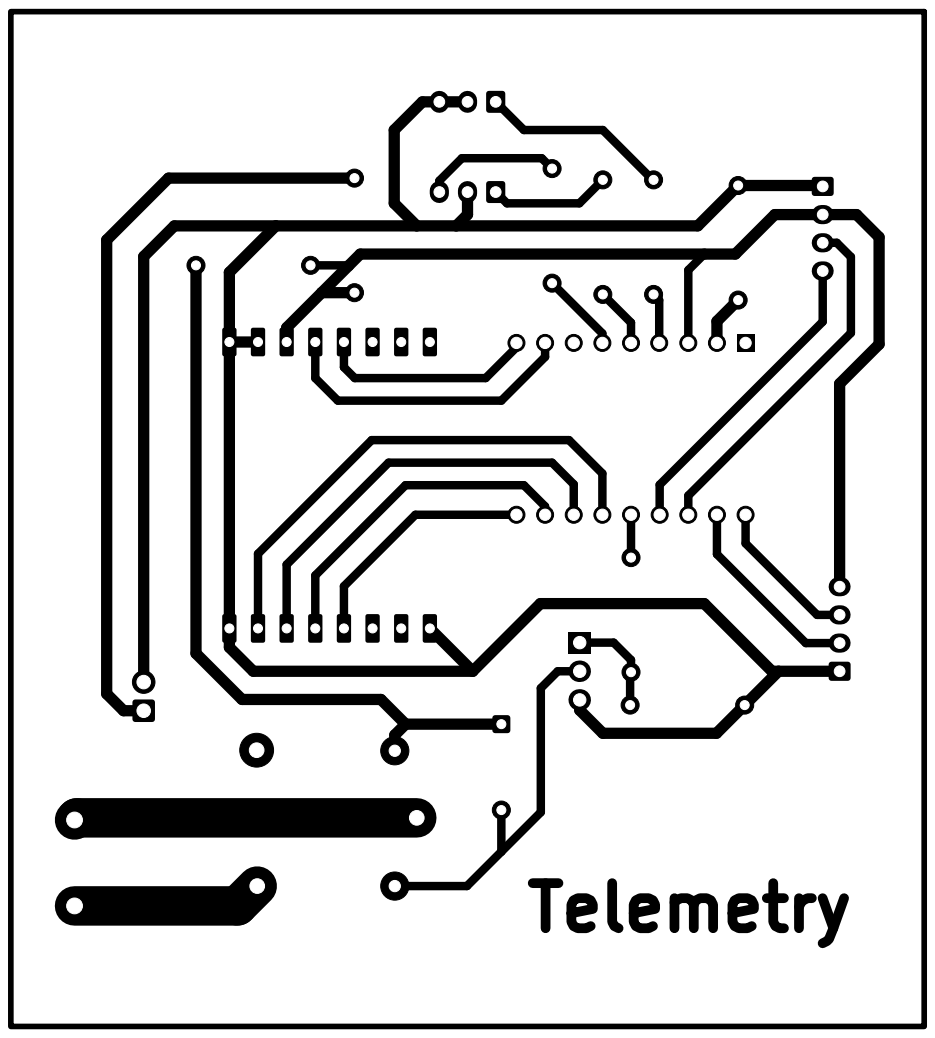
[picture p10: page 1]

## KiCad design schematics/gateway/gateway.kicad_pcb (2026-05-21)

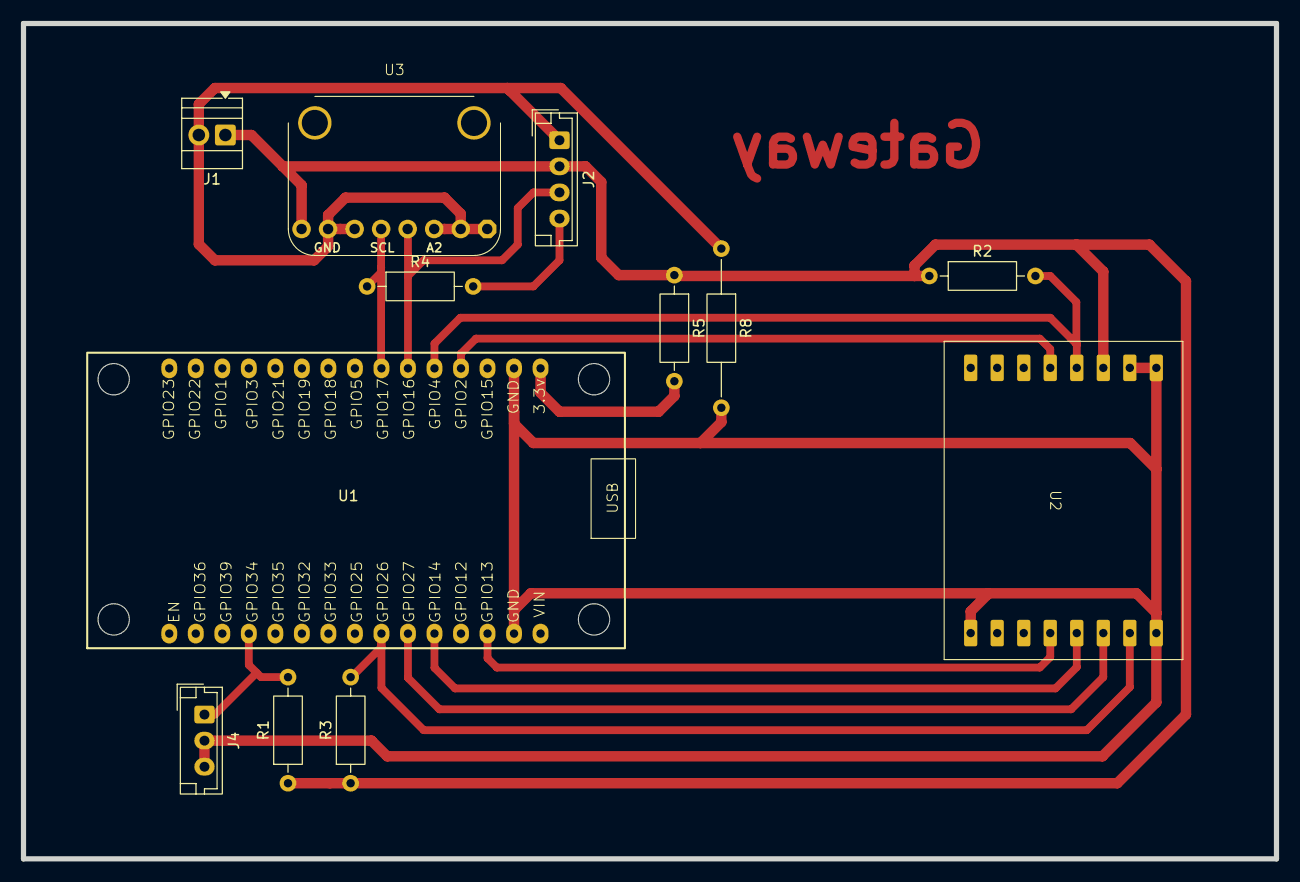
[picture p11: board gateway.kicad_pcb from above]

Board: 2 copper layers, 120.0 x 80.0 mm, 12 parts (0 on the bottom side), 14 nets.

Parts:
J1: Power; TerminalBlock_Xinya_XY308-2.54-2P_1x02_P2.54mm_Horizontal
J2: PN532_Port; JST_EH_B4B-EH-A_1x04_P2.50mm_Vertical
J4: Button_Port; JST_EH_B3B-EH-A_1x03_P2.50mm_Vertical
R1, R2, R3: 10k; R_Axial_DIN0207_L6.3mm_D2.5mm_P10.16mm_Horizontal
R4, R5: 0; R_Axial_DIN0207_L6.3mm_D2.5mm_P10.16mm_Horizontal
R8: 0; R_Axial_DIN0207_L6.3mm_D2.5mm_P15.24mm_Horizontal
U1: ESP32_30pin
U2: LoRa-02
U3: frami2c

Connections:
+3V3: J1.1, J2.2, R1.1, R2.1, R3.1, R5.1, U2.2 (3V3), U3.8 (VCC)
/BTN_POLE: J4.1, R1.2, U1.12 (GPIO34)
/I2C_SCL: R4.1, U1.22 (GPIO17), U3.5 (SCL)
/I2C_SDA: J2.3, U1.21 (GPIO16), U3.4 (SDA)
/LORA_DIO0: U1.19 (GPIO2), U2.4 (DIO0)
/LORA_MISO: U1.5 (GPIO14), U2.12 (MISO)
/LORA_MOSI: U1.6 (GPIO27), U2.11 (MOSI)
/LORA_NSS: R3.2, U1.7 (GPIO26), U2.10 (NSS)
/LORA_RST: R2.2, U1.20 (GPIO4), U2.3 (RST)
/LORA_SCK: U1.3 (GPIO13), U2.13 (SCK)
GND: J1.2, J2.1, R8.1, U3.1 (A0), U3.2 (A1), U3.3 (A2), U3.6 (WP), U3.7 (GND)
GND2: J4.2, J4.3, R8.2, U1.2 (GND), U1.17 (GND), U2.1 (GND)
unnamed: J2.4, R4.2
unnamed: R5.2, U1.16 (3.3v)

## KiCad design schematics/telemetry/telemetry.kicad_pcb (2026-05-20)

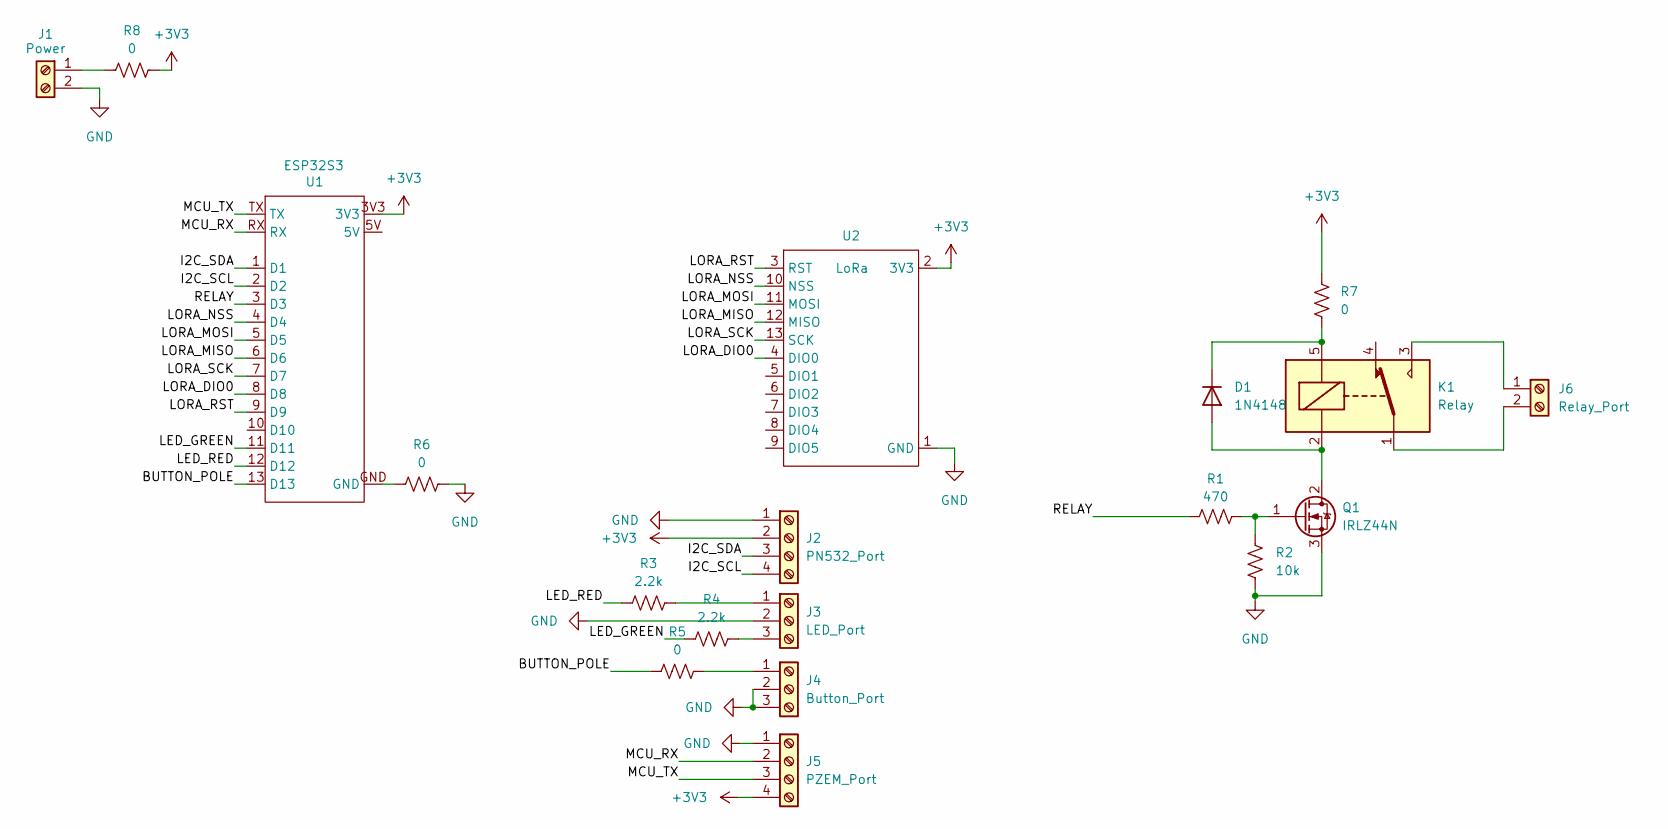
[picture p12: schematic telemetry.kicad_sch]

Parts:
D1: 1N4148; D_DO-35_SOD27_P7.62mm_Horizontal
J1: Power; TerminalBlock_Xinya_XY308-2.54-2P_1x02_P2.54mm_Horizontal
J2: PN532_Port; JST_EH_B4B-EH-A_1x04_P2.50mm_Vertical
J3: LED_Port; JST_EH_B3B-EH-A_1x03_P2.50mm_Vertical
J4: Button_Port; JST_EH_B3B-EH-A_1x03_P2.50mm_Vertical
J5: PZEM_Port; JST_EH_B4B-EH-A_1x04_P2.50mm_Vertical
J6: Relay_Port; KF7.62_2P
K1: Relay; Relay_SPDT_SANYOU_SRD_Series_Form_C
Q1: IRLZ44N; TO-220-3_Vertical
R1: 470; R_Axial_DIN0207_L6.3mm_D2.5mm_P10.16mm_Horizontal
R2: 10k; R_Axial_DIN0207_L6.3mm_D2.5mm_P10.16mm_Horizontal
R3, R4: 2.2k; R_Axial_DIN0207_L6.3mm_D2.5mm_P10.16mm_Horizontal
R5, R6, R7, R8: 0; R_Axial_DIN0207_L6.3mm_D2.5mm_P10.16mm_Horizontal
U1: ESP32S3; ESP32-S3-SuperMini
U2: LoRa; LoRa-02

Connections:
+3V3: J2.2, J5.4, R7.1, R8.1, U1.3V3, U2.2 (3V3)
/BUTTON_POLE: R5.2, U1.13 (D13)
/I2C_SCL: J2.4, U1.2 (D2)
/I2C_SDA: J2.3, U1.1 (D1)
/LED_GREEN: R4.2, U1.11 (D11)
/LED_RED: R3.2, U1.12 (D12)
/LORA_DIO0: U1.8 (D8), U2.4 (DIO0)
/LORA_MISO: U1.6 (D6), U2.12 (MISO)
/LORA_MOSI: U1.5 (D5), U2.11 (MOSI)
/LORA_NSS: U1.4 (D4), U2.10 (NSS)
/LORA_RST: U1.9 (D9), U2.3 (RST)
/LORA_SCK: U1.7 (D7), U2.13 (SCK)
/MCU_RX: J5.2, U1.RX
/MCU_TX: J5.3, U1.TX
/RELAY: R1.1, U1.3 (D3)
GND: J1.2, J2.1, J3.2, J4.2, J4.3, J5.1, Q1.3 (S), R2.1, R6.1, U2.1 (GND)
unnamed: D1.2 (A), K1.2, Q1.2 (D)
unnamed: D1.1 (K), K1.5, R7.2
unnamed: J1.1, R8.2
unnamed: J3.1, R3.1
unnamed: J3.3, R4.1
unnamed: J4.1, R5.1
unnamed: J6.1, K1.3
unnamed: J6.2, K1.1
unnamed: Q1.1 (G), R1.2, R2.2
unnamed: R6.2, U1.GND

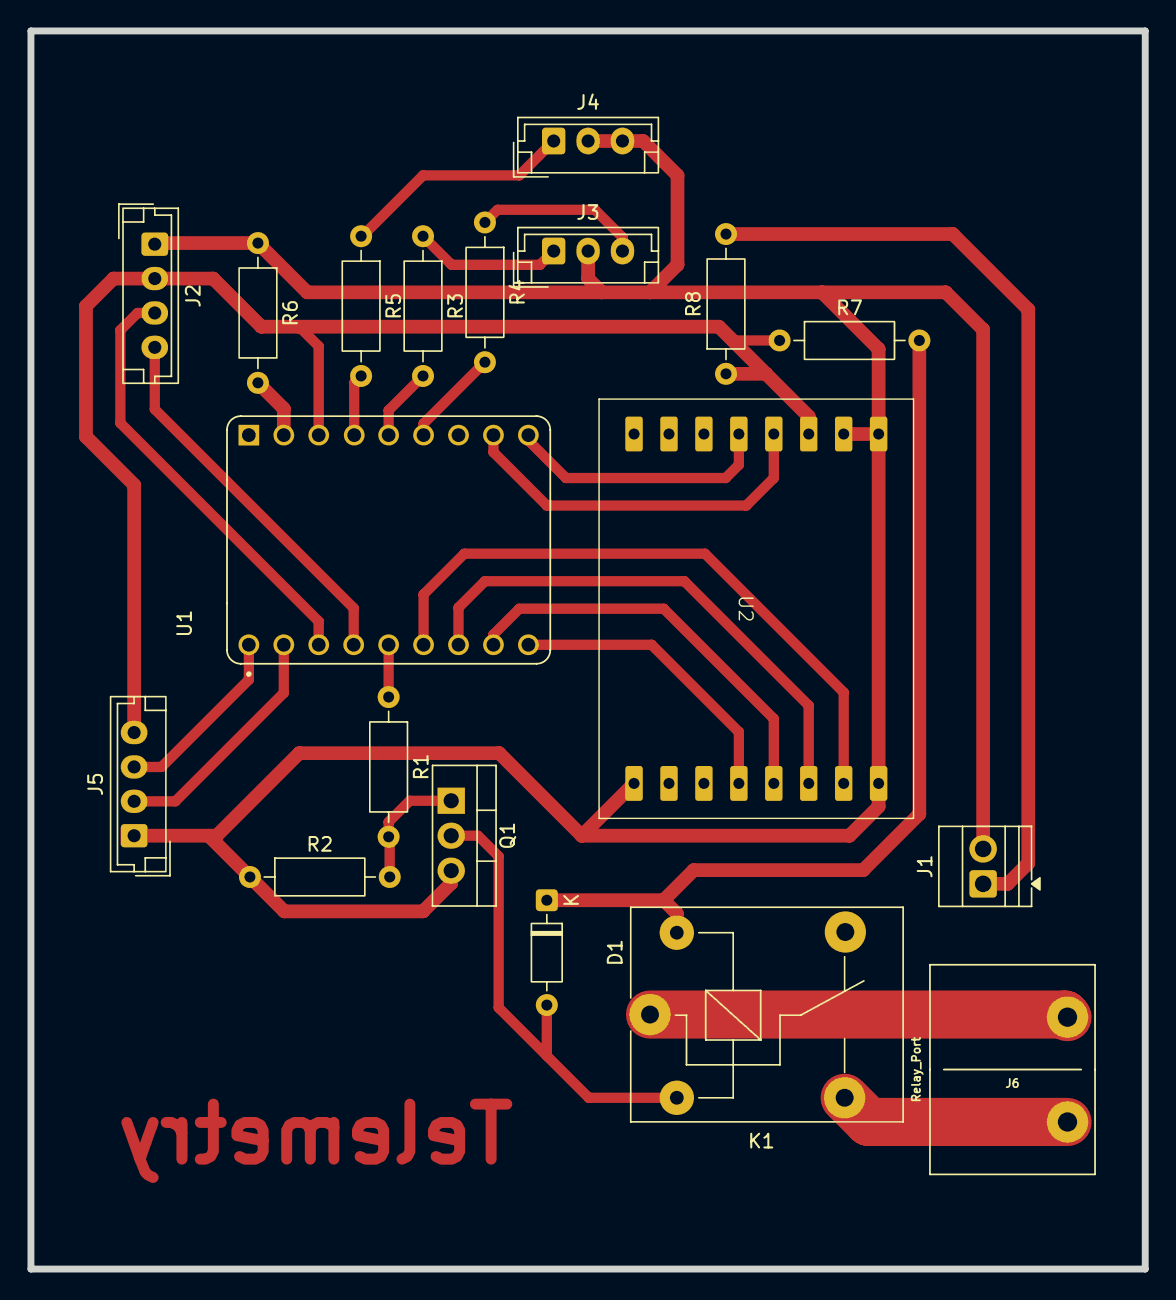
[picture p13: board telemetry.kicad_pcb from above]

Board: 2 copper layers, 81.0 x 90.0 mm, 19 parts (0 on the bottom side), 26 nets.

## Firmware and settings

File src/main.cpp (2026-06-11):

/**
 * main.cpp
 *
 * Unified entry point for the Power Telemetry firmware.
 * Compiles as either a Gateway or a Sensor Node depending on the
 * build flag defined in platformio.ini.
 *
 * -- Usage ---------------------------------------------------------------------
 *
 *   In platformio.ini, set exactly ONE of:
 *
 *     build_flags = -D NODE_GATEWAY
 *     build_flags = -D NODE_TELEMETRY
 *
 *   If BOTH are defined, the build resolves to NODE_GATEWAY (with a warning).
 *   If NEITHER is defined, the build fails with a descriptive #error.
 *
 * -- platformio.ini example ----------------------------------------------------
 *
 *   [env:gateway]
 *   platform  = espressif32
 *   board     = esp32dev
 *   framework = arduino
 *   build_flags =
 *       -D NODE_GATEWAY
 *       -D ARDUINO_USB_CDC_ON_BOOT=0
 *   board_build.filesystem = littlefs
 *   lib_deps =
 *       jgromes/RadioLib @ ^6.0.0
 *       me-no-dev/ESPAsyncWebServer
 *       me-no-dev/AsyncTCP
 *       bblanchon/ArduinoJson @ ^7.0.0
 *
 *   [env:node]
 *   platform  = espressif32
 *   board     = esp32dev
 *   framework = arduino
 *   build_flags =
 *       -D NODE_TELEMETRY
 *       -D ARDUINO_USB_CDC_ON_BOOT=0
 *   lib_deps =
 *       jgromes/RadioLib @ ^6.0.0
 *       olehs/PZEM004Tv30
 *
 * -- Hardware ------------------------------------------------------------------
 *
 *   SX1278 (VSPI):
 *     ESP32-dev (gateway + node):  NSS=26  MOSI=27  MISO=14  SCK=13  DIO0=2   RST=4
 *     ESP32-S3 Super Mini (node):  NSS=4   MOSI=5   MISO=6   SCK=7   DIO0=8   RST=9
 *
 *   Gateway only:
 *     WiFi + LittleFS (index.html + wifi_config.html in data/ folder)
 *     Dashboard: http://telemeter.local  or  http://192.168.4.1
 *
 *   Node only:
 *     PZEM-004T v3  -> Serial2  PZEM_TX=GPIO22 (-> PZEM RX), PZEM_RX=GPIO23 (<- PZEM TX)
 *     Relay signal  -> GPIO25 (active HIGH)
 *     LED green     -> GPIO32
 *     LED red       -> GPIO33
 */

// --- Macro resolution ---------------------------------------------------------
#if defined(NODE_GATEWAY) && defined(NODE_TELEMETRY)
  // Both defined - resolve to gateway with a compile-time warning.
  // #warning is a GCC extension supported by the ESP32 toolchain.
  #warning "Both NODE_GATEWAY and NODE_TELEMETRY are defined - building as NODE_GATEWAY."
  #undef NODE_TELEMETRY
#elif !defined(NODE_GATEWAY) && !defined(NODE_TELEMETRY)
  #error "No build role defined. Set exactly one of: -D NODE_GATEWAY  or  -D NODE_TELEMETRY"
#endif
// After resolution: exactly one of NODE_GATEWAY or NODE_TELEMETRY is defined.

// --- Common includes (both roles) --------------------------------------------
#include <Arduino.h>
#include <SPI.h>
#include <RadioLib.h>
#include "tdma_protocol.h"
#include "log_async.h"

// --- Role-specific includes ---------------------------------------------------
#ifdef NODE_GATEWAY
  #include <WiFi.h>
  #include <ESPmDNS.h>
  #include <LittleFS.h>
  #include <Wire.h>
  #include "gateway_state.h"
  #include "gateway_tdma_task.h"
  #include "gateway_web.h"
  #include "gateway_wifi_config.h"
  #include "fram_store.h"
#endif
#ifdef NODE_TELEMETRY
  #ifndef PZEM_FAKE
  #include <PZEM004Tv30.h>
  #endif
  #include "node_tdma_task.h"
#endif

#ifdef PKT_ENCRYPTION
  #include "crypto.h"
  #include "rfid_provision.h"
#endif

// --- Pin definitions (shared) ------------------------------------------------
#ifdef BOARD_S3_SUPERMINI
  // ESP32-S3 Super Mini -- THT pins only (GPIO 1-13, TX=43, RX=44)
  #define LORA_PIN_NSS    4
  #define LORA_PIN_MOSI   5
  #define LORA_PIN_MISO   6
  #define LORA_PIN_SCK    7
  #define LORA_PIN_DIO0   8
  #define LORA_PIN_RST    9
  #define LORA_PIN_DIO1   RADIOLIB_NC
#else
  // ESP32-dev (gateway + non-S3 node, shared layout)
  #define LORA_PIN_NSS    26
  #define LORA_PIN_MOSI   27
  #define LORA_PIN_MISO   14
  #define LORA_PIN_SCK    13
  #define LORA_PIN_DIO0   2
  #define LORA_PIN_RST    4
  #define LORA_PIN_DIO1   RADIOLIB_NC  // DIO1 unused; GPIO27 occupied by MOSI
#endif

// Gateway I2C bus (FRAM MB85RC256V + PN532, shared)
#ifdef NODE_GATEWAY
  #define GW_FRAM_SDA     16   // GPIO16 = UART2 RX
  #define GW_FRAM_SCL     17   // GPIO17 = UART2 TX
#endif

// --- Role-specific pin definitions -------------------------------------------
#ifdef NODE_GATEWAY
  #define GW_BTN_PIN 34   // "The button" -- active LOW, external pull-up required
                          //   short press (< 3 s):   reboot
                          //   long  press (3-10 s):  forget STA credentials + reboot
                          //   hold  (>= 10 s):        factory reset (NVS + FRAM + AES key) + reboot
#endif

#ifdef NODE_TELEMETRY
  #ifdef BOARD_S3_SUPERMINI
    #define PZEM_TX_PIN     43   // ESP32-S3 physical TX -> PZEM RX
    #define PZEM_RX_PIN     44   // ESP32-S3 physical RX <- PZEM TX
    #define RELAY_PIN_      3    // active HIGH; GPIO3 is JTAG strapping -- LOW at boot is safe
    #define LED_GREEN_PIN_  11
    #define LED_RED_PIN_    12
    #define NODE_BTN_PIN    13
  #else
    #define PZEM_TX_PIN     22   // ESP32 TX2 -> PZEM RX
    #define PZEM_RX_PIN     23   // ESP32 RX2 <- PZEM TX
    #define RELAY_PIN_      25   // Relay signal (active HIGH)
    #define LED_GREEN_PIN_  32   // Two-color LED - green channel
    #define LED_RED_PIN_    33   // Two-color LED - red channel
    #define NODE_BTN_PIN    34   // "The button" -- active LOW, external pull-up required
                                 //   short press (< 3 s): reboot (forces re-contend)
                                 //   long  press (>= 3 s): clear encryption key + reboot
  #endif

  // Exported - referenced by node_tdma_task.cpp
  uint8_t RELAY_PIN     = RELAY_PIN_;
  uint8_t LED_GREEN_PIN = LED_GREEN_PIN_;
  uint8_t LED_RED_PIN   = LED_RED_PIN_;
  uint8_t DIO0_PIN      = LORA_PIN_DIO0;
  uint8_t LORA_NSS_PIN  = LORA_PIN_NSS;
#endif

// --- Hardware instances -------------------------------------------------------
// Radio instance - extern-referenced by both gateway_tdma_task.cpp and node_tdma_task.cpp
SX1278 radio = new Module(LORA_PIN_NSS, LORA_PIN_DIO0, LORA_PIN_RST, LORA_PIN_DIO1);

#ifdef NODE_TELEMETRY
  #ifndef PZEM_FAKE
  // PZEM-004T v3 on Serial2 - extern-referenced by node_tdma_task.cpp
  PZEM004Tv30 pzem(Serial2, PZEM_RX_PIN, PZEM_TX_PIN);
  #endif
#endif

// =============================================================================
// GATEWAY
// =============================================================================
#ifdef NODE_GATEWAY

// GPIO 34 is input-only on ESP32 -- no internal pull-up; requires external resistor.
// Press tiers (active LOW):
//   < 80 ms        -- debounce glitch, ignored
//   80 ms - 3 s    -- short press: reboot
//   3 s - 10 s     -- long press: forget STA credentials + reboot
//   >= 10 s         -- factory reset: erase all NVS (wifi-cfg) + FRAM + AES key + reboot
static void btnTask(void*) {
  pinMode(GW_BTN_PIN, INPUT);
  vTaskDelay(pdMS_TO_TICKS(500));  // skip transients during boot
  for (;;) {
    if (digitalRead(GW_BTN_PIN) == LOW) {
      uint32_t t0 = millis();
      while (digitalRead(GW_BTN_PIN) == LOW) {
        if (millis() - t0 >= 10100) break;  // factory reset threshold reached
        vTaskDelay(pdMS_TO_TICKS(20));
      }
      uint32_t held = millis() - t0;
      if (held < 80) { vTaskDelay(pdMS_TO_TICKS(50)); continue; }  // debounce glitch

      if (held >= 10000) {
        logAsync("[GW] Button 10 s hold -- FACTORY RESET: erasing NVS + FRAM, rebooting\n");
        wifiFactoryResetNvs();
        framErase();
#ifdef PKT_ENCRYPTION
        cryptoClearKey();
#endif
      } else if (held >= 3000) {
        logAsync("[GW] Button long-press -- forgetting STA credentials, rebooting\n");
        wifiClearCredentials();
      } else {
        logAsync("[GW] Button press -- rebooting\n");
      }
      vTaskDelay(pdMS_TO_TICKS(400));  // let log drain
      ESP.restart();
    }
    vTaskDelay(pdMS_TO_TICKS(20));
  }
}

void setup() {
  Serial.begin(115200);
  logDrainTaskStart();
  delay(500);
  logAsync("\n===== Power Telemetry Gateway =====\n");

  // -- LittleFS --------------------------------------------------------------
  // Mounts the web SPA (index.html, app.js, etc.) served by the web task.
  // LittleFS.begin(true) formats on mount failure.
  // NVS (WiFi credentials) is unaffected by format.
  if (!LittleFS.begin(true)) {
    logAsync("[FS] LittleFS mount FAILED - dashboard SPA not available\n");
  } else {
    logAsync("[FS] LittleFS OK\n");
    File root = LittleFS.open("/");
    File f = root.openNextFile();
    while (f) {
      logAsync("  /%-30s  %lu B\n", f.name(), (unsigned long)f.size());
      f = root.openNextFile();
    }
  }

  // -- FRAM (MB85RC256V, SDA=GW_FRAM_SDA, SCL=GW_FRAM_SCL, addr=0x50) -------
  // framLoadAll() is called before the TDMA task starts so no mutex is needed.
  // framInit() internally calls Wire.begin(GW_FRAM_SDA, GW_FRAM_SCL).
  if (!framInit(GW_FRAM_SDA, GW_FRAM_SCL, 0x50)) {
    logAsync("[FRAM] Init FAILED - energy/history persistence disabled\n");
  } else {
    logAsync("[FRAM] OK\n");
    framLoadAll();
    framTaskStart();
  }

  // -- Packet encryption (encrypted builds only) ----------------------------
  // cryptoLoadKey() tries NVS; if missing, generate a fresh random key so the
  // gateway is self-contained out of the box.  rfidProvisionInit() prepares the
  // PN532 for web-triggered card writes (POST /api/provision).
  // Wire (SDA=GW_FRAM_SDA, SCL=GW_FRAM_SCL) is already up from framInit();
  // rfidProvisionInit() calls Wire.begin() again with the same pins -- safe and idempotent.
#ifdef PKT_ENCRYPTION
  if (!cryptoLoadKey()) {
    cryptoGenerateKey();
  }
  rfidProvisionInit();
  logAsync("[CRYPTO] Encrypted mode active\n");
#endif

  // -- WiFi - non-blocking state machine ------------------------------------
  // AP starts immediately (last-resort access route). STA attempted in
  // parallel if credentials are saved in NVS.
  //   AP on  -> while STA unavailable (no creds, connecting, or dropped)
  //   AP off -> only while STA actively connected
  // wifiConfigLoop() drives all transitions from loop().
  wifiConfigBegin();

  // -- SX1278 radio ----------------------------------------------------------
  SPI.begin(LORA_PIN_SCK, LORA_PIN_MISO, LORA_PIN_MOSI, LORA_PIN_NSS);
  logAsync("[LORA] Initialising SX1278 ... ");
  int16_t loraState = radio.begin(
    LORA_CHANNELS[0],   // Ch 0 - beacon channel
    LORA_BANDWIDTH,
    LORA_SF,
    LORA_CR,
    LORA_SYNC_WORD,
    LORA_TX_POWER,
    LORA_PREAMBLE_LEN
  );
  if (loraState == RADIOLIB_ERR_NONE) {
    logAsync("OK\n");
  } else {
    logAsync("FAILED (err=%d) - check wiring!\n", loraState);
  }
  radio.setCRC(true);

  // -- Web server ------------------------------------------------------------
  webServerSetup();
  webBroadcastTaskStart();

  // -- TDMA task (Core 1, priority 2) ---------------------------------------
  gatewayTdmaTaskStart();
  xTaskCreate(btnTask, "BTN", 2048, nullptr, 1, nullptr);

  logAsync("[GW] Setup complete.\n");
}

void loop() {
  // Drive the WiFi state machine and DNS server.
  wifiConfigLoop();

  // Periodic 5 s "nodes" WebSocket push + ws.cleanupClients().
  webBroadcastAllNodes();

  delay(10);
}

#endif // NODE_GATEWAY

// =============================================================================
// SENSOR NODE
// =============================================================================
#ifdef NODE_TELEMETRY

// NODE_BTN_PIN is active LOW; GPIO34 (ESP32-dev) is input-only -- external pull-up required.
// GPIO13 (S3 Super Mini) supports internal pull-up.
static void btnTask(void*) {
#ifdef BOARD_S3_SUPERMINI
  pinMode(NODE_BTN_PIN, INPUT_PULLUP);
#else
  pinMode(NODE_BTN_PIN, INPUT);
#endif
  vTaskDelay(pdMS_TO_TICKS(500));  // skip transients during boot
  for (;;) {
    if (digitalRead(NODE_BTN_PIN) == LOW) {
      uint32_t t0 = millis();
      while (digitalRead(NODE_BTN_PIN) == LOW) {
        if (millis() - t0 >= 3100) break;  // long-press threshold reached
        vTaskDelay(pdMS_TO_TICKS(20));
      }
      uint32_t held = millis() - t0;
      if (held < 80) { vTaskDelay(pdMS_TO_TICKS(50)); continue; }  // debounce glitch

      if (held >= 3000) {
        // Rapid red blink -- visual confirmation before clearing key
        for (int i = 0; i < 6; i++) {
          digitalWrite(LED_RED_PIN_, i & 1 ? HIGH : LOW);
          vTaskDelay(pdMS_TO_TICKS(80));
        }
        logAsync("[NODE] Button long-press -- clearing encryption key, rebooting\n");
#ifdef PKT_ENCRYPTION
        cryptoClearKey();
#endif
      } else {
        logAsync("[NODE] Button press -- rebooting\n");
      }
      vTaskDelay(pdMS_TO_TICKS(200));  // let log drain
      ESP.restart();
    }
    vTaskDelay(pdMS_TO_TICKS(20));
  }
}

void setup() {
  Serial.begin(115200);
  logDrainTaskStart();
  delay(500);
  Serial.println("\n===== Power Telemetry Node =====");

  // -- GPIO init -------------------------------------------------------------
#ifndef PZEM_FAKE
  pinMode(RELAY_PIN_,      OUTPUT);
  digitalWrite(RELAY_PIN_, LOW);       // Relay OFF at boot
#endif
  pinMode(LED_GREEN_PIN_, OUTPUT);
  digitalWrite(LED_GREEN_PIN_, HIGH);
  pinMode(LED_RED_PIN_,   OUTPUT);
  digitalWrite(LED_RED_PIN_,   HIGH);

  // -- Packet encryption (encrypted builds only) ----------------------------
  // On first boot (no NVS key) the node blocks here waiting for the operator
  // to tap a pre-written MIFARE card to the PN532 (SDA=PN532_SDA, SCL=PN532_SCL).
  // The red LED blinks while waiting.  After a successful read the node reboots
  // so setup() runs cleanly with the key resident in NVS.
#ifdef PKT_ENCRYPTION
  if (!cryptoLoadKey()) {
    Serial.println("[NODE] NOT PROVISIONED - tap provisioned RFID card to PN532");
    rfidProvisionInit();
    uint8_t rfidKey[16];
    while (true) {
      // Red blink: ON
      digitalWrite(LED_RED_PIN_, LOW);
      if (rfidProvisionRead(rfidKey)) {
        digitalWrite(LED_RED_PIN_, HIGH);
        // Key was already stored by rfidProvisionRead() via cryptoSetKey()
        Serial.println("[NODE] Key loaded from RFID card - rebooting...");
        delay(200);
        ESP.restart();
      }
      // Red blink: OFF
      digitalWrite(LED_RED_PIN_, HIGH);
      delay(400);
    }
  }
  Serial.println("[CRYPTO] Encrypted mode active");
#endif

  // -- SX1278 radio ----------------------------------------------------------
  SPI.begin(LORA_PIN_SCK, LORA_PIN_MISO, LORA_PIN_MOSI, LORA_PIN_NSS);
#ifdef BOARD_S3_SUPERMINI
  // SPI.begin() resets GPIO11/12 (default FSPI pins) to INPUT, clobbering the pinMode above.
  pinMode(LED_GREEN_PIN_, OUTPUT);
  pinMode(LED_RED_PIN_,   OUTPUT);
#endif

  // 3 fast green blinks - boot indicator
  for (int i = 0; i < 6; i++) {
    digitalWrite(LED_GREEN_PIN_, i & 1 ? HIGH : LOW);
    delay(120);
  }
  digitalWrite(LED_GREEN_PIN_, HIGH);
  Serial.print("[LORA] Initialising SX1278 ... ");
  int16_t loraState = radio.begin(
    LORA_CHANNELS[0],   // Ch 0 - listen for beacon
    LORA_BANDWIDTH,
    LORA_SF,
    LORA_CR,
    LORA_SYNC_WORD,
    LORA_TX_POWER,
    LORA_PREAMBLE_LEN
  );
  if (loraState == RADIOLIB_ERR_NONE) {
    Serial.println("OK");
  } else {
    Serial.printf("FAILED (err=%d)\n", loraState);
  }
  radio.setCRC(true);

  // -- PZEM sanity check -----------------------------------------------------
#ifdef PZEM_FAKE
  Serial.println("[PZEM-FAKE] Net-test mode -- skipping PZEM hardware check");
#else
  Serial.print("[PZEM] Checking connection ... ");
  delay(200);
  float testV = pzem.voltage();
  if (!isnan(testV)) {
    Serial.printf("OK (%.1f V)\n", testV);
  } else {
    Serial.println("No response - check wiring (TX/RX swapped?)");
    // pzemTask will keep retrying - non-fatal
  }
#endif

  // -- Launch FreeRTOS tasks -------------------------------------------------
  nodeTdmaTaskStart();
  xTaskCreate(btnTask, "BTN", 2048, nullptr, 1, nullptr);

  Serial.println("[NODE] Setup complete - waiting for beacon.\n");
}

void loop() {
  // All work is in FreeRTOS tasks on Core 1 (TDMA) and Core 0 (PZEM, sched, nudge).
  // loop() runs as the idle context - just yield.
  vTaskDelay(pdMS_TO_TICKS(1000));
}

#endif // NODE_TELEMETRY

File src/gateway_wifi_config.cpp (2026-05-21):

/**
 * gateway_wifi_config.cpp
 *
 * Non-blocking WiFi state machine for the Power Telemetry Gateway.
 *
 * State machine:
 *
 *   AP_ACTIVE --(creds exist at boot / POST /api/connect)--> AP_STA_CONNECTING
 *       ^                                                           |
 *       | STA drops / timeout / forget / disconnect                 | WL_CONNECTED
 *       |                                                           v
 *       +---------------------------------------- STA_CONNECTED (AP off)
 *
 * AP is always on except while STA is actively connected.
 * DNS catch-all redirects all queries to 192.168.4.1 while AP is active.
 */

#include "gateway_wifi_config.h"
#include "gateway_state.h"
#include "log_async.h"
#include "tdma_protocol.h"

#include <WiFi.h>
#include <ESPmDNS.h>
#include <DNSServer.h>
#include <Preferences.h>
#include <LittleFS.h>
#include <ArduinoJson.h>

// -- State -------------------------------------------------------------------------------------
enum WifiState
{
  WIFI_STATE_AP_ACTIVE,         // AP on, no STA
  WIFI_STATE_AP_STA_CONNECTING, // AP on + STA connecting in background
  WIFI_STATE_STA_CONNECTED,     // STA up, AP off
};

static WifiState s_state        = WIFI_STATE_AP_ACTIVE;
static uint32_t  s_connectStart = 0;
static bool      s_apActive     = false;
static bool      s_staConnected = false;
static bool      s_apEventRegistered = false; // guard: register AP_START handler once
static DNSServer s_dns;
static char      s_apSsid[32]   = {};   // "PowerTelemeter_XXXX", built at boot
static String    s_apPassword   = "";   // empty = open network

// -- NTP state ---------------------------------------------------------------------------------
#define NTP_POLL_MS    2000UL       // poll interval while waiting for first sync
#define NTP_RESYNC_MS  3600000UL    // re-anchor millis clock from system time once per hour

static bool     s_ntpSynced    = false;
static uint32_t s_ntpLastCheck = 0;

static int32_t nvsLoadTzOffset()
{
  Preferences p;
  p.begin("wifi-cfg", true);
  int32_t off = p.getInt("tzoff", NTP_UTC_OFFSET_SEC);
  p.end();
  return off;
}

static void nvsSaveTzOffset(int32_t offsetSec)
{
  Preferences p;
  p.begin("wifi-cfg", false);
  p.putInt("tzoff", offsetSec);
  p.end();
}

static void startNtp()
{
  int32_t off = nvsLoadTzOffset();
  configTime(off, 0, NTP_SERVER);
  s_ntpSynced    = false;
  s_ntpLastCheck = millis();
  logAsync("[WIFI] NTP: syncing via %s (UTC%+d)\n",
           NTP_SERVER, (int)(off / 3600));
}

static void stopNtp()
{
  s_ntpSynced = false;
}

static const IPAddress AP_IP(192, 168, 4, 1);
static const IPAddress AP_SUBNET(255, 255, 255, 0);
static const uint8_t   DNS_PORT = 53;

// -- NVS -------------------------------------------------------
static void nvsLoad(String &ssid, String &pass)
{
  Preferences p;
  p.begin("wifi-cfg", true);
  ssid = p.getString("ssid", "");
  pass = p.getString("pass", "");
  p.end();
}

static void nvsSave(const String &ssid, const String &pass)
{
  Preferences p;
  p.begin("wifi-cfg", false);
  p.putString("ssid", ssid);
  p.putString("pass", pass);
  p.end();
}

// Clears only STA credentials; intentionally preserves "appass" and "tzoff".
static void nvsClear()
{
  Preferences p;
  p.begin("wifi-cfg", false);
  p.remove("ssid");
  p.remove("pass");
  p.remove("sip");
  p.remove("sgw");
  p.remove("ssn");
  p.remove("sdns");
  p.end();
}

static String nvsLoadApPassword()
{
  Preferences p;
  p.begin("wifi-cfg", true);
  String pw = p.getString("appass", "");
  p.end();
  return pw;
}

static void nvsSaveApPassword(const String &pw)
{
  Preferences p;
  p.begin("wifi-cfg", false);
  p.putString("appass", pw);
  p.end();
}

void wifiClearCredentials()
{
  nvsClear();
}

void wifiFactoryResetNvs()
{
  Preferences p;
  p.begin("wifi-cfg", false);
  p.clear();
  p.end();
}

// Static IP NVS -- keys sip/sgw/ssn/sdns; all empty = DHCP
static void nvsLoadStaticIp(String &ip, String &gw, String &sn, String &dns1)
{
  Preferences p;
  p.begin("wifi-cfg", true);
  ip   = p.getString("sip",  "");
  gw   = p.getString("sgw",  "");
  sn   = p.getString("ssn",  "");
  dns1 = p.getString("sdns", "");
  p.end();
}

static void nvsSaveStaticIp(const String &ip, const String &gw,
                             const String &sn, const String &dns1)
{
  Preferences p;
  p.begin("wifi-cfg", false);
  p.putString("sip",  ip);
  p.putString("sgw",  gw);
  p.putString("ssn",  sn);
  p.putString("sdns", dns1);
  p.end();
}

static void nvsClearStaticIp()
{
  Preferences p;
  p.begin("wifi-cfg", false);
  p.remove("sip");
  p.remove("sgw");
  p.remove("ssn");
  p.remove("sdns");
  p.end();
}
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

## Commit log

2026-05-08 Major TDMA debug, adjusted SF and TX power to optimize radio footprint
    [Adafruit I2C FRAM.kicad_pcb, gateway.kicad_pcb, gateway.kicad_sch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]
2026-05-14 add esp32-s3 supermini form factor for telemetry nodes
2026-05-14 fix swallowed commands and node persistence
    [node_tdma_task.cpp, tdma_protocol.h]
2026-05-15 various ux tweaks and fixes
    [gateway_wifi_config.cpp, node_tdma_task.cpp]
2026-05-20 updated pcb and schematics
    [Adafruit I2C FRAM.kicad_pcb, gateway.kicad_pcb, telemetry.kicad_pcb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]
2026-05-21 add pdf for gateway
    [gateway.kicad_pcb]
2026-05-28 add pcb images
2026-05-28 add circuit pictures to microcontrollers paper
2026-06-11 EMI hacks so the system recovers faster
    [lora_hal.cpp, main.cpp, node_tdma_task.cpp]
